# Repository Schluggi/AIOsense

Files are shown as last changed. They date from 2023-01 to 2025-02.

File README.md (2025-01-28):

# AIOsense







## Description
Based on the idea of an all-in-one sensor AIOsense was born.

The goal is to provide you with a sensor that is modular, affordable and
easy to solder (no SMD) as an alternative for commercially available sensors. We
also focus on upgrade-ability, so you don't have to buy all parts again in case
of a new PCB release. In most cases, this sensor is cheaper and better than the
commercially ones. 

## Available Sensors / Modules

- (RGB)-LED
- Barometer
- Breath VOC equivalent
- Buzzer / Beeper
- CO² equivalent
- Humidity sensor
- Light / Illumination sensor
- PIR motion sensor
- Temperature sensor
- mmWave / Radar sensor

**Coming soon:**
- Full Voice Assistant support
- Microphone
- Speaker

All supported sensors & modules are listed in the documentation:
[Sensor Modules](https://aiosense.readthedocs.io/en/latest/sensors/)

## What does it look like? 👀

| Without lid | With lid |
|---|---|
|  |  |

> **Note:** The PCB in this image is not fully equipped either is this the final case
> design ([issue](https://github.com/Schluggi/AIOsense/issues/9)).

### Rendered images

| 3D | 2D |
|---|---|
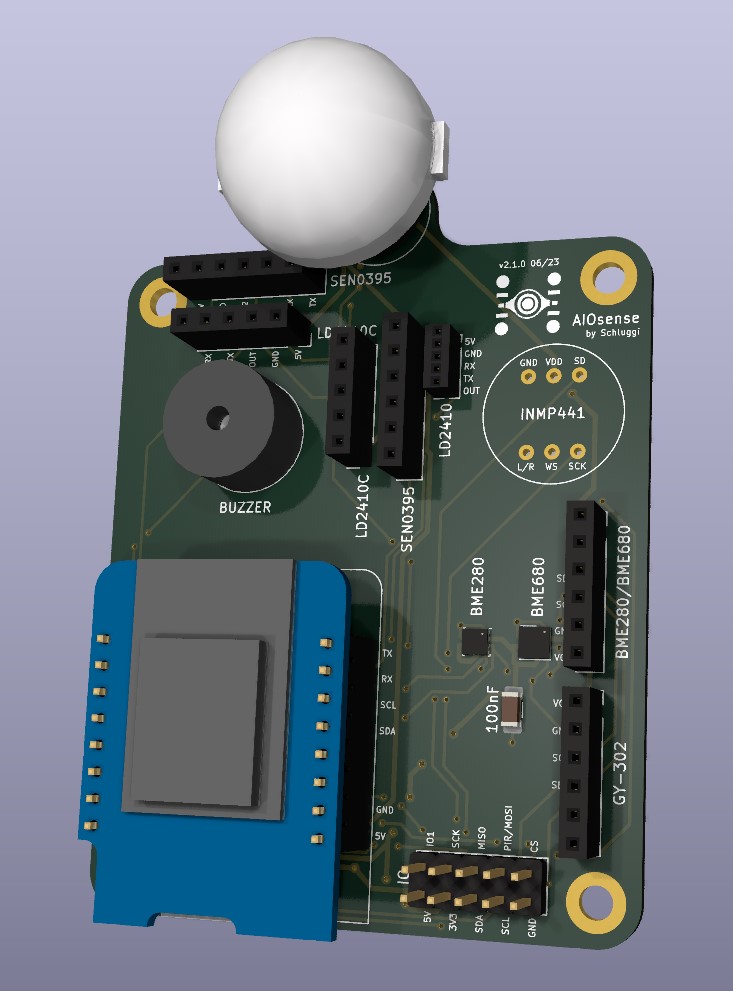
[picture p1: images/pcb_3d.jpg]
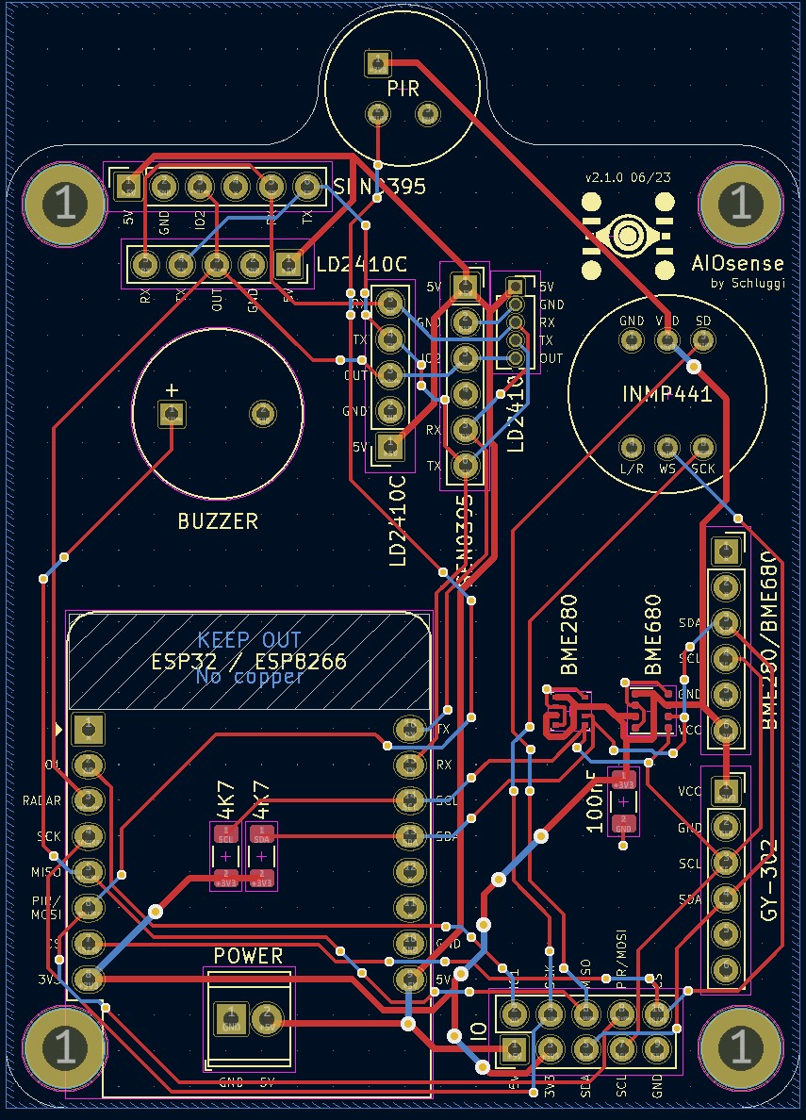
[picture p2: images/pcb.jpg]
|  |  |

### Schematic

You can find the schematic [here](schematic/AIOsense.pdf).

## Power consumption

The power consumption depends on your configuration. On a fully equipped Board (ESP32-C3 + mmWave + PIR + BME280 +
LightSensor) we measured an idle power consumption of **0.45W / 0.09A** some peaks around **0.78W / 0.15A**.

Without a mmWave sensor the idle power consumption is around **0.11W / 0.02A** and peak near **0.45W / 0.09A**.

## How to start

You want to make your own AIOsense?<br>
Let's jump right into the [documentation](https://aiosense.readthedocs.io/en/latest/quickstart/).

## Questions?

Just open an [issue](https://github.com/Schluggi/AIOsense/issues/new) :)

## Credits & Special thanks

Created and maintained by Lukas Schulte-Tickmann / [Schluggi](https://github.com/Schluggi).

### Special thanks
- My dad for some electrical engineering advice and PCB reviewing
- [lukas-holzner](https://github.com/lukas-holzner) for the case design and some general discussions about the board
- [jankae](https://github.com/jankae) for PCB reviewing
- [reschandreas](https://github.com/reschandreas) for general repo work
- [PCBWay³](https://pcbway.com/g/DFb536) for sponsoring the PCB prototypes

### Contributors
<a href="https://github.com/Schluggi/AIOsense/graphs/contributors">
  
</a>

<br>

Inspired by [EverythingSmartHome](https://everythingsmarthome.co.uk/).

<hr>
³ Affiliate link

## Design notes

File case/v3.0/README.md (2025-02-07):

# README

Please note that the ball joint components have been adapted from [Open Source Universal Ball Joint (to reuse!)](https://www.thingiverse.com/thing:4739696) and [Ball Joint Speaker Mount](https://www.thingiverse.com/thing:5429153). These models have been licensed under the [Creative Commons - Attribution - Share Alike](https://creativecommons.org/licenses/by-sa/3.0/) license.

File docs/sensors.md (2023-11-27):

# Sensors

The AIOsense PCB support and hand full of modular sensors. Chose any sensor you
want but notice the compatibility.

<hr>

## 🌡️Temperature, Humidity, Pressure, VOC & Air Quality

For these measurements we recommend the industrial sensors BME680/BME688 or the
BME280 (cheaper but without air
quality).

Please notice that you can either use the BME280 **or** the BME680 out of the
box (there have the same I²C address).

If you can solder SMD components you can solder them directly onto the PCB.
Please notice that you will need and solder
these three more components: 2x 4K7 resistor (THT), 1x 100nF capacitor (also
SMD). Also important to know: It's not
recommended to solder the BME680 with hot air because this can damage the air
quality sensor. Use a hotplate instead.

Related to [#7](https://github.com/Schluggi/AIOsense/issues/7) sometimes SMD
soldering can be inaccessible or difficult.
You can use a BME PCB module instead.

The default offset is -6 °C. 

### Where to buy?

| Part | Shops |
|---|---|
| BME280 (PCB module) | [Amazon DE³](https://amzn.to/3KXklmd), [AliExpress](https://de.aliexpress.com/wholesale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) |
| BME280 (SMD) | [Reichelt](https://www.reichelt.de/kombo-sensor-luftdruck-luftfeuchtigkeit-temp--bme-280-p159825.html), [Mouser](https://www.mouser.de/ProductDetail/Bosch-Sensortec/BME280?qs=2OnyuXx6vpj2fK9HX7qb3g%3D%3D), [Digi-Key](https://www.digikey.de/de/products/detail/bosch-sensortec/BME280/6136306) |
| BME680 (PCB module) | [Amazon DE³](https://amzn.to/41y0XmS), [AliExpress](https://de.aliexpress.com/wholesale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) |
| BME680 (SMD) | [Reichelt](https://www.reichelt.de/kombo-sensor-luftdruck-luftfeuchtigkeit-temp-gas-bme-680-p159835.html), [Mouser](https://www.mouser.de/ProductDetail/Bosch-Sensortec/BME680?qs=v271MhAjFHjo0yA%2FC4OnDQ%3D%3D), [Digi-Key](https://www.digikey.de/de/products/detail/bosch-sensortec/BME680/7401317) |

### Compatibility

This sensor is fully compatible with any other sensor or module. You can only
choose _one_ BME module and loses one
generic I²C port if you choose an PCB module.

<hr>

## 💡Illuminance (Light)

You want to turn the light on by motion but only when it's necessary? So you
want to know, how bright it is? We
recommend the really cheap GY-302 BH1750 PCB.

### Where to buy?

| Part | Shops |
|---|---|
| BH1750 | [Amazon DE³](https://amzn.to/3oAc6Vy), [AliExpress](https://de.aliexpress.com/wholesale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) |

### Compatibility

This sensor is fully compatible with any other sensor or module but uses one of
the two generic I²C slots. If you want
to use the official 3D printed case you have to connect it to the lower slot.

<hr>

## 🎙️Microphone

> **WARNING**: Not supported yet! The mic uses some SPI pins. If you want to use
> the mic you **can not** use any
> generic device connected to the these IO-header pins: CS, SCK, MISO as well as
> any SPI based sensor at all.

We designed the board while having the future in mind. So the idea to have a
microphone in each room for a voice
assistant would be awesome. Unfortunately, ESPHome does not support this
yet ([ESPHome feature request](https://github.com/esphome/feature-requests/issues/1254)).
This in mind we can't test
this at all but Open Home (the company behind ESPHome and Home Assisant)
just [release there plans](https://www.youtube.com/watch?v=D936T1Ze8-4) for 2023
and mention that there is hope this
will be implemented in the upcoming year.

The AIOsense PCB is designed to work only with INMP441-modules which are known
for their high quality digital audio.

### Where to buy?

| Part | Shops |
|---|---|
| INMP441 | [Amazon DE³](https://amzn.to/40y8twJ), [AliExpress](https://de.aliexpress.com/wholesale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) |

### Compatibility
> **AIOsense v2.1.0**: This sensor is fully compatible with any other sensor or module besides the buzzer. Please disconnect the buzzer first. 

<hr>

## 🧍Presence (mmWave/radar)

Never heard before? It's a fancy technology to recognize the smallest
movements (like a motion sensor/PIR but really
sensitive). This is useful in situations you want to track if someone is present
even if the person is not really moving
for example while watching TV or sleeping.

The board is mainly made for the
SEN0395 [datasheet](https://wiki.dfrobot.com/mmWave_Radar_Human_Presence_Detection_SKU_SEN0395).
There are two sockets
for this sensor. Feel free to choose yourself which one do you prefer. It's just
the orientation. There is no difference
between these two, and you can't use both sockets at the same time.

Shortly before release of V2.0 someone asked to support the much cheaper module
HLK-LD2410 [datasheet](https://drive.google.com/drive/folders/1p4dhbEJA3YubyIjIIC7wwVsSo8x29Fq-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).
So I added a socket. This module is also supported in ESPHome but currently
there is no demo config available from our
side. So [build it yourself](https://esphome.io/components/sensor/ld2410.html).

### Where to buy?

| Part | Shops |
|---|---|
| SEN0395 (recommended) | [Mouser](https://www.mouser.de/ProductDetail/DFRobot/SEN0395?qs=ljCeji4nMDmvEgq75EdCVA%3D%3D), [Farnell](https://de.farnell.com/en-DE/dfrobot/sen0395/mmwave-radar-board-arduino-board/dp/3879712), [Digi-Key](https://www.digikey.de/de/products/detail/dfrobot/SEN0395/14322660?s=N4IgTCBcDaIMoFEByAGAzATgKwgLoF8g) |
| HLK-LD2410 | [AliExpress](https://de.aliexpress.com/item/1005004351593073.html) |
| HLK-LD2410C | [AliExpress](https://de.aliexpress.com/item/1005005047841163.html) |

### Compatibility

This sensor is fully compatible with any other sensor or module, but you can
only use one of them so choose wisely.

<hr>

## 🚶Motion Sensor (PIR)

You want a classic motion sensor? No problem. We support an industrial standard
EKMC1603111 ([Datasheet](https://www3.panasonic.biz/ac/ae/search_num/index.jsp?c=detail&part_no=EKMC1603111)).
Every
other 3V PIR sensor with an TO-5 3-pin socket should work as well (but is
untested).
Please notice that you will need an TO-5 3-pin socket as well (in any case)!

### Where to buy?

| Part | Shops |
|---|---|
| EKMC1603111 | [Voelkner](https://www.voelkner.de/products/994091/Panasonic-PIR-Bewegungssensor-EKMC1603111-3-6V-1St..html), [Mouser](https://www.mouser.de/ProductDetail/Panasonic-Industrial-Devices/EKMC1603111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), [Farnell](https://de.farnell.com/en-DE/panasonic-electric-works/ekmc1603111/sensor-motion-12m-white/dp/2095731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), [Digi-Key](https://www.digikey.de/de/products/detail/panasonic-electric-works/EKMC1603111/2601880), [RS-Online](https://de.rs-online.com/web/p/naherungssensoren-ics/1357081) |
| TO-5 3-pin socket | [Mouser](https://www.mouser.de/ProductDetail/Mill-Max/917-43-103-41-005000?qs=teNCaa%2FZ3auQVxVMs%2F5ihg%3D%3D), [Digi-Key](https://www.digikey.com/en/products/detail/mill-max-manufacturing-corp/917-43-103-41-005000/1212170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) |

### Compatibility

This sensor is fully compatible with any other sensor or module.

## 🔊 Piezo Buzzers

This is a passive buzzer which can create music in different frequencies.

### Where to buy?

| Part | Shops |
|---|---|
| Piezo Buzzer | [Amazon DE³](https://amzn.to/3n0aFza), [Mouser](https://www.mouser.de/ProductDetail/CUI-Devices/CEM-120342?qs=WyjlAZoYn50KzVdoYfaqpA%3D%3D) |

> Please notice the pinout of 6.5mm and a max height of 8.5mm. Otherwise, the
> buzzer will not fit

### Compatibility

This module is fully compatible with any other sensor or module besides
HLK-LD2410. The HLK-LD2410C however will work fine.

<hr>
³ Affiliate link

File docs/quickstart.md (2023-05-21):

# Quickstart



> **Note:** You can also buy AIOsense as a kit
> on [tindie](https://www.tindie.com/products/gadgetgarage/aiosense/).

## Order PCB

(https://www.pcbway.com/project/shareproject/AIOsense_All_In_One_Sensor_132c1507.html)

First of all you need the PCB. We recommend PCBWay because it's the most
straight forward experience and the quality is excellent. Just click on the link
and take your order (you can also use [this link³](https://pcbway.com/g/DFb536)
for register to get 5$ off on your first order). But you can actually choose any
PCB manufacturer. Please notice that not all of them have the same capabilities.
We tried to make our PCB as generic as possible, it should work for most of them
but try this at your own risk.

- [PCBWay³](https://www.pcbway.com/project/shareproject/AIOsense_All_In_One_Sensor_132c1507.html)
- [Aisler](https://aisler.net/p/TWDRHBSM)

For all other manufacturer (like [JLCPCB](https://jlcpcb.com/)) please upload
the zip file which you can find at
the [release](https://github.com/Schluggi/AIOsense/releases/latest) page.

## Order parts

Now that you have the PCB, we still need the remaining parts. There is a
separate [BOM (Bill Of Materials)](https://github.com/Schluggi/AIOsense/tree/main/bom)
for
each AIOsense version. Open the pdf file and order all green marked lines.

You can get most parts from sellers
like [Mouser](https://www2.mouser.com/), [Farnell](https://www.farnell.com/)
or [Digi-Key](https://www.digikey.com/). Direct links to the sensors can be
found [here](sensors.md).

Please make sure you pick the right BME680 module. It should look like
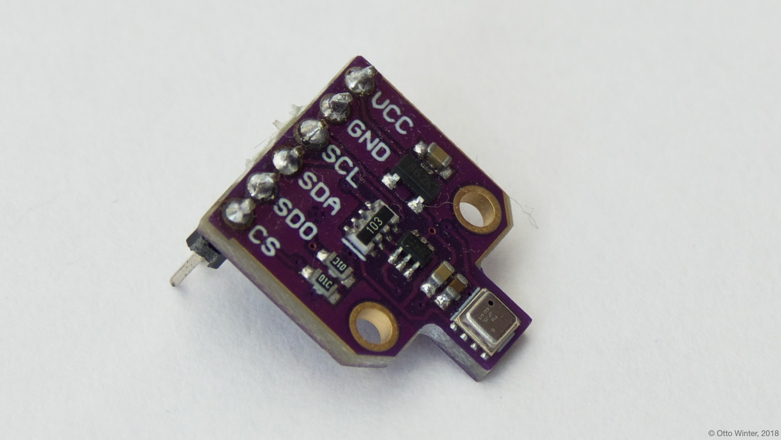
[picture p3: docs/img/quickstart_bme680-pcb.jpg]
bme680-pcb
this: {: style="height:50%;width:
50%"}

More info about the BOM and what the groups are all about can be
found [here](bom.md).

## Assembly (wip)

Should be easy and self explainable.

## Flashing Firmware

Now you have a fully assembled AIOsense but how can you integrate this in
Home Assistant?

### Installing the ESPHome dashboard

> This will only work for _Home Assistant OS_ and _Supervised_. For all other
> versions please use the
> [docker image](https://esphome.io/guides/getting_started_command_line.html#)
> or install it [manually](https://esphome.io/guides/installing_esphome.html).

First we need an ESPHome Dashboard. The best way to get one is by using the
official Home Assistant add-on.

Therefore, we go to our Home Assistant instance and click
on `Settings -> Add-ons`:

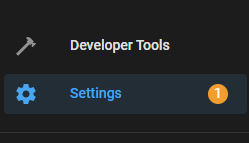
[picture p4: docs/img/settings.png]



We can find the `ADD-ON STORE` in the bottom right corner:



We are looking for the ESPHome add-on (without beta and dev) and install it.
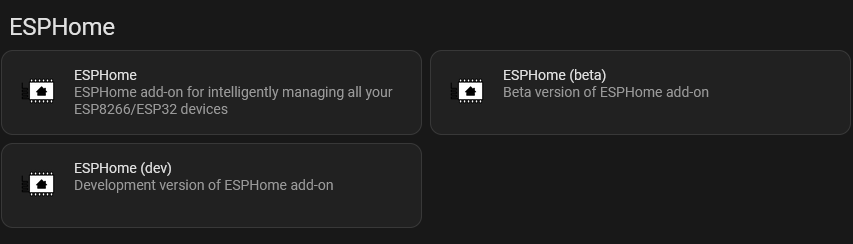
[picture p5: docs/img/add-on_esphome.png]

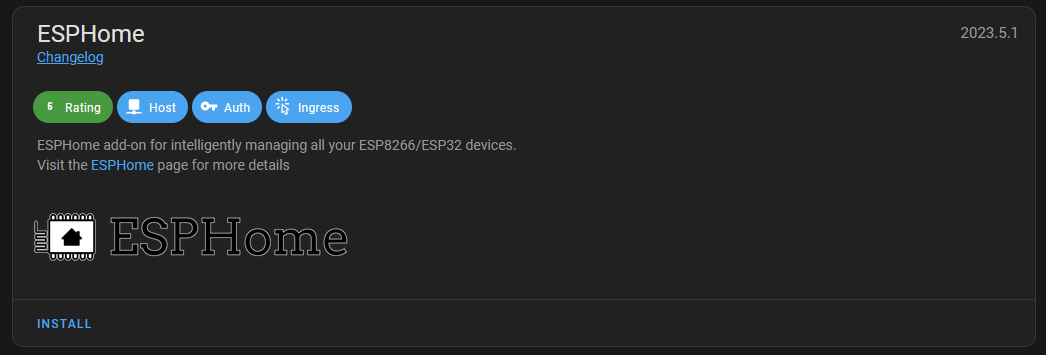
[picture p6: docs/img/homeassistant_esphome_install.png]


The installation can take several minutes, so please be patient. Afterward we
enable `Start on boot`, `Auto update` and `Show in sidebar`.


We can now open our dashboard by clicking on it at the sidebar:
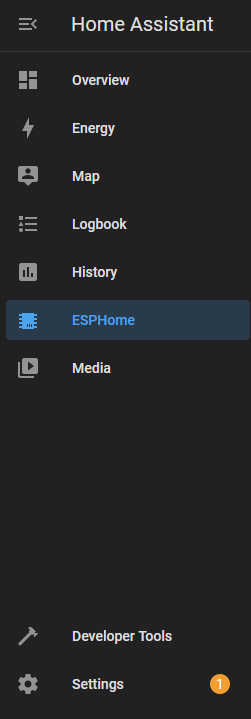
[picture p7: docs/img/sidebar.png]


### Flashing

With an open dashboard we can now flash our device, but first we need some
configuration.

Click `New Device` and fill out the form:

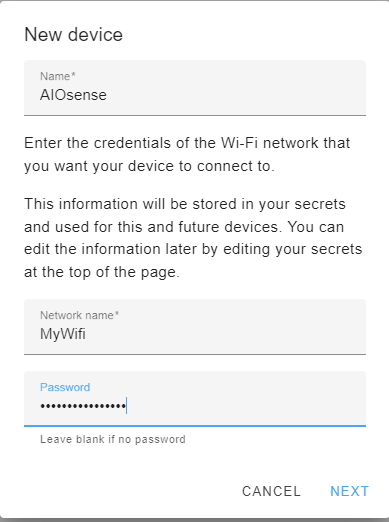
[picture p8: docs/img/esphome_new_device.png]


Skip the installation on the second screen and choose the ESP32-C3.

We don't need the encryption key yet. Skip it.

Our device is now displayed on the dashboard. You need to change the
configuration. Click `EDIT`.

This is the configuration that will be flashed onto your device. We need nothing of
this but the api encryption key and the ota password so copy/save these values
for later.

Replace the hole file with the content of
[this](https://github.com/Schluggi/AIOsense/blob/main/esphome/esphome.yaml)
file and replace both `<secret>` values with your saved ones and change lines
2-4 to the name you pick earlier.

Everything changed? Great! If not already done, connect the board via USB to
your PC, click `INSTALL` in the top right corner and
select `Plug into this computer` as flashing method.

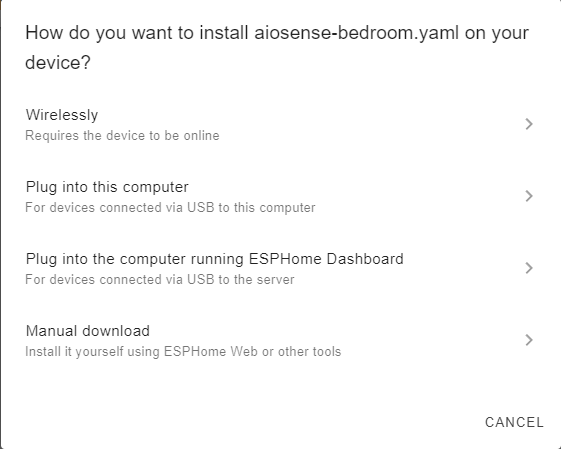
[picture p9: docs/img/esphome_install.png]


> This will only work on a Chromium based browser. For all other browser please
> take a look how to flash manually

A popup will ask for the COM port. Select the port of the board and click
`Connect`.

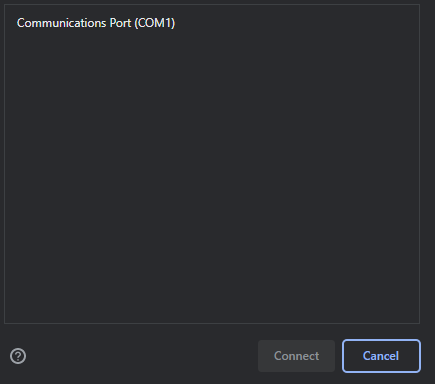
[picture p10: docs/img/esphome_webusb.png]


Your browser will now connect to your board and flash it. This can take several
minutes. The blue circle will spin without any additional feedback. Be patient.

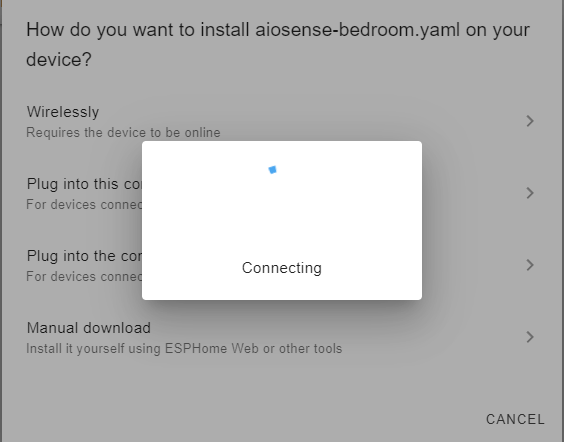
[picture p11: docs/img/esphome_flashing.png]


Your AIOsense is now ready to use

## Home Assistant Integration (wip)

...

## Further steps (optional)

- [Print a case](case.md)

<hr>
³ Affiliate link

My PCB prototypes are sponsored by PCBWay.

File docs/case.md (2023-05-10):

# Case

We and our communtiy desigend a few 3D printable cases.

| AIOsense | Author | Link | Note |
|---|---|---|---|
| v2.x.x | [MeisterGig](https://github.com/MeisterGig) | [Printables](https://www.printables.com/de/model/477959-aiosense-case-official) | **Official Case**, no heat inserts or screws needed ([#9](https://github.com/Schluggi/AIOsense/pull/9)) |
| v2.x.x | [cadriel](https://github.com/cadriel) | [Printables](https://www.printables.com/de/model/477959-aiosense-case-official) | Remix of the official case, screws needed ([#9](https://github.com/Schluggi/AIOsense/issues/9#issuecomment-1513696294)) |
| v1.0 | [s-gordon](https://github.com/s-gordon) | [Repo](https://github.com/Schluggi/AIOsense/tree/main/case/v1.0/stl) | [#16](https://github.com/Schluggi/AIOsense/pull/16) |

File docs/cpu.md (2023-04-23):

You can use any ESP32 mini or ESP8266 mini with the correct pinout, but we highly recommend the ESP32-C3.

| | ESP32-C3 (recommended) | ESP32 | ESP32-S2 | ESP8266 |
|---|---|---|---|---|
| USB-Type | Type-C | micro-USB | Type-C | micro-USB or Type-C |
| Bluetooth | &check; | &check; | &check; | &cross; |
| Bluetooth LE | &check; | &check; | ? | &cross; |
| Case | &check; | &cross;(not yet) | &check; | &check; |
| external power¹ | &check; | &check; | &check; | &cross; |
| LED | WS2812B RGB | White | White | White |
| fits perfectly  | &check; | [stands over](https://github.com/Schluggi/AIOsense/issues/15#issuecomment-1399424459) | &check; | &check;¹ |
| Where to buy? | [AliExpress](https://de.aliexpress.com/item/1005004740051202.html?gatewayAdapt=glo2deu) | [Amazon DE³](https://amzn.to/3Loijgf), [AliExpress](https://de.aliexpress.com/item/32858054775.html) | [AliExpress](https://de.aliexpress.com/item/1005003145192016.html?gatewayAdapt=glo2deu) | [Amazon DE³](https://amzn.to/43ZNANZ), [AliExpress](https://de.aliexpress.com/item/32529101036.html) |

¹ External power via the terminal connectors are not possible if the USB-connector is at the bottom (ESP8266).

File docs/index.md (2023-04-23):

# AIOsense documentation



Welcome to the [AIOsense](https://github.com/Schluggi/AIOsense) documentation.

If you miss some information or spot something wrong / outdatet feel free to create
an [issue](https://github.com/Schluggi/AIOsense/issues/new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).

Start with our [quickstart](quickstart.md) guide.

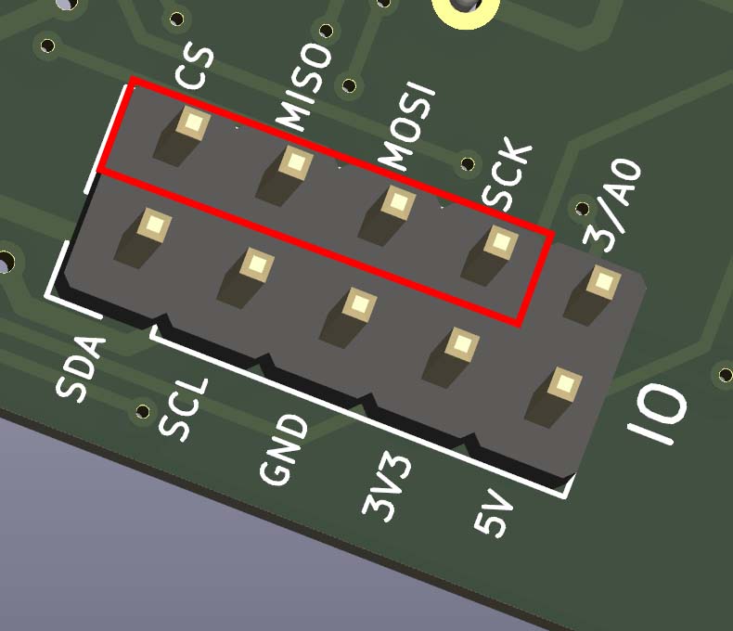
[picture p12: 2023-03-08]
images/docs/io-spi.jpg

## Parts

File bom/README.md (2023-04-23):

# BOM (Bill of Material)

Please take a look at our [docs](https://aiosense.readthedocs.io/en/latest/bom)
for complete BOM explanation. There is also
a [quickstart guide](https://aiosense.readthedocs.io/en/latest/quickstart/).

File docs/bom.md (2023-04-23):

# BOM (Bill Of Materials)

You can find the BOM [here](https://github.com/Schluggi/AIOsense/tree/main/bom).

You can get most parts from sellers
like [Mouser](https://www2.mouser.com/), [Farnell](https://www.farnell.com/)
or [Digi-Key](https://www.digikey.com/). Direct links to the sensors can be
found [here](sensors.md).

## Quickstart recommendation

Some lines in the BOM are marked green. This is our quickstart recommendation.
So if you don't know what do you really need and what is optional, just buy all
parts that are marked green, and you will end with an uncompromising AIOsense.

## Groups

Some parts in the BOM have a group letter. These are alternative options. So
please choice only one part within one group. For example both mmWave sensors
are in group `M`. So you have to pick one of them and can't use both at the same
time.

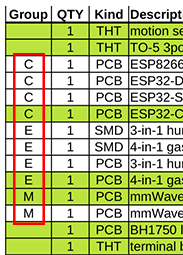
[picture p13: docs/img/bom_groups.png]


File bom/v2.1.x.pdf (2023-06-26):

AIOsense

https://github.com/Schluggi/AIOsense

BOM for v2.1.x only
Please take a look at our docs for complete BOM explanation
Group | QTY | Kind | Description | Note | Manufacturer | SKU
| 1 | THT | motion sensor / PIR | - | Panasonic | EKMC1603111
| 1 | THT | TO-5 3pos socket | - | Mill-Max | 917-43-103-41-005000
C | 1 | PCB | ESP8266-D1 mini | - | Wemos | Lolin D1 mini
C | 1 | PCB | ESP32-D1 mini | - | (many) | -
C | 1 | PCB | ESP32-S2 mini | - | Wemos | Lolin S2 mini
C | 1 | PCB | ESP32-C3 mini | - | Wemos | Lolin C3 mini
E | 1 | SMD | 3-in-1 humidity sensor | - | Bosch | BME280
E | 1 | SMD | 4-in-1 gas sensor | - | Bosch | BME680
E | 1 | PCB | 3-in-1 humidity sensor | - | (many) | BME280
E | 1 | PCB | 4-in-1 gas sensor | - | (many) | BME680
M | 1 | PCB | mmWave radar sensor | - | DFROBOT | SEN0395
M | 1 | PCB | mmWave radar sensor | - | Hi-Link | HLK-LD2410
M | 1 | PCB | mmWave radar sensor | - | Hi-Link | HLK-LD2410C
| 1 | PCB | BH1750 light sensor | - | (many) | GY-302
| 1 | THT | terminal block 2pos, 2.54mm pin spacing, 8.5mm case height | - | Würth Elektronik | 691210910002
| 2 | SMD | 4.7 kohm resistors, ± 5%, 1206, 250 mW | only if group E is SMD | YAGEO | RC1206JR-074K7L
| 1 | SMD | multilayer ceramic capacitor, 0.1 µF, 50 V, ± 10%, 1206, X7R | only if group E is SMD | YAGEO | CC1206KRX7R9BB104
| 4 | THT | 1x6-way vertical socket (female), 2.54mm, 8.5mm height | - | MULTICOMP PRO | 2212S-06SG-85
| 2 | THT | 1x8-way vertical socket (female), 2.54mm, 8.5mm height | normaly part of the CPU order | MULTICOMP PRO | 2212S-08SG-85
| 1 | THT | 2x5-way vertical header (male), 2.54mm | - | MULTICOMP PRO | 2213S-10G
| 2 | THT | 1x5-way vertical socket (female), 2.54mm, 8.5mm height | for HLK-LD2410C only | MULTICOMP PRO | 2212S-05SG-85
| 1 | THT | 1x5-way vertical socket (female), 1.27mm, 4.6mm height | for HLK-LD2410 only | Harwin | M52-5000545
| 1 | THT | Piezo Buzzers, 12mm radius, 8.5mm height, 6.5mm pinout | - | CUI Devices | CEM-1203(42)
| 1 | PCB | microphone | not supported yet | (many) | INMP441

THT

SMD
PCB

The green color indicates the parts you need for a fully equipped PCB if you want plug and play (quickstart recommendation).

stands for "Through-Hole Technology". Electronic components with leads inserted in holes, soldered on opposite side. Soldering is done via A soldering iron. TLDR; easy to solder.
stands for „Surface Mount Device“. Electronic components mounted directly onto circuit board surface using solder paste and reflow Soldering. Soldering is done using a hot air or reflow soldering machine. TLDR; difficult to solder.
stands for „Printed Circuit Board“. In this case THT based circuit boards. Sometimes called „pcb modules“. TLDR; easy to solder.

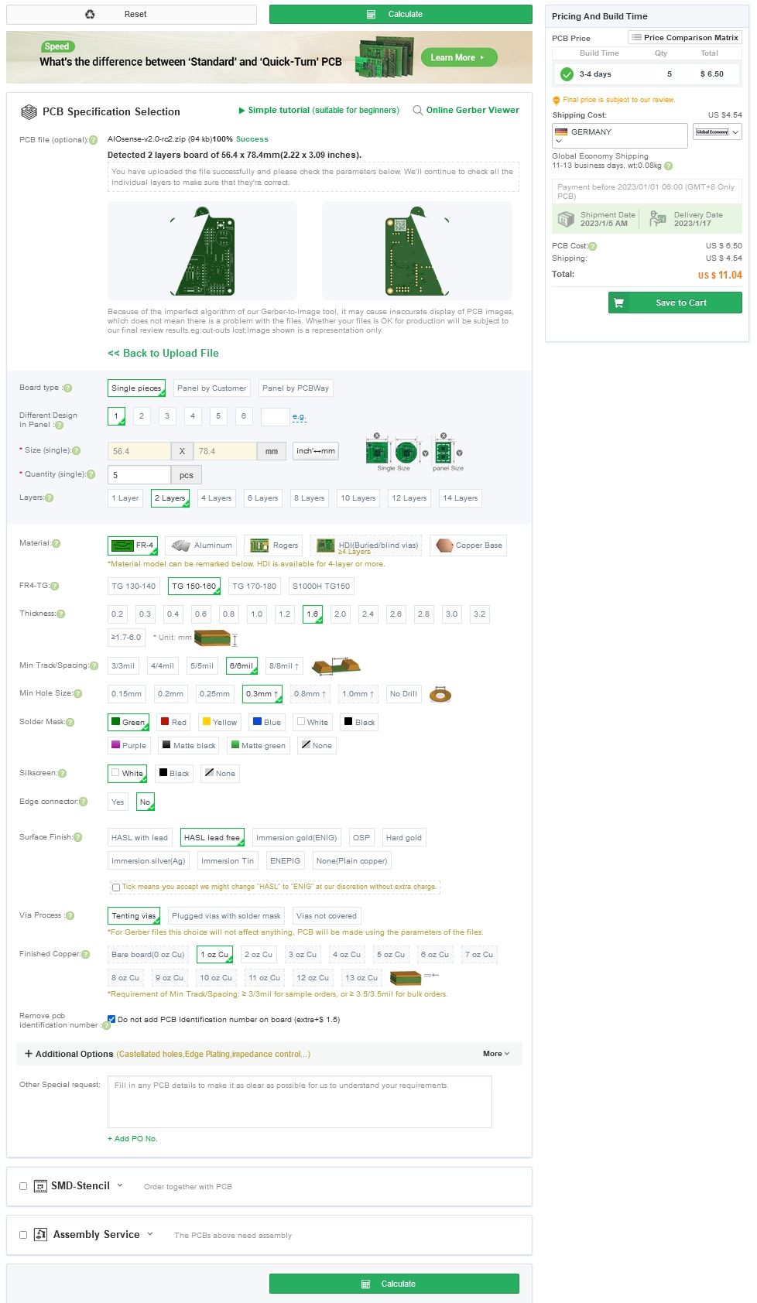
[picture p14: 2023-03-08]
images/docs/order_pcbway.jpg

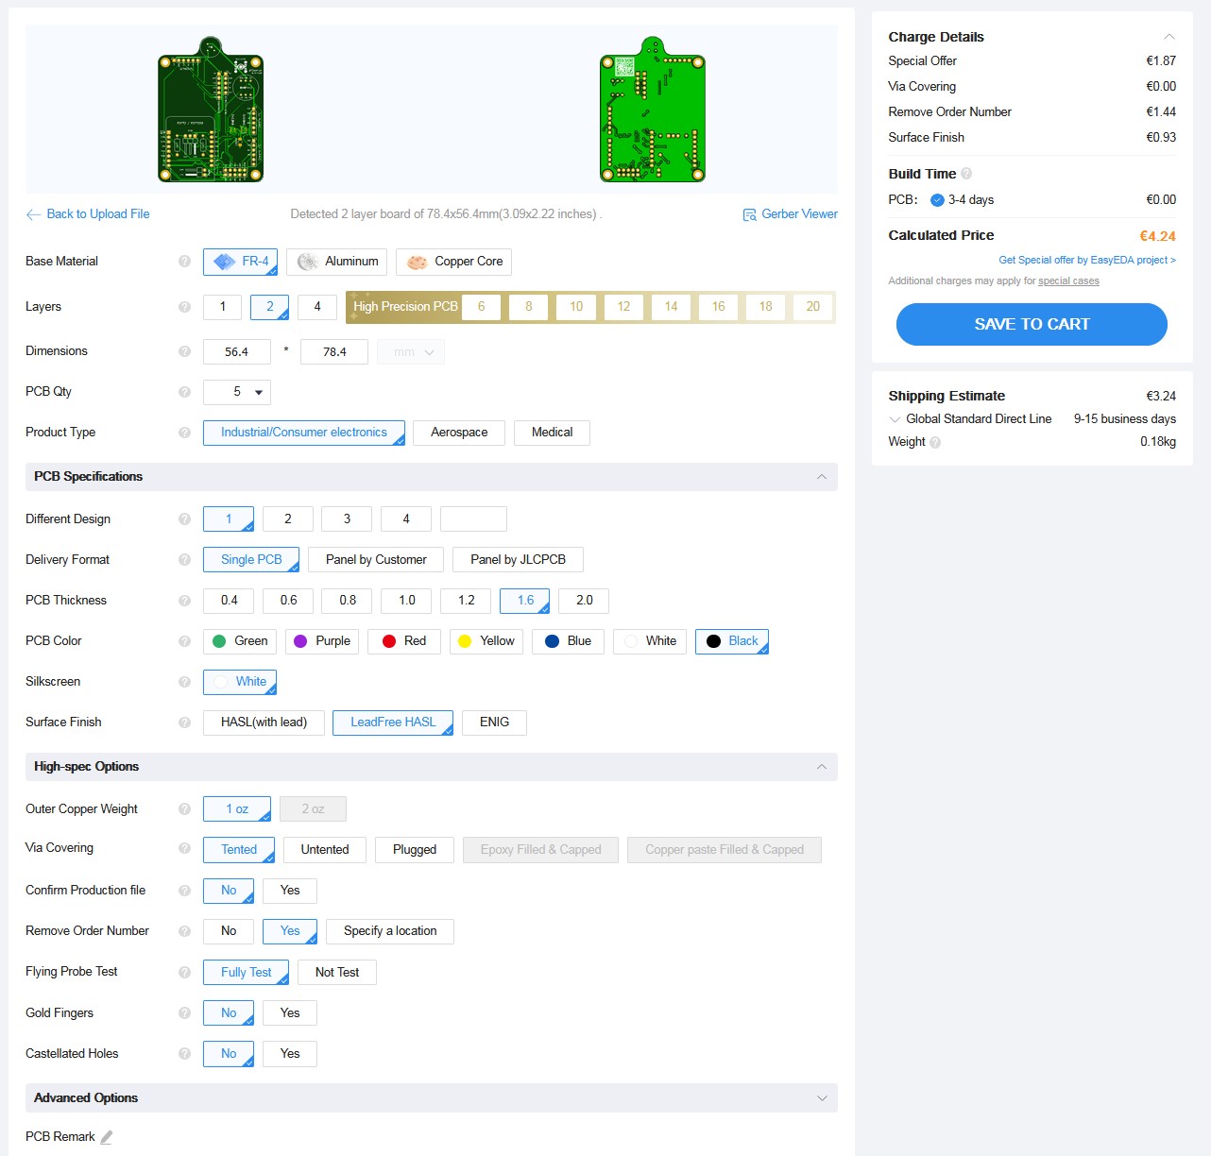
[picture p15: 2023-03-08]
images/docs/order_jlcpcb.jpg

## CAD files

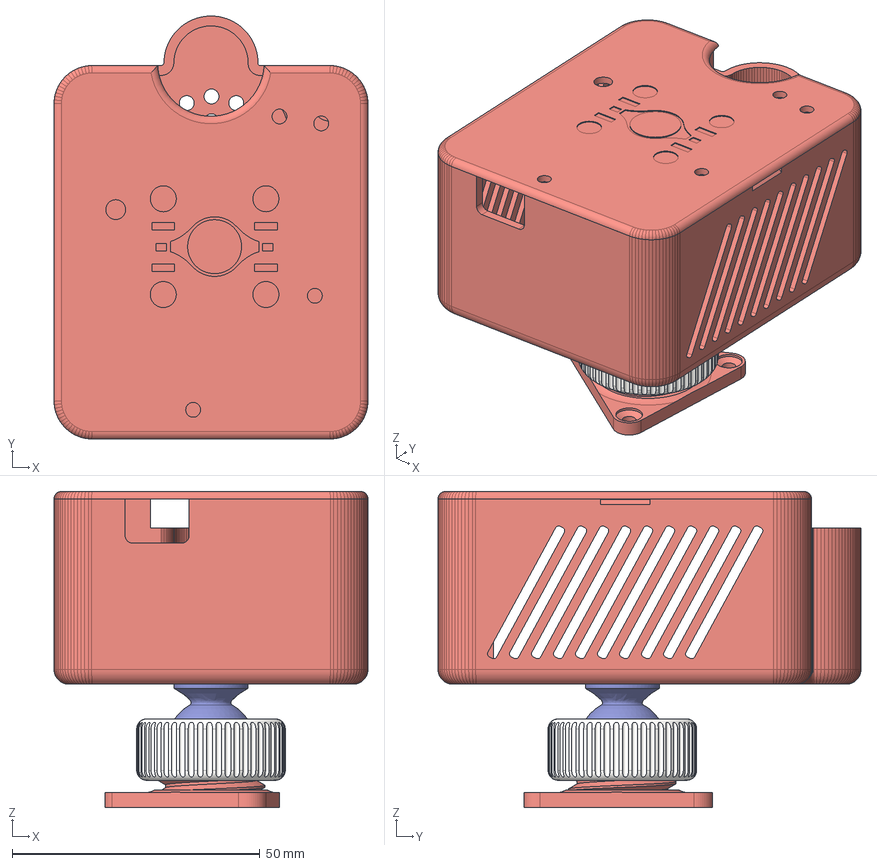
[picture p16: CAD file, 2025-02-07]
case/v3.0/step/case.step
63.4 x 85.4 x 63.8 mm
Ball
Bottom
Lid

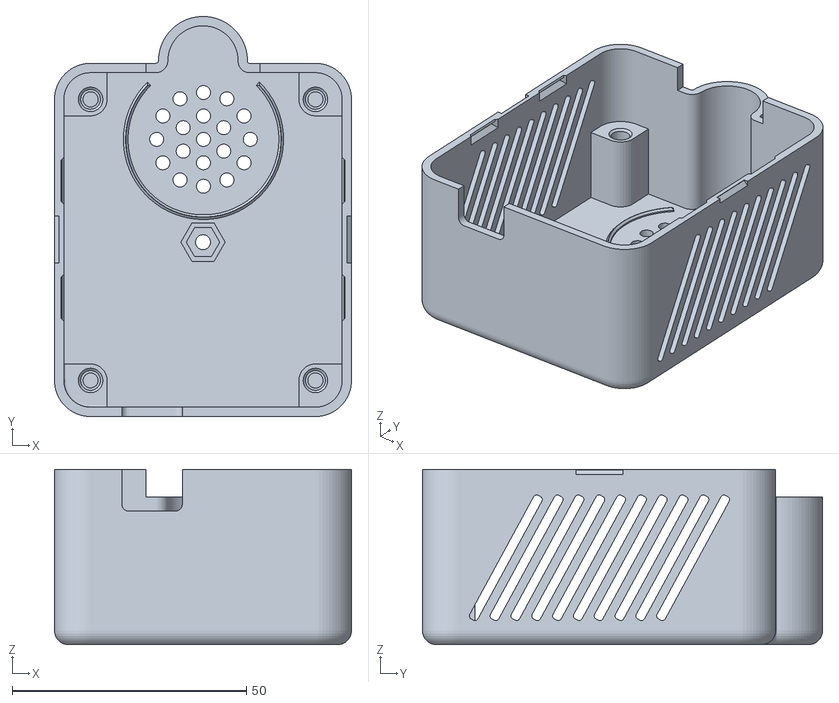
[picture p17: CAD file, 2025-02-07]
case/v3.0/stl/bottom.stl
63.4 x 85.4 x 37.4

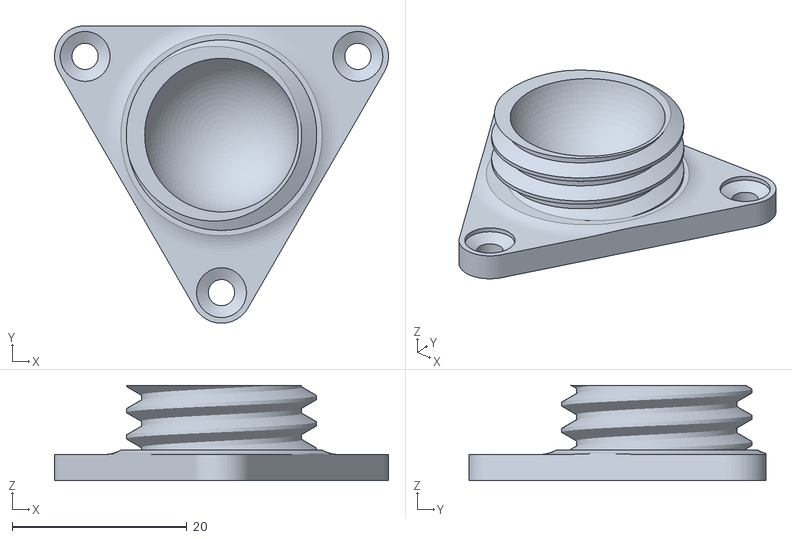
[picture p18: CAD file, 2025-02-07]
case/v3.0/stl/ball_base.stl
38.2 x 34.0 x 10.9

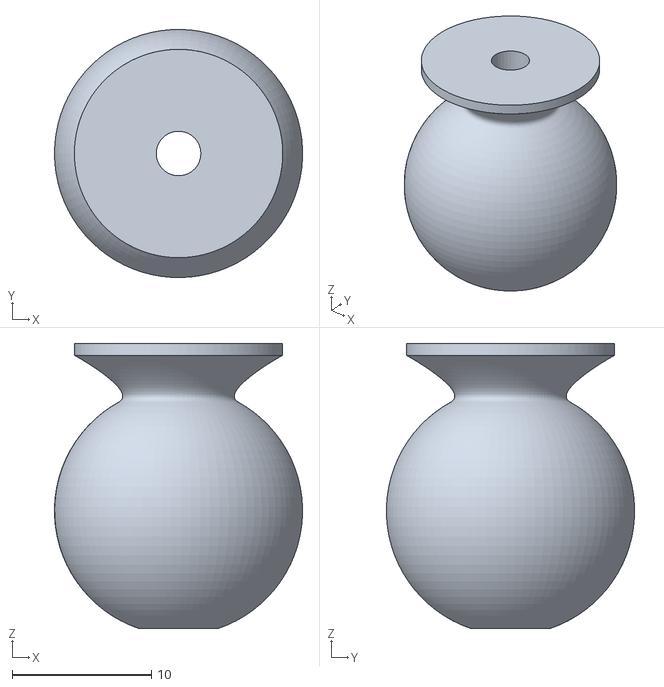
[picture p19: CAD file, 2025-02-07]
case/v3.0/stl/ball.stl
17.8 x 17.8 x 20.4

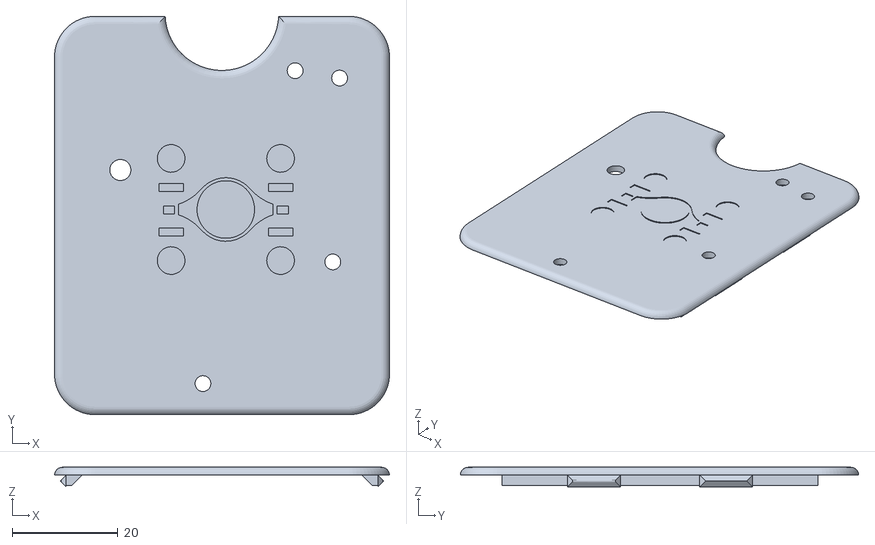
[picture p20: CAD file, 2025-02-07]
case/v3.0/stl/lid.stl
63.4 x 75.4 x 3.70

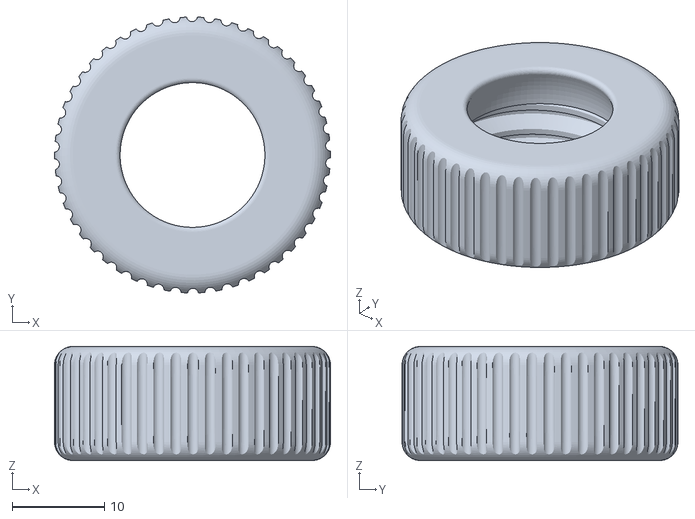
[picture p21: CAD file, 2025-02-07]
case/v3.0/stl/nut.stl
30.0 x 30.0 x 12.4

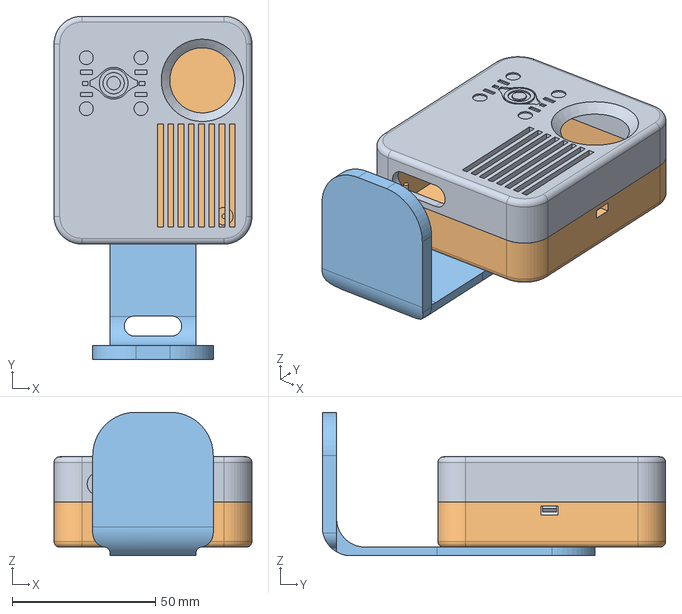
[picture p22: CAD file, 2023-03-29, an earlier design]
case/v1.0/step/case.step
69.0 x 119.7 x 50.0 mm

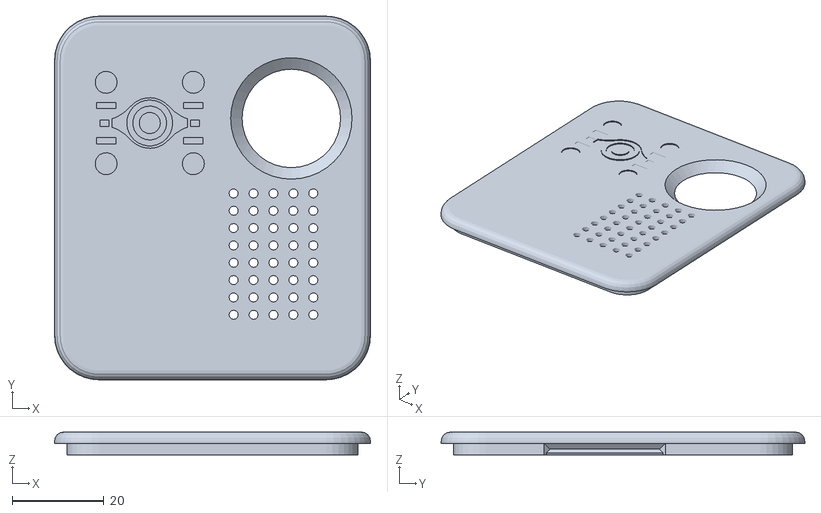
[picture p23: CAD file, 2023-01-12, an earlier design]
case/v1.0/stl/top.stl
69.0 x 79.4 x 5.00

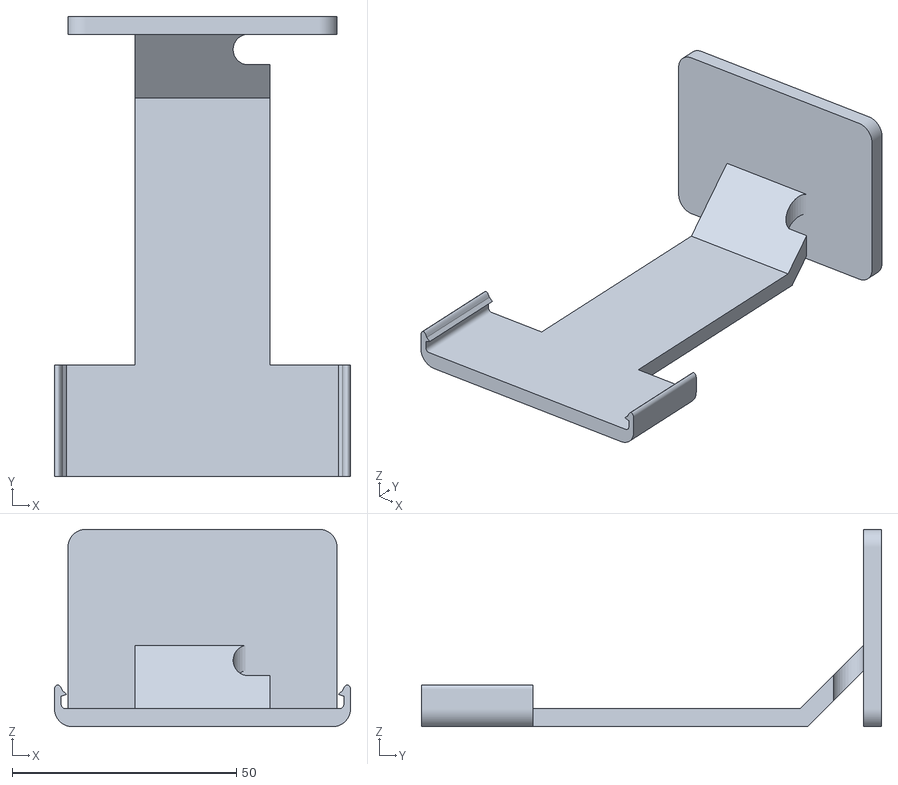
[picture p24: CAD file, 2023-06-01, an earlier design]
case/v2.0/stl/case_upright_stand.stl
66.0 x 102.5 x 44.0

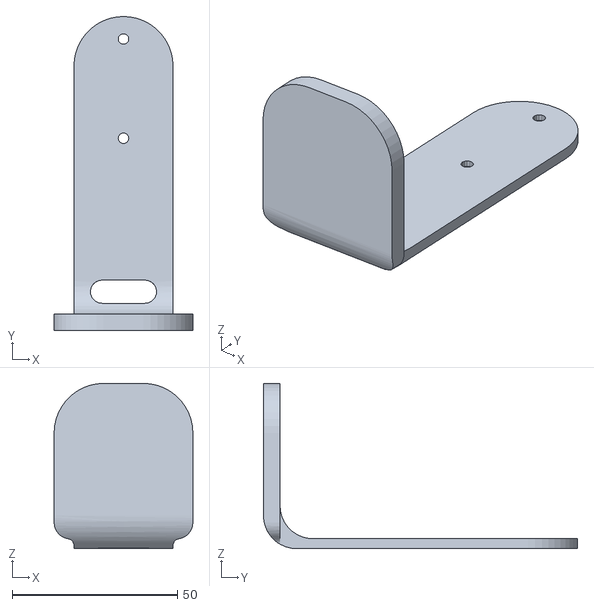
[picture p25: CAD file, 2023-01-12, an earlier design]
case/v1.0/stl/stand.stl
42.0 x 95.0 x 50.0

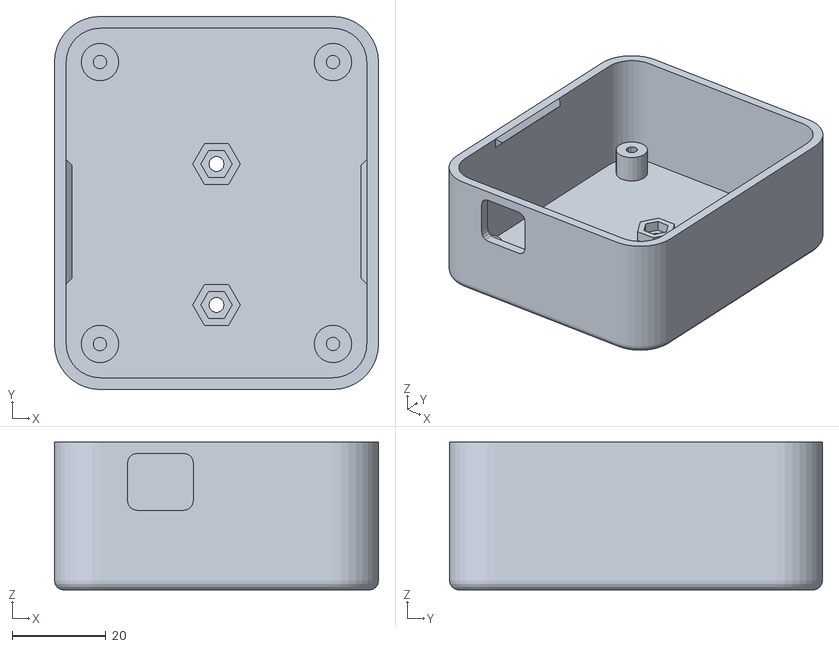
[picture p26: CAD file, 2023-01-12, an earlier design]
case/v1.0/stl/bottom.stl
69.0 x 79.4 x 31.5

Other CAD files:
case/v2.0/blender/case_upright_stand.blend

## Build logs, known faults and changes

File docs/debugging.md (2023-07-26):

# Debugging

## Inconsistent I²C readings

### I²C frequency

A first quick fix could be to choose a lower I²C frequency. In some cases this
can already help to improve consistently
readings. You can do this by tweaking your yaml file and add a `frequency`.

```yaml
i2c:
  frequency: 10kHz  # (defaults to 50kHz)
```

### Too many pull-up resistors ([#44](https://github.com/Schluggi/AIOsense/issues/44))

We need I²C pull-up resistors to make I²C to work. But since every module has
their own pull-ups, we're ending up with
too many pull-ups which can resolve in bad readings. This normally only happens
if you had soldered the two 4K7 Ohm
resistors and using the BME-Module (not the SMD version) as well as the
Light-Module.

The fix is easy: Remove both 4K7 Ohm resistors from the PCB.

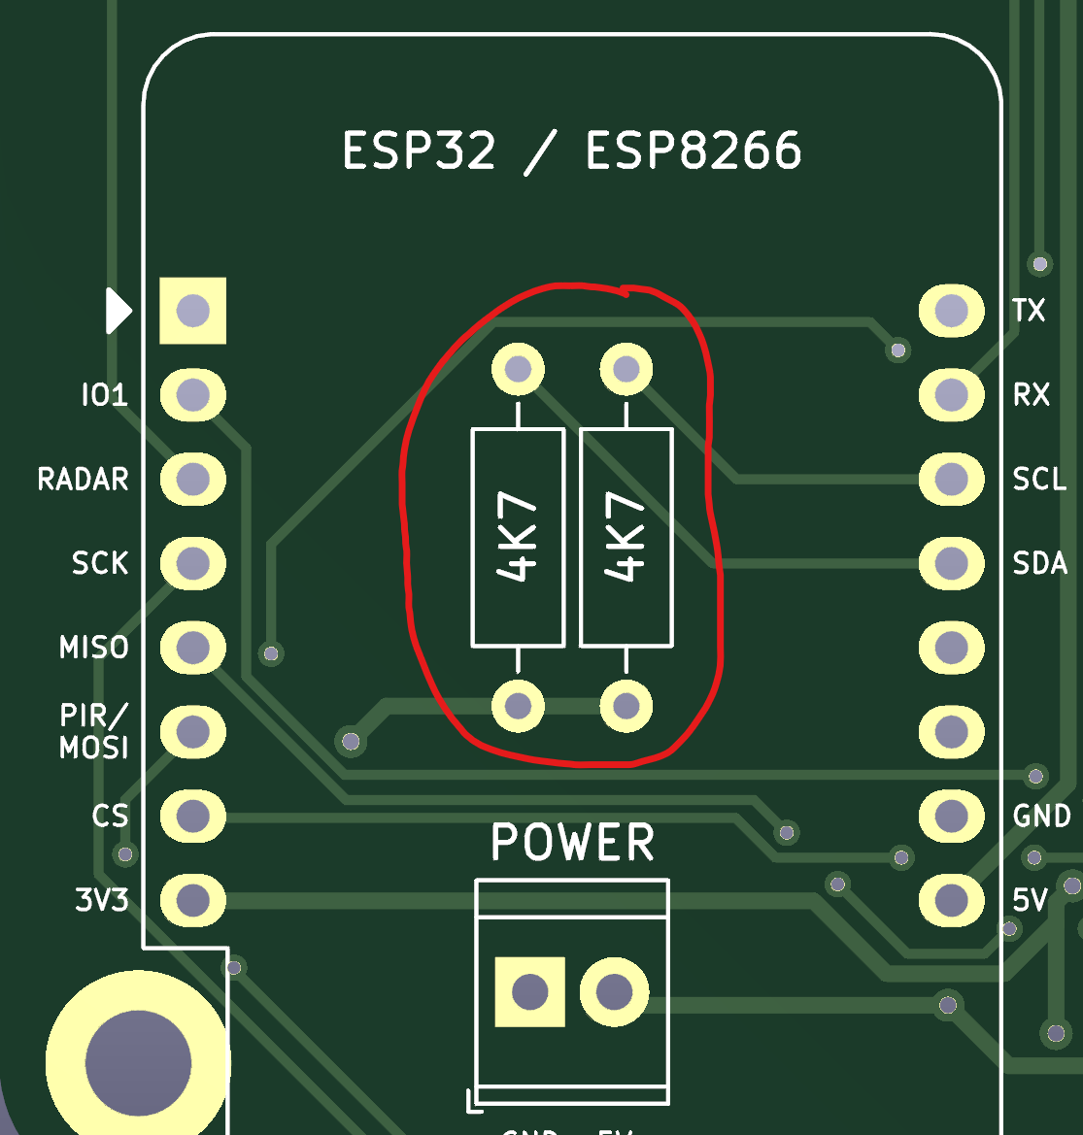
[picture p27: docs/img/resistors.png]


## LD2410(c) does not work

Some versions of LD2410 and LD2410C behave somewhat peculiarly. If your ESP
cannot establish a connection to the mmWave module, it may help to swap the RX
and TX pins contrary to their labeling. To do this, simply adjust your ESPHome
config accordingly.

```yaml
# In this example, the pins are already swapped.
substitutions:

  # ESP32-C3 mini
  uart_rx_pin: GPIO21
  uart_tx_pin: GPIO20

  # ESP32-D1 mini
  uart_rx_pin: GPIO1
  uart_tx_pin: GPIO3

  # ESP32-S2 mini
  uart_rx_pin: GPIO39
  uart_tx_pin: GPIO37

  # ESP2866-D1 mini
  uart_rx_pin: GPIO1
  uart_tx_pin: GPIO3
```

Source: https://github.com/esphome/issues/issues/4317#issuecomment-1474937332

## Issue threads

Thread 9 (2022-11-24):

Design a 3D printable case for v2.0.x and v2.1.x

Schluggi, 2022-11-24:

s-gordon, 2022-12-31:
Great work on the project all. I've actually designed a 3D-printable case for the board. Let me know if you're interested and I'd be happy to share.

MeisterGig, 2022-12-31:
Hey @s-gordon,
we are also working on a Case for v2.0. I haven't posted it yet, since the PCB footprint is still not totally final. We are soon going to order an other batch of PCBs and hope to have a final version with case, to release.
In the meanwhile, here is a link to the WIP Case. https://cad.onshape.com/documents/0970230d187b540faa10c45f/w/4e628c030e78246416c5e857/e/a4e55bb6f45b9b87b321fa69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

The case is supposed to have an assortment of mounting options available, which can be extended apon.

If you have a case for V1, please feel free to open a pull request so we can also offer an option for that. I am also open to improvement ideas :)

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

MeisterGig, 2022-12-31:
TODOs for the case until the release:
- [ ] Adjust to new footprint
- [ ] Make it thinner
- [ ] Get more light to the light sensor (might be solved by making the case thinner)
- [ ] Have a drawing for measurements for the mounting plate

cptbucky, 2023-03-20:
Excited for this, will get a 3d printer when it's ready to go 😁

cadriel, 2023-03-27:
It'd be great to see some further progress here;

- The lid doesn't appear to have a way  to attach to the case.
- The standing mount requires supports. It'd be better to have this printable without supports in some way.

MeisterGig, 2023-03-28:
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

The lid has ha notch which locks into place when pushing it in. And Yes the standing mount still needs support.

I have been refining the design after the official release of the V2.0 board. I'll follow up with further information soon.

afp316, 2023-03-30:
@Schluggi @MeisterGig Thank you for taking the time and effort to create this project.

I printed the WIP V2 case to trial fit.  Good news is that the board fit in the case perfectly.
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

I know that it's still in progress but just wanted to provide some feedback.  The lid doesn't have an interference fit so it won't stay in place without some kind of adhesive.  The corner wall mount should also be scaled a bit down to allow for a snap fit.

Did anyone else have issues or am I doing something wrong on the printing side of things?

Thanks!

MeisterGig, 2023-03-30:
Hey @afp316 ,
Thank you for your input :)  I also encountered problems with the lid. I inverted the notch on the lid and the case after the v2.0 rc1 because it was making it harder to get the board in and out of the case. I haven't  been able to get it as nicely  fit together as the previous version yet. Also i have resized the case recently and might have forgotten the mounts.

I'm gonna share some design considerations and problems i have encountered so far:
- The case should be modular
- It needs to have good ventilation for the bme both smd and recently also as a module (still working on that one )
- the light sensor needs to be as close to the lid as possible otherwise it won't get enough light or i need giant hole
- I personally like heat insert, but it was requested to not need any screws or heat inserts, because it looks bad and insert might be hard to get
- the PCB is very modular so it's hard to design a one size fits all case
-  the PCB should be easily taken out of the case
- when the case is closed it should fit securely inside the case
- pin headers have different hights (i have encountered 7, 8 an 8.5 mm versions)
- ESP8266 have there ports monted on the bottom esp32 on the top
- some people might want to supply power using the scre terminals below the mcu (i don't like a giant hole in the bottom)
- long pins on the lid to hold the board in place break off easily as to many screless locking mechanisms
- it should also look good

I was discussing with @Schluggi to maybe enforce one size of pin header and also maybe use heat inserts to mount the PCB. What are your thoughts on this :)

cadriel, 2023-03-30:
- Most of the pin headers i've encountered are 8.5mm. I don't think I've ever had anything else less than that.
- The more BOM items you add, the harder it is for people to source. Heat Inserts are a bit more difficult to find than screws. I've seen a bunch of cases that use screws as an option so it might be worth considering if you're having trouble. Remember - you can screw into plastic without the need of a heat insert, too.

IMO - It's going to be super hard to meet the needs of every single variation.

If you standardise the pin headers at 8.5mm (this seems the most common option) and start with supporting the recommended `S3` mcu - along with both the smd and pcb modules - then once you've sorted that, move on to variations. Perhaps you provide multiple case options for the different MCU's for example - rather than trying to create a "one case fits all" scenario.

Here's an example case that uses two self tapping screws. It uses little nubs at the bottom of the case to hold the PCB in place, and might provide some inspiration. :)
https://www.printables.com/model/380943-wled-wemos-shield-case-pcb-v3

afp316, 2023-03-30:
@MeisterGig I also like heat inserts but @cadriel makes an excellent point regarding sourcing and logistics.  I can confirm that I have the 8.5 mm headers measured with calipers.  Perhaps standardizing to a header spec would make the case design have one less variable (among many variables that you have dealt with).

As someone who doesn't really mess with SMD, I would think it's more accessible to design around the cheap breakouts that most amateurs buy (like myself).

I haven't looked at the datasheet for the light sensor or experimented with translucency effects on the sensor but perhaps a single layer/single wall would be able to satisfy the light sensor requirements for the application.  It may be such that the final recommendation is to print with certain colors of filaments for the lid.

In line with @cadriel thought, designing around a base set of recommended hardware will help with the design decisions immensely.  I'm sure you already know that considering I'm a late addition to this party. 🎉

cadriel, 2023-03-30:
Yep. Also - the light sensor doesn't necessarily need a whole bunch of light. I think its more important that the light exposure is consistent - and that you let SOME light in. I have other light sensor devices that only provide small holes to meet that requirement.

cadriel, 2023-03-31:
Oh - @MeisterGig  - the example case design I posted would help with some of your other concerns too. The base of the case is shallow - so adding / removing the PCB is very easy. The top of the case is inverted when compared to your current design, which provides other benefits too.

MeisterGig, 2023-04-11:
So I have adjusted a few details. The lid should now be able to snap onto the case again (if it needs too much force please tell me). There are many options variabilized (still a WIP), so adjustments can be made by changing the variables. At the moment I have set them to use 8.5 mm standoffs, a esp32 c3 mini and m3 heat set inserts (to change to screw, change the variable mounting_hole to fit your screw). The standing mount should now be printable without using supports. Unfortunatly I am currently unable to print  the case, so if someone else is able to do so feel free and give feedback. https://cad.onshape.com/documents/0970230d187b540faa10c45f/w/4e628c030e78246416c5e857/e/0f1cd3ab0062a4366c4b0a6d
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
cadriel, 2023-04-17:
Hrm, is sandwiching the the processor against some foam going to cause overheating issues? I suspect the spec for the C3 may warrant specific spacing for airflow..

cadriel, 2023-04-18:
I've created a case and published it on printables.com
https://www.printables.com/model/456377-aiosense-case

This works well for me in the mean time! Feel free to use.

MeisterGig, 2023-04-18:
@Schluggi and I have done some Improvements tonight.

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

- The lid naps in easier @afp316. The mounts also fit better now (Cornermount, wall mount and camera Mount now fit very well)
- We moved the logo to the side which looks nicer.
- The LED now has a hole as well

We think we can get rid of the foam all together by holding the back of the esp in place with a bar coming down from the lid.

Also the standing mount doesn't print properly without support. Im gonna split it into two parts.

I am optimistic these improvements will be finished this week. The case will then released to the repo and thingiverse/printables.

afp316, 2023-04-18:
@cadriel Thanks for sharing your work!

@MeisterGig @Schluggi nice work all around.  I really like the changes you describe, especially the idea of the standoff coming off the lid to apply some pressure.

I can work on modeling a simple spacer to keep the mmwave sensor (the cheaper HLK-LD2410) from moving around freely.  Not sure if y'all are experiencing the same with your HLK's or maybe my tiny headers are junk.  I am using [these](https://www.ebay.com/itm/154730133714?var=454822447335).

MeisterGig, 2023-04-18:
@afp316 that would be great. I think i'm the only other person so far, who has an HLK for this project. I have soldered them directly to the board because I didn't bother to find pin headers yet. Of course it would be great to have them.

afp316, 2023-04-20:
I made an initial mount for the HLK-LD2410 to help a bit with keeping the pcb more secure.

[https://cad.onshape.com/documents/1a4aaa3e005976151241c26c/w/5e7ad8b8b7f30e1bc78c6254/e/c07d0c7cadc1cc9efcf0446a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](url)

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

I think I can do better than this so I'm going to try to use the thru holes for the SEN0395 to design a more compact and secure mount.

riweston, 2023-05-13:
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

Have you put together any additional case mount options aside from the corner mount? The case is great fit and I'm just trying to work out a good way to place it now and I don't really want to wall mount and have a cable trailing up the wall

Schluggi, 2023-05-13:
> Have you put together any additional case mount options aside from the corner mount? The case is great fit and I'm just trying to work out a good way to place it now and I don't really want to wall mount and have a cable trailing up the wall

Yes there is. But we are not happy yet. The clip for holding the case is to lose if you print this flat without support. So we need to adjust this in the future. But feel free testing.

[Mounts - Standingmount.zip](https://github.com/Schluggi/AIOsense/files/11469288/Mounts.-.Standingmount.zip)

riweston, 2023-05-13:
I modified the STL slightly and basically just copied the measurements for the clip er 'nubbins' from the existing corner bracket on printables, I'd say it could be a tighter fit but this seems pretty secure (like I can aggressively shake it without the aiosense falling out)

[Mounts - Standingmount_riweston.zip](https://github.com/Schluggi/AIOsense/files/11469681/Mounts.-.Standingmount_riweston.zip)

Schluggi, 2023-05-31:
@riweston I just printed your version of the stand and I have to say, I'm a big fan :)
Printable without support and a nice tight fit.

With your consent I would love to share this on printables as part of the [official case](https://www.printables.com/de/model/477959-aiosense-case-official/files). I can link your github or printables profile as well. May I? If yes, I would love to have the onshape link to your version or a copy of the design as a file, since everything should be Open Source :)

Thank you!

riweston, 2023-05-31:
Oh great! Glad to hear it's a good fit :)

I just moved a few vertices around on the existing design really but help to take credit 😂

Very happy to share the project file. I'll check the file size tomorrow and assuming it's not too big I'll raise a PR if that suits you?

Closed 2023-05-10.

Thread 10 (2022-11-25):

Add Support for Low Cost mmWave Sensor(HLK-LD2410)

MeisterGig, 2022-11-25:
I found a low cost mmWave Sensor on Ali Express, https://de.aliexpress.com/item/1005004786874722.html
[Datasheet](https://github.com/ESPresense/ESPresense/files/9189632/HLK-LD2410.user.manual.V1.02.pdf)
I haven't tried it yet, but if it works, it might be worth to add pin headers for it, for being able to produce a low cost version of the AIOsense

Schluggi, 2022-11-25:
Sure...

Triskae, 2023-02-15:
I received 3 of theme today, I have to order a V2 board to try, @Schluggi do you have some boards home to test ?

Schluggi, 2023-02-15:
V2 boards yes. But no HLK-LD2410. Moreover is there no esphome config yet for these modules. But feel free and play around. Would be nice if you could create a PR if it's working for you :)

Triskae, 2023-02-15:
Can I email you about that ? I can send you a HLK-LD2410, or you can you send me a V2 board ? Instead of having to wait for it to be manufactured by JLCPCB ? :) I'll pay for the board and the ship costs of ! (I'm in france, we are almost neighbors xD

s-gordon, 2023-03-07:
@Schluggi @Triskae Some input from me here. I picked up a couple of HLK-LD2410s and had an earlier iteration of the V2 board to test these on (RC2, I think). I needed to use an adapter from the 0.05" pins of the LD2410 to the 0.1" female header on the board.

ESPHome support was added in [2023.02](https://esphome.io/changelog/2023.2.0.html) and the device page can be found [here](https://esphome.io/components/sensor/ld2410.html). After some tinkering with the config I have this working perfectly. I'll share pics and the config here when I have a sec.

koloodziej, 2023-03-07:
LD2410C has 0.1" pins but another pin layout. Can you make make PCB for that?
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

Schluggi, 2023-03-08:
> ESPHome support was added in [2023.02](https://esphome.io/changelog/2023.2.0.html) and the device page can be found [here](https://esphome.io/components/sensor/ld2410.html). After some tinkering with the config I have this working perfectly. I'll share pics and the config here when I have a sec.

@s-gordon
Awesome! Thank you for the update. I did not notice the ESPHome update yet. Feel free to create a PR to expand our ESPHome files :)

-----

> LD2410C has 0.1" pins but another pin layout. Can you make make PCB for that?

@koloodziej I'm sure we could implement this in v2.1. Could you create a separate issue for that? Links for buying also welcome.

Triskae, 2023-03-13:
@s-gordon Great, that's some good news !! Thanks a lot for the update !

Closed 2023-03-08.

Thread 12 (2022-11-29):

Switch to SMD instead of THT for all BME related components

Schluggi, 2022-11-29:
Both resistors and the capacitor are only for the BME chips. These chips can only soldered by using a heatgun or a heating plate.
So everyone who hasn't access to this kind of equipment will use a BME module instead and does not need to solder these parts.

So there is no need to make this parts consumer friendly (alias THT).

Schluggi, 2022-12-01:
Update: Both resistors are needed in any case of I²C. So there are not related to the BME chips and we will revoke our changes.

florianmulatz, 2023-01-19:
Hi Schluggi, not sure what is it about now. The Sensors are designed with SMD Footprints on your PCB. Would you redesign it for "Sensor-Modules" like this one? --> [BME680_DevBoard](https://www.reichelt.at/at/de/entwicklerboards-sensor-bosch-bme680-debo-sens-bme680-p253653.html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) or this one [BME_280_DevBoard](https://www.reichelt.at/at/de/entwicklerboards-temperatur-feuchtigkeits-und-drucksensor--debo-bme280-p253982.html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).

Anyhow of course the price is quite different on using a DevBoard instead of the sensor itself (aroun3 times more for the small-board).

I think the resistors and capacitors around the BME's will also be obsolete if using the dev-boards (I'm not able to find schematics for those but it looks like that they have a few components "onBoard")

Cheers Flo

florianmulatz, 2023-01-19:
deleted my post since I've overseen that there is already a v2 Branch. Cheers

Schluggi, 2023-04-11:
Please notice #65.

Closed 2023-03-08.

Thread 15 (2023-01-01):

Evaluate v2.0-rc2

Schluggi, 2023-01-01:
We just bought some AIOsense v2.0-rc2.

They will arrive late January.

Things we have to test:

- [x] mmWave
- [x] PIR
- [x] generic I²C ports
- [x] BME280 (onboard)
- [x] BME680 (onboard)
- [ ] onboard power
- [ ] IO pins
- CPUs
  - [x] ESP32-C3
  - [ ] ESP32-S2
  - [x] ESP32-D1
  - [ ] ESP8266-D1
- Modules
  - [x] BME280
  - [x] BME680
  - [x] BH1750

Schluggi, 2023-01-11:
The PCBs arrived today. I'll test them within the next days.

Schluggi, 2023-01-13:
After testing a bit around i found out that the air quality stuff of the BME680 does not work at all with an non generic ESP32.

Moreover there is a new problem with the PIR pin. If you want to use the PIR on the v2.0-rc2 board with an ESP8266 D1 mini, you have to remove the jumper and connect the center pin to GPIO13/MOSI. That's because GPIO0/D3 and GPIO2/D4 are always up and used for selecting the boot-mode.

s-gordon, 2023-01-18:
Thanks for the update @Schluggi! I was a little impatient and had some of the v2.0-rc2 boards fabricated as well. Can confirm that routing the PIR data pin to GPIO13 works for me as well.

What's the thinking here? Modify the design so that the jumper pin routes to GPIO13?

Schluggi, 2023-01-18:
> What's the thinking here? Modify the design so that the jumper pin routes to GPIO13?

We have notices some more problems with our current design:

- `bluetooth_proxy` only works with the arduino framework which is not compatible with non generic ESP32 boards ([source](https://esphome.github.io/bluetooth-proxies/))
- `web_server` and `captive_portal` only works with the arduino framework as well (would be nice to have)
- `bme680_bsec` are also not compatible. Without these module you cannot get values for IAQ, CO2 Equivalent & VOC Equivalent (temperature, humidity and pressure will work via the `bme680` module)

I would drop the ESP32-C3/S2 and ESP8266 compatibility and go with the generic ESP32. But this would have major impact on the project. @MeisterGig is against it.

We're happy to hear your opinion to this topic.

Schluggi, 2023-01-19:
After some more research from @MeisterGig he found out that `bluetooth_proxy` is actually working on the ESP32-C3 (since a big change in [ESPHome 2022.12](https://esphome.io/changelog/2022.12.0.html#bluetooth-proxy)).

He also found a [pull-request](https://github.com/esphome/esphome/pull/3500) for the `web_server` and `captive_portal` problem.

So `bme680_bsec` is the only module that's still not working. Maybe we can find a solution here as well.

florianmulatz, 2023-01-19:
> 680 does not work at all with an non generic ESP32.
>
> Moreover there is a new problem with the PIR pin. If you want to use the PIR on the v2.0-rc2 board with an ESP8266 D1 mini, you have to remove the jumper and connect the center pin to GPIO13/MOSI. That's because GPIO0/D3 and GPIO2/D4 are always up and used for selecting the boot-mode.

Do I understand correctly that a generic ESP32 (aka WEMOS D1 form-factor like this --> [ESP32 - AMZ Link](https://www.amazon.de/dp/B08BTYCGVV?ref=ppx_yo2ov_dt_b_product_details&th=1) will work without any problems including PIR and I2C Dev-Boards (like f.e. this one [URL](https://www.joy-it.net/de/products/SEN-BME680) )

Cheers

Schluggi, 2023-01-19:
> Do I understand correctly that a generic ESP32 (aka WEMOS D1 form-factor like this --> [ESP32 - AMZ Link](https://www.amazon.de/dp/B08BTYCGVV?ref=ppx_yo2ov_dt_b_product_details&th=1) will work without any problems including PIR and I2C Dev-Boards (like f.e. this one [URL](https://www.joy-it.net/de/products/SEN-BME680) )
>
> If so - I highly appreciate to go for ESP32 (as mentioned above). It's anyhow the way to go for most projects (as of today :) )

On a software-side the generic ESP32 (aka WEMOS D1) works the best because we can use the slow, old but reliable arduino-framework inside ESPHome. There is a newer and faster framework called "esp-idf". But unfortunately not all modules are supported right now.

The WEMOS D1 generic ESP32 Board has a different pin layout then the ESP8266, ESP32-C3 and ESP-S2, so it will not work with any version of AIOsense yet.

The I²C dev-boards will work with every version of AIOsense but depending of the ESP the feature set of the BME680 is different. If you want to get all out of your BME680 use an ESP8266 and the v2.0-rc3 release. But because its a ESP8266, it has no bluetooth. The PIR will work with [this](https://github.com/Schluggi/AIOsense/issues/15#issuecomment-1382575615) modification on every board v2.0-rc2 and above.

The ESP32-C3 has some benefits over the generic ESP32 (USB Type-C, no programmer needed). We plan also to release a SMD only version of AIOsense. So we should have this in mind. No need for a programmer chip is very nice and cuts down the costs.

So i opened an [ESPHome feature request](https://github.com/esphome/feature-requests/issues/2072) to support the ESP32-C3. This would be the best solution in my opinion. If there is no progress until the end of January, we will switch completely to the generic ESP32.

florianmulatz, 2023-01-20:
> The WEMOS D1 generic ESP32 Board has a different pin layout then the ESP8266, ....

I disagree :) From my point of perspective they're pin-compatible (I can not say anything about ESP-C3 / ESP-S2 - since I don't konw (neither own) them)

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

Please just let me know if I get this wrong :)

s-gordon, 2023-01-20:
> > The WEMOS D1 generic ESP32 Board has a different pin layout then the ESP8266, ....
>
> I disagree :) From my point of perspective they're pin-compatible (I can not say anything about ESP-C3 / ESP-S2 - since I don't konw (neither own) them)

Agree with @florianmulatz. I've tried this with a generic ESP32 (MH-ET Live MiniKit) and it seems fine. I've only tested THT BME280, BH1750, SEN0395, and the PIR module. Happy to lodge a PR with my YAML if there's interest.

Schluggi, 2023-01-21:
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

I totally agree. I wonder how i could miss that. Can you upload an image of the ESP32 on the board? PRs are always welcome :)

I just ordered a few ESP32 mini boards to test it myself.

Moreover I changed the labels of the ports. Now you can see more easily whats connected to. That should help by finding the right port in the ESPHome-config. Any comments on that?

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

Next steps:
I will test the ESP32 D1 mini board. If everything works fine I will finally release v2.0. Thank you for your help :)

s-gordon, 2023-01-22:
Sure. These aren't the best pictures, but here you go :-). I salvaged the ESP32 board from another project and needed to remove the old header pins - hence why the board looks a little worn. I'm waiting on the PIR sensors to arrive later this week, and so they aren't shown here.

No worries. I'll look into doing a PR later in the week.

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

Schluggi, 2023-01-22:
@s-gordon

Thanks! :)
Do I see it right that the ESP32 mini is bigger than the AIOsense board?

s-gordon, 2023-01-22:
That's right, it does protrude beyond the bottom edge of the AIOsense board by about 3 mm. The camera perspective exaggerates it a little.

Schluggi, 2023-01-30:
I finally found a way to use the `bme680_bsec` component with an ESP32-C3 (fb7976eb35cdcf3bc050d74ac4c29ba4ce0aaad7). 🥳

Everything works now!

So the only thing we have to discuss: Does we want to increase the board size to fit better with generic ESP32 boards? I would say no, because otherwise we would have a problem with the case.

But maybe @MeisterGig could come up with a case design option for generic ESP32 boards? So we don't have to increase the board size, just the case?

s-gordon, 2023-01-31:
I'm in favour of increasing the PCB size to accommodate generic ESP32 boards, although I am being a little selfish :-P.

If reworking the case design is a concern, then I'd be happy to contribute the STLs that I've put together. This will fit both the D1 Mini and generic ESP32.

MeisterGig, 2023-02-01:
I agree with @Schluggi. It is unwise to increase the size of the board even more. It's already quite big. As far as i can see the length would also need to be modified, this would be a disadvantage for c3 and s2 modules, because the USB port would be too far in the case.

In addition, c3 and s2 chips are newer, cheaper and will be supported for a longer time compared to the 32 series https://www.espressif.com/en/products/longevity-commitment

MeisterGig, 2023-02-01:
I agree with @Schluggi. It is unwise to increase the size of the board even more. It's already quite big. As far as i can see the length would also need to be modified, this would be a disadvantage for c3 and s2 modules, because the USB port would be too far in the case.

In addition, c3 and s2 chips are newer, cheaper and will be supported for a longer time compared to the 32 series https://www.espressif.com/en/products/longevity-commitment

If we are looking a little bit further in the future. Espressif just launched the ESP32-C6 (which has WiFi 6 and Zigbee support) https://www.espressif.com/en/products/socs/esp32-c6 this chip also has a similar size as the c3 and comes with an internal USB to Serial module like the c3 and S2. So my best guess is, that WEMOS will probably design the c6-mini in the same form factor as the c3 and s2 mini.

florianmulatz, 2023-02-02:
Agree to. Although I've more esp32 (d1mini) at home - I'm willing to invest in a more modern platform as well of course. ESP32-c6 sounds cool - ZIGBEE let's my heart beats faster 😅

Schluggi, 2023-02-02:
> Although I've more esp32 (d1mini) at home - I'm willing to invest in a more modern platform as well of course.

You don't have to. The generic ESP32 will be compatible. We just don't increase the board size for this one. So it overlaps as @s-gordon pictures has shown. @MeisterGig will also release a case design for this one. So you can still use your generic ones. However the C3 will fit better.

Yes, the C6 looks cool but please have in mind we have to wait until ESPHome and Bosch supports it.

At this moment I will release v2.0-rc4 in the next days and order these. Afterwards we hopefully have a bug free v2 release :)

Closed 2023-02-05.

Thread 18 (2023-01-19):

Request for enhancement (RFE): Redesign the 5V Power Input

florianmulatz, 2023-01-19:
Hi Schluggi,

I suggest to redesign the power input to not use a "Male PIN-Header" but a "wire-to-board-terminal-block" like this one --> [WUERTH Terminal-block](https://at.farnell.com/wurth-elektronik/691216410002/reihenklemme-wtb-2way-30-12awg/dp/3768503)

At least on the ESP32, the USB port is on the top. I'm not sure if the ESP8266 has it on the bottom, like your 3D model. Since you won't be supporting the 8266 anymore anyway, it would at least be worth considering, because with a terminal block you might have more strain relief

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

Cheers Flo

Schluggi, 2023-01-19:
@florianmulatz, thank you for your input. I'll keep this in mind before the final v2 release. It is something we can quickly change. 👍

Schluggi, 2023-01-19:
I just tested the tolerances with my v2.0-rc2 board with an ESP8266. Its really tight! 😄
So maybe we can move the IO-ports under the ESP and the power connector to the IO-panel. We'll see :)

florianmulatz, 2023-01-20:
Does the "tightness" makes it not good? I think there will be terminal-blocks with even a smaller "housing" at least this one was something I had at home. Just for reference (it has a height of 9,95mm) - I don't know the exact manufacturer of this one - since I bought it very cheap on AliExpress.

The one from Farnell above is wrong - I did not take care on the pitch. This one should fit better --> [WUERTH Terminal-Block](https://www.digikey.at/de/products/detail/w%C3%BCrth-elektronik/691210910002/10668428). It has a height of only 8,5mm

Cheers

Schluggi, 2023-01-21:
8,5mm sounds great. I changed it :)

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

florianmulatz, 2023-01-23:
Thx for your fast update! - Issue closed

Closed 2023-01-23.

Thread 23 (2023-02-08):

Issues with mmwave GPIO pin

MeisterGig, 2023-02-08:
I am currently having issues with the mmwave GPIO pin on the ESP32-S2. Sometimes when the pin i high, it isn't detected by the ESP. I checked the connection, which seems to be okay. Maybe the issue is the internal pulldown.

Anyways I was searching for other solutions. I found out that the mmwave sensor is also sending the value over UART so i tried to write a custom binary sensor component for that, but haven't gotten far due to my horrible C skills.

But i now also found that someone else might have already done the work:  https://github.com/esphome/esphome/pull/4203

We could evaluate this solution and maybe save a gpio pin, which can then be used for something else, like audio output.

Schluggi, 2023-02-13:
Does the any other ESP work for you?

Schluggi, 2023-03-08:
@MeisterGig any update? Otherwise I would close this issue.

MeisterGig, 2023-03-08:
I haven't tried it anymore.

Schluggi, 2023-03-28:
I'll close the issue. You can reopen it in case of new information.

Closed 2023-03-28.

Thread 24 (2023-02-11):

PIR not responding on version 1

cptbucky, 2023-02-11:
First of all thank you for making this project available, it's exactly what I was looking for.

I got a bit excited and ordered the version 1 pcb without reading the warning, is there somewhere that lists out the things that don't work on v1?

To the point, when testing the EKMC1603111 PIR it's not responding to motion when attached to the v1 pcb. I have 2 test pcbs, one is fully soldered with all components/female headers, the other just the dev board and PIR socket (assuming that's the bare minimum requirements).

If I attach the sensor directly with a nodeMCU or Wemos D1 mini ESP32 it works perfectly, attached to an Olimex POE ISO I have to use a pull down resistor from ground to out. I have still not been able to get the Wemos D1 mini ESP8266 to work, which behaves the same as when connected to the pcb.

Any help would be amazing!

Schluggi, 2023-02-11:
Hi Tom,
thank you for issue. Issue #13 is related to this. Sure, without any info you couldn't know.

What does not work is the PIR (wrong footprint) and maybe also the onboard BME sensors (if your power supply has voltage drops).

To fix your PIR you can cut the PCB paths with a cutter and resolder a wire. Please take a look into the v2 PIR footprint where's fixed.

The Esp8266 does not work with the v1 board as well, because the PIR pin is connected to a pin which is not allowed to be pulled up at bootime.
In general the PIR does not need a pulldown or pulluo resistor.

I would recommend the ESP32-C3 mini for all further boards. The documentation is wrong at this point and still recommend the generic ESP32, which works but is a bit to big for the PCB v2 (never tested with v1).

I hope I could help :)

cptbucky, 2023-02-12:
Thanks ever so much for the quick reply @Schluggi it's all very helpful so thank you for that!

Am I correct that the wrong footprint for the PIR on v1 is VDD and GND being the wrong way round? If so, forgive my inexperience here but assuming I use the ESP32 board I can cut the track for VDD 3v but I'm not sure how to intercept GND do you mean that I should disconnect it from the board itself and use a wire instead?

Fortunately I have a few ESP32-C3s on order so looking forward to v2!

Schluggi, 2023-02-13:
Your welcome :)

Yes your are right. VCC/VDD and GND are swapped. Since we use a hole layer as GND its harder to intercept. All GND pins has 4 lines to the layer you have to cut them all (red=cut):
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

But yes. Waiting for V2 or use only wires to connect the PIR would be much easier.

---

V1 (wrong):
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

v2 (correct):
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

cptbucky, 2023-02-14:
Thank you for the excellent explanation, very much appreciated!

Closed 2023-02-16.

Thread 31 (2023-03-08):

Improve docs

Schluggi, 2023-03-08:
- [ ] BOM
- [x] Better structure
- [x] Badge
- [x] Fix readme link
- [x] Quickstart guide

Closed 2023-03-11.

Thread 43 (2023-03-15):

C3 Configuration Yaml not working

florianmulatz, 2023-03-15:
**Category**
- [ ] Hardware / PCB
- [X] Software / ESPHome

Error during config-validation in ESPHome (looks like the "external component" does not get loaded ?!
ESPHome-Version: | v2023.2.4

```
INFO Reading configuration /config/esphome/esphome-mmwave-schlafzimmer.yaml...
Failed config

sensor.bme680_bsec: [source /config/esphome/esphome-mmwave-schlafzimmer.yaml:141]

  Component sensor.bme680_bsec requires component bme680_bsec.
  platform: bme680_bsec
  temperature:
    name: aiosense-c3-mini Temperature
    sample_rate: lp
    filters:
      - median
  pressure:
    name: aiosense-c3-mini Pressure
    sample_rate: lp
    filters:
      - median
  humidity:
    name: aiosense-c3-mini Humidity
    sample_rate: lp
    filters:
      - median
  iaq:
    name: aiosense-c3-mini IAQ
    id: iaq
    filters:
      - median
  co2_equivalent:
    name: aiosense-c3-mini CO2 Equivalent
    filters:
      - median
  breath_voc_equivalent:
    name: aiosense-c3-mini Breath VOC Equivalent
    filters:
      - median
text_sensor.bme680_bsec: [source /config/esphome/esphome-mmwave-schlafzimmer.yaml:172]

  Component text_sensor.bme680_bsec requires component bme680_bsec.
  platform: bme680_bsec
  iaq_accuracy:
    name: aiosense-c3-mini IAQ Accuracy
```

florianmulatz, 2023-03-15:
if I put
```
bme680_bsec:  # disable for bme280
  temperature_offset: "5.8"
  state_save_interval: "1h"
```
into yaml (from 8266 configuration) - Validation works again

Schluggi, 2023-03-15:
Thanks for noticing. I will fix it later this day. Your workaround is actually the fix. It does not work without `bme680_bsec:`.

Closed 2023-03-15.

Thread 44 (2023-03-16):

Too many I²C pull-up resistors

florianmulatz, 2023-03-16:
**Category**
- [ ] Some docs are wrong or outdated
- [X] I miss something the docs

There should be an info that the two resistors R1/R2 must not be populated when using the I²C modules BME280/BME680. I got quite bad readings because I soldered them on the board in the beginning - sometimes no values were entered at all at startup - I had to do several restarts.

Maybe I'm missing something or misinterpreting something - but since I removed the two resistors, everything works fine.

Cheers

Schluggi, 2023-03-16:
These resistors are necessary for I²C in general. They pull-up the signal to define the I²C master.

Which ESP do you use? Could you send a picture of your module where I can see the onboard resistors on the module?

florianmulatz, 2023-03-16:
I'm using the new C3 Lolin ESP32. BME680 is exactly this module --> https://de.aliexpress.com/item/1005001621661986.html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

Schluggi, 2023-03-18:
You might be right. I will analyze this in detail in a few days.

cptbucky, 2023-03-18:
I have had an odd behaviour that might be related whilst using the C3 Lolin ESP32, the PIR is unresponsive, always reporting detected.

Thanks for the above, I will try removing the resistors as I have 2 AIOSense boards setup with consistent behaviour (no I²C issues though!) and one custom D1 Mini ESP8266 that works. I haven't added the surface mount capacitor.

If entirely unrelated, please let me know and I'll raise a new issue.

s-gordon, 2023-03-19:
I've seen this behaviour with ESP32 D1 Minis and Lolin C3 Minis and the BME280 when fixed to the board. Typically failed I2C scans, or odd errors in the log. Multiple restarts and re-installing firmware eventually fixed it. I'd put this down to bad soldering as I had done this using solder paste and a hot air gun, but it may be similar to what others have reported here.

Schluggi, 2023-03-20:
We need I²C pull-up resistors to make I²C to work. But since every module has there own pull-ups, we ending up with too many pull-ups which can resolve in bad readings.

I spotted pull-ups on your BME-module as well as on the light module. So yes you're right you can remove  the onboard resistors as long as don't use the SMD-BME module only.

Maybe it would be nice to remove the SMD parts completely. That's why I'm started the poll: https://github.com/Schluggi/AIOsense/discussions/51.

Schluggi, 2023-03-20:
@florianmulatz I just added this to the docs.

Again: Thank you for noticing :)

Closed 2023-03-20.

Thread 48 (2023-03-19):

BOM + Soldering / Part instructions

cadriel, 2023-03-19:
- [* ] missing something the docs

Would love to see some further docs re;
- A BOM. Could simply be a page that links to recommended parts on DigiKey and Mouser perhaps. This could help with confidence for some people.
-  Some instruction / imagery that represents what a populated PCB looks like. This also helps to confirm visually that you've soldered your board correctly.
- A guide on how to test your board is soldered correctly with a multimeter? I'm not sure if this step is necessary given the simplicity of the PCB.

Also, i wanted to ask about PIR sensors and dirty power. I get a lot of false positives with my Panasonic PIR that I intend to use on this project - and read that its often a good idea to do something to avoid this. I wasn't sure if this is something that's covered in this project yet or not (or even if its required..).

Finally, THANK YOU for this! I can replace my hobbled together sensor with a decent PCB, finally. :0

cadriel, 2023-03-20:
I've since found most links in the docs, so ignore my first comment. The mouser link for the TO-5 is / was down when I was looking. Might be nice to add the equivalent DigiKey link there (https://www.digikey.com/en/products/detail/mill-max-manufacturing-corp/917-43-103-41-005000/1212170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)

Schluggi, 2023-03-20:
Hi @cadriel,

thank you for your suggestions.

----

> Might be nice to add the equivalent DigiKey link there

Yes. The Mouser website is often in maintenance mode. At least at weekend. I just updated the docs: https://github.com/Schluggi/AIOsense/commit/2e7f5f7586525528304d58c9393b6f659e8f3144 :)

----

> A BOM. Could simply be a page that links to recommended parts on DigiKey and Mouser perhaps. This could help with confidence for some people.

I have often thought about a complete BOM but since everything is modular it felt hard. Do you thing it would be more beginners-friendly to have one?

----

> Some instruction / imagery that represents what a populated PCB looks like. This also helps to confirm visually that you've soldered your board correctly.

Did you spot the images at the [README.md](https://github.com/Schluggi/AIOsense/blob/main/README.md#what-does-it-look-like-)? Or are you looking for some closer images?

----

> A guide on how to test your board is soldered correctly with a multimeter? I'm not sure if this step is necessary given the simplicity of the PCB.

This would make sense in the future when the PCB is more complex but at this moment it is (as you said) a really simple PCB.

cadriel, 2023-03-20:
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

Fantastic! :)

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

I think so yes. I've completed a bunch of other similar projects, most notably a WLED wemos shield recently. I found their BOM quite useful. Especially given the fact that many users are from many parts of the world - so having multiple links for major regions is quite helpful. Also, having a single place to reference all parts is also helpful.

**Note:** I could not find links to the resistors at all in the documentation - so I know that should **definitely** be resolved in some way.

Here's the project for reference; https://github.com/srg74/WLED-wemos-shield/wiki

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

Yes - I noticed the images on the main README. It might be helpful to see a couple of configurations here. I.e., some pictures of someone with a configured board with only the TO-5 and resistors in place (so people can confirm orientation) - and then a couple of pictures that represent the SMD versus the PCB modules installed.

> > A guide on how to test your board is soldered correctly with a multimeter? I'm not sure if this step is necessary given the simplicity of the PCB.
>
> This would make sense in the future when the PCB is more complex but at this moment it is (as you said) a really simple PCB.

Yep. Here's the WLED projects wiki page on the subject which might be useful for reference;
https://github.com/srg74/WLED-wemos-shield/wiki/Assembly
https://github.com/srg74/WLED-wemos-shield/wiki/Check

It really helps people that are less familiar with electronics. :)

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

My current configuration is a hand soldered version using the commonly known ESP32 D1 Mini
https://doc.riot-os.org/group__boards__esp32__mh-et-live-minikit.html
https://www.amazon.com/gp/product/B07BK435ZW/ref=ppx_yo_dt_b_search_asin_title?ie=UTF8&psc=1

And the PIR sensor is the Panasonic EKMC.
https://www.digikey.com/en/products/detail/panasonic-electric-works/EKMC1603113/2601882

The PIR is connected to pin 17 I believe. Its been getting worse over time, and I think its due to dirty power - but I'm no expert on the subject. If I disconnect power to the device, then it's good but slowly returns to sending false positives every few minutes.

There are a few posts on the home assistant forums from people more knowledgable than me suggesting that power can cause issues with PIR's. I'd guess the best bet is to follow the datasheet for the EKMC tho.
https://community.home-assistant.io/t/which-pir-sensor/512976

https://api.pim.na.industrial.panasonic.com/file_stream/main/fileversion/248121
https://api.pim.na.industrial.panasonic.com/file_stream/main/fileversion/244673

It could also be poor wiring on my part. I've ordered your RC4 PCB today, so I'll be connecting it all in the coming weeks to see if that resolves my false positive issues.

Sorry for the wall of text, hopefully you can take that all in :)

cadriel, 2023-03-29:
You're awesome, thanks.

My PIR issues were for a manually soldered setup, nothing to do with this project. I'll re-test this in the new configuration with your PCB today to see if I have similar issues or not.

afp316, 2023-03-30:
I purchased these BME680 breakouts from [aliexpress](https://www.aliexpress.us/item/2255800927135555.html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).

I started assembling the board (V2.0.0) with headers and noticed that the BME680 module pins are oriented such that the breakout will extend away from the center of the board when installed.  See the image below.

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

Was this by design?  Maybe I bought the wrong ones.

Schluggi, 2023-03-31:
> Was this by design? Maybe I bought the wrong ones.

Please take a look at #55. For now you have to solder it upside down. This is already fixed and will be part of v2.1.0.

afp316, 2023-03-31:
I guess I didn't look hard enough.  Thanks!

afp316, 2023-04-15:
I had some stacking headers lying around so I used them with the V2.0 pcb.  I bent the header at a right angle to the board.  This allows for avoidance of unsoldering/resoldering the header for the bme680 pcb.  With this, the module protrudes upward and I'll probably just modify the case a bit for this use since the next version has a modified pcb.
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

Schluggi, 2023-04-23:
@cadriel We now have a BOM. Please give feedback :)

cadriel, 2023-04-23:
@Schluggi The link in the docs appears to be broken. It takes me here;
`https://github.com/Schluggi/AIOsense/bom` which is a 404.

Maybe it was meant to link here `https://github.com/Schluggi/AIOsense/tree/main/bom`

Schluggi, 2023-04-23:
> Maybe it was meant to link here `https://github.com/Schluggi/AIOsense/tree/main/bom`

Thanks. Is fixed now :)

cadriel, 2023-04-23:
Also, the very first next button on the docs homepage takes you here;
https://aiosense.readthedocs.io/en/latest/_pcb/

But this page doesn't seem to be in the menu anywhere, and it looks like this is the only way to get to it. However, it doesn't seem like the first logical place you end up on? Might've been a weird oversight or something.

The page itself seems relevant tho - so maybe it just needs to be put in the menu somewhere?

cadriel, 2023-04-23:
Re: the BOM - it might be worthwhile to have this as a google docs (or similar) link instead? This way you can update it on the fly without having to generate a PDF, or make a commit.

You can then also start providing links to components more easily, which might also be a good improvement.

For example, here's the voron sourcing guide.
https://docs.google.com/spreadsheets/d/e/2PACX-1vS_jv9UtoSkgQoYD47VE9wIpTnjsEbzAREPG8895b6UL0v99OIfVEJQ4BHl2w_Rn6V0YUe1ldfPjone/pubhtml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

cadriel, 2023-04-23:
(But it otherwise looks good for now too! :))

Schluggi, 2023-04-23:
> Also, the very first next button on the docs homepage takes you here; https://aiosense.readthedocs.io/en/latest/_pcb/

Fixed. I thought an underscore would make the site inaccessible :/

--
Google docs cloud be an option, but I like to have everything in repos. And since the BOM will not change that often...

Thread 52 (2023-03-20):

PIR Sensor Unresponsive

cptbucky, 2023-03-20:
**Category**
- [x] Hardware / PCB
- [x] Software / ESPHome

**Describe the bug**
Apologies this doesn't appear straightforward!

When booting the board with a Panasonic PIR attached (EKMC1603111) the reading for Motion in Home Assistant is constantly Detected. In ESPHome logs the sensor appears unresponsive.

Initially when setting up the board everything was fine for about a week, then the behaviour started so I replaced the PIR which fixed the issue; around a week later the same issue occurred :-( I question whether this was actually triggered by an outlet change.

The testing setup I now have:

1. AIOSense board setup with all components, including resistors on a ESP32 Lolin C3 Mini  - reports Detected
2. AIOSense board setup with only the PIR, no resistors on an ESP32 D1 Mini - works, though only running for a couple of days
3. custom board with all components, no resistors on an ESP8266 D1 Mini - works, has been running for a while and hasn't faced this issue yet
4. breadboard mimicking the schematic with all components, no resistors on a ESP32 Lolin C3 Mini - works, though only running for a couple of days

If I switch the ESP32 boards over on 1 and 2 then both report detected, switching them back and it appears board 2 has now broken :face_exhaling:  **Update** changing power source and board 2 is working again, board 1 started working again after 7+ days of detected no change to PSU.

In the above scenario 1-3 are on a shared extension brick whilst 4 is on a separate outlet, the reason I mention is that the breadboard also displayed this behaviour but only on the shared extension brick and not when connected to my laptop or the separate outlet.

If anyone can think of anything, wants me to try anything then by all means let me know.

sebastiansson, 2023-03-29:
I had to set this in order for it not to stay on "Detected" all the time:

```yaml
pin:
  number: GPIO23
  mode: INPUT_PULLDOWN
```

Schluggi, 2023-03-29:
> I had to set this in order for it not to stay on "Detected" all the time:

There is no hint for a PULLDOWN in the datasheet for the PIR. And I don't even need one. But because this had no negative impact I'll change it in the example.

@cptbucky can you test if that solves you PIR problem?

sebastiansson, 2023-03-30:
If I recall correctly it worked without `INPUT_PULLDOWN` when I had it connected to my computer and flashed it. But when I plugged it in the wall without reflashing it, the sensor stayed on "Detected" all the time. Maybe the`INPUT_PULLDOWN` resets the sensor somehow?

Schluggi, 2023-03-30:
Ok, please try the following: Disconnect the PIR, plug the board into your wall, wait until the board is online and connect the PIR again.

Post your result :)

sebastiansson, 2023-03-30:
> Ok, please try the following: Disconnect the PIR, plug the board into your wall, wait until the board is online and connect the PIR again.
>
> Post your result :)

Without `INPUT_PULLDOWN` I suppose?

Schluggi, 2023-03-30:
> Without `INPUT_PULLDOWN` I suppose?

Yes

cptbucky, 2023-04-04:
Following on from the `INPUT_PULLDOWN` configuration addition I have not experienced the always detected behaviour.

I haven't removed it and rejigged to try and force the behaviour again, I will try to do a bit more testing on this.

cptbucky, 2023-04-14:
I've had a play and not seen the issue recur following the addition of the pull down config so I think this issue can be closed.

Thanks for everyone's help on this.

Closed 2023-04-14.

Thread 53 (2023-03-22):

PIR / SEN0395 does not fit together

florianmulatz, 2023-03-22:
**Category**
- [X] Hardware / PCB
- [ ] Software / ESPHome

**v2 - RC4**
...

It looks like that the PIR does not fix together with SEN0395 (at least when mounted via "socket")
Did you guys managed to get this together?
...
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

Schluggi, 2023-03-22:
Hi @florianmulatz,

you need a TO-5 3-pin socket: [Mouser](https://www.mouser.de/ProductDetail/Mill-Max/917-43-103-41-005000?qs=teNCaa%2FZ3auQVxVMs%2F5ihg%3D%3D), [Digi-Key](https://www.digikey.com/en/products/detail/mill-max-manufacturing-corp/917-43-103-41-005000/1212170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)

This is noticed in the docs [here](https://aiosense.readthedocs.io/en/latest/sensors/#motion-sensor-pir).

florianmulatz, 2023-03-22:
ok thx - didn't notice that!

florianmulatz, 2023-03-22:
I found those sockets too expensive to be honest  so I cheated :)
It's not "beautiful" but it works and when it's in it's case afterwards nobody would recognize :)

Cheers
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

Closed 2023-03-22.

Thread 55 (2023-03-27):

Generic i2c pin orientation

cadriel, 2023-03-27:
**Category**
- [*] Hardware / PCB

**Version of ESPHome / AIOsense**
2.0 RC4

**Describe the bug**
The PCB sensor pin orientation forces the sensor boards to be mounted upside down. This means the sensor chips themselves end up facing down / toward the PCB - rather than up.  Secondarily, it means the pins on the sensor boards need to be soldered in an uncommon way (upside down..) which in turn means soldering is a bit more difficult.

This runs true with the sensor boards linked in the documentation.

Would it make more sense to have these pin holes swapped around?

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

Image above represents the same sensor board with pins soldered each way to help illustrate the problem. The top sensor board is how you would normally solder the pins, however - this causes the board to extend outside of the main PCB. The bottom sensor board is pinned in reverse in order to have it oriented correctly.

Schluggi, 2023-03-28:
> Would it make more sense to have these pin holes swapped around?

Absolutely! I'll change it in v2.1.0.

Closed 2023-03-29.

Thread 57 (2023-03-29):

PIR interferes with mmWave

cadriel, 2023-03-29:
**Category**
- [*] Hardware / PCB

**Version of ESPHome / AIOsense**
2.0 RC-4

**Describe the bug**
The PIR sensor interferes with the mmWave sensor. Accordingly - the PIR doesn't fully seat into the socket.

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

The socket is fully seated, it's designed to sit a couple of mm above the board, as per the spec here. Note this is the spec'd TO-5 socket from the documentation.

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

The PIR sensor itself can't be fully seated due to its pin length (you could of course cut these down if required..) however, in its default state the PIR sensor interferes with the soldered pins on the DFRobot mmWave sensor.

Secondarily, the current printable case doesn't work at all with this configuration because its cutout sits far too high to even seat into the socket at all. I assume the case would have an update to resolve this we haven't seen yet.

You'd either need a TO-5 socket that sits higher, or would need to adjust the position of the PIR sensor to resolve this.

Schluggi, 2023-03-29:
The PIR height is really precise calculated and it's made for exactly this height. However I was surprised as well the first time I had put the PIR into the socket. But even if this is not beautiful, it works fine. Moreover I was not able to find any other (cheap) TO-5 Socket. If you spot one please share it.

Did you print the case from the files (it's a case for v1 only). Or did you use the beta version of [ this case](https://github.com/Schluggi/AIOsense/issues/9)? However there is no perfect case yet. Please notice #9. To prevent further confusion, I've moved the case file into a subdirectory named by the version.

Schluggi, 2023-03-29:
> The case I printed was the work in progress for V2.. not V1.

The case need a complete rework @MeisterGig is working on this.

Closed 2023-03-29.

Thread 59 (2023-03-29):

add aliexpress link for TO-5 3-pin socket

regevbr, 2023-03-29:
**Category**
- [x] Hardware / PCB
- [ ] Software / ESPHome

**Whats your idea?**
I want to order `TO-5 3-pin socket` but the shipping is extremely expensive. I tried to look for it in aliexpress, but without luck. Can you please help out?

For EKMC1603111 i managed to find https://www.aliexpress.com/item/1005003203976549.html?spm=a2g0o.cart.0.0.7d1f38dapwtcSv&mp=1 but I can't verify it is reliable yet

Schluggi, 2023-03-31:
Hi @regevbr,

I have not found the socket there either.

Maybe [Octoparts](https://octopart.com/917-93-103-41-005000-mill-max-853810?r=sp) can help to find a cheap solution.

regevbr, 2023-04-01:
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

Thanks sadly shipping to Israel it is around 28 USD in all oh the websites :-(

Schluggi, 2023-04-03:
If you can't get a socket. You could go [the dirty way](https://github.com/Schluggi/AIOsense/issues/53#issuecomment-1479398825).

I close the issue for now. If you can confirm that the PIR from Aliexpress works, please reopen this issue or (even better) create a PR to extend the docs.

Thank you for you contribution.

Closed 2023-04-03.

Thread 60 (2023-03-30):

BME680 error

afp316, 2023-03-30:
**Category**
- [ ] Hardware / PCB
- [x] Software / ESPHome

**Version of ESPHome / AIOsense**
ESPHome: 2023.3.2
AIOsense: latest

**Describe the bug**
I get an error with the bme680 initialization.  It wants me to append "_m" to several variables in the cpp file.  I searched to find this error but couldn't come up with anything.  I apologize if there is already a solution.  See the link for my logs.

[logs_aio-utility-room_run.txt](https://github.com/Schluggi/AIOsense/files/11107146/logs_aio-utility-room_run.txt)

Schluggi, 2023-03-31:
Hi @afp316,

please share your YAML as well :)

afp316, 2023-03-31:
oops crap, sorry about that.  noob moment.  Thanks for you patience..

[aio-utility-room.yaml.txt](https://github.com/Schluggi/AIOsense/files/11122228/aio-utility-room.yaml.txt)

I haven't included any pw's or keys in the txt.

Schluggi, 2023-04-04:
Thank you @cadriel for the quick fix.

Unfortunately if you want to use bsec you have to downgrade your ESPHome.

It should be possible to use the new bsec component @cadriel had linked, but it does not work for me now. We have to wait for a fix :/

afp316, 2023-04-06:
Thank you @cadriel !  That did the trick for me.

afp316, 2023-04-15:
signed off complete based on the @cadriel fix that works for me.

CappyT, 2023-08-17:
Any updates on this? IAQ would be cool to have. The bsec2 lib should be there, I don't know what is blocking the functionality right now

Thanks

Schluggi, 2023-08-19:
> Any updates on this? IAQ would be cool to have. The bsec2 lib should be there, I don't know what is blocking the functionality right now

Yes. This would be nice. The problem is Bosch uses a library called "BSEC" which calculates the IAQ value. BSEC1 is not compatible with any ESP32. Unfortunately is this the version in the current ESPHome version.

Bosch released BSEC2 some time ago but no one has implemented this into ESPHome yet. Therefore is this (non working) [pull request](https://github.com/esphome/esphome/pull/4585).

There is also a time you could use [this modified fork](https://github.com/Schluggi/esphome/tree/bme68x_bsec) by @neffs to make it work (which uses bsec version 2). But ESPHome had a breaking change so this does not work anymore.

You could try using an ESP8266, since BSEC1 should work there or to downgrade ESPHome to (September 2022 (i think?)) and use my modified fork. But there is a chance other modules uses newer features that were not available at this time.

Since I can't code C++ that well, I'm unable to fix it myself. If you can... I would be happy :)

florianmulatz, 2023-10-13:
Is there a way to include this one as temporary fix?

https://github.com/esphome/esphome/pull/4585

Schluggi, 2023-10-13:
> Is there a way to include this one as temporary fix?
>
> [esphome/esphome#4585](https://github.com/esphome/esphome/pull/4585)

You are fast.. but I'm as well ;)

Yes, I just created PR #122. But this PR has some breaking changes.
You can try out by editing your packages:

```yaml
packages:
  remote_package:
    url: https://github.com/schluggi/AIOsense
    ref: bsec_is_back # << changed from main
    refresh: 1d
    files:
      # [...] other files
      # - esphome/packages/sensors/bme280.yaml  # comment this line
      # - esphome/packages/sensors/bme680.yaml  # comment this line
      - esphome/packages/sensors/bme68x_bsec.yaml # add this line
      # [...] other files
```
Please notice the changed and removed substitutions:
`bmex80_address` -> `bme_address`
`bmex80_update_interval` -> `bme_update_interval`
`bme680_bsec_sample_rate` -> gone. not part of the quickfix
`bme680_bsec_temperature_offset` -> gone. not part of the quickfix

florianmulatz, 2023-10-15:
compiles perfectly :) aaaand -->

```
[09:11:17][C][bme68x_bsec.sensor:134]: BME68X via BSEC:
[09:11:17][C][bme68x_bsec.sensor:139]:   BSEC Version: 2.2.0.0
[09:11:17][C][bme68x_bsec.sensor:141]:   Address: 0x77
```
```
[09:11:17][C][bme68x_bsec.sensor:159]:   IAQ 'IAQ'
[09:11:17][C][bme68x_bsec.sensor:159]:     Device Class: 'aqi'
[09:11:17][C][bme68x_bsec.sensor:159]:     State Class: 'measurement'
[09:11:17][C][bme68x_bsec.sensor:159]:     Unit of Measurement: 'IAQ'
[09:11:17][C][bme68x_bsec.sensor:159]:     Accuracy Decimals: 0
[09:11:17][C][bme68x_bsec.sensor:159]:     Icon: 'mdi:gauge'
[09:11:17][C][bme68x_bsec.sensor:162]:   CO2 Equivalent 'CO2 Equivalent'
[09:11:17][C][bme68x_bsec.sensor:162]:     Device Class: 'carbon_dioxide'
[09:11:17][C][bme68x_bsec.sensor:162]:     State Class: 'measurement'
[09:11:17][C][bme68x_bsec.sensor:162]:     Unit of Measurement: 'ppm'
[09:11:17][C][bme68x_bsec.sensor:162]:     Accuracy Decimals: 1
[09:11:17][C][bme68x_bsec.sensor:162]:     Icon: 'mdi:test-tube'
[09:11:17][C][bme68x_bsec.sensor:163]:   Breath VOC Equivalent 'Breath VOC Equivalent'
[09:11:17][C][bme68x_bsec.sensor:163]:     Device Class: 'volatile_organic_compounds'
[09:11:17][C][bme68x_bsec.sensor:163]:     State Class: 'measurement'
[09:11:17][C][bme68x_bsec.sensor:163]:     Unit of Measurement: 'ppm'
[09:11:17][C][bme68x_bsec.sensor:163]:     Accuracy Decimals: 1
[09:11:17][C][bme68x_bsec.sensor:163]:     Icon: 'mdi:test-tube'
```

Schluggi, 2023-10-16:
> but gas_resistance sensor is gone now.

True. But this was also with the old BSEC the case. Did you really need this value? I have no clue what I should do with this value tbh

florianmulatz, 2023-10-17:
> Did you really need this value?

 Nope to be honest :) Just mentioning.

Cheers

Closed 2023-04-15.

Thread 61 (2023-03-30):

100nF Capacitor information

Triskae, 2023-03-30:
**Category**
- [ ] Some docs are wrong or outdated
- [X] I miss something the docs

**Description**
I realized that I forgot to include the LCSC number for the capacitor parts. While searching for the missing components on the LCSC website, I noticed that there are various versions available for this part. As my electronics knowledge is a little rusty, do you have any additional information about this part?

I assume that it is a Multilayer Ceramic Capacitor, but I'm not sure whether it is leaded or non-leaded. Also, what voltage rating should I use? On the LCSC website, I can see that there are several options available for the same capacitance - 50V, 100V, and 250V. Can you advise me on which voltage rating to choose?

I will update the documentation accordingly OF😄

Schluggi, 2023-03-31:
Reasonable question. This will be part of the BOM (#48).

The capacitor is only to improve readings. It should also work fine without (in most cases).

Leaded or non-leaded does not matter. If you care about the environment chose non-leaded. We use only voltages of max. 5V so anything above is fine. Yes "Multilayer Ceramic Capacitor" is correct.

I'll add a link later on.

Triskae, 2023-04-01:
Thanks a lot for your very clear answer ! 😄

Closed 2023-03-31.

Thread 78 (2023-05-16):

PIR not working on ESP8266

CappyT, 2023-05-16:
**Category**
- [?] Hardware / PCB
- [X ] Software / ESPHome

**Version of ESPHome / AIOsense**
ESPHome 2023.3.2 / 2.0.0 board

**Describe the bug**
The esp8266 (D1 Mini) PIR pins are configured incorrectly as reported by esphome, GPIO13 does not have an internal pulldown

```
Failed config

binary_sensor.gpio: [source /config/esphome/.esphome/packages/6d7fe4d6/esphome/packages/sensors/pir.yaml:6]
  platform: gpio
  name: PIR
  id: motion_pir
  pin:
    number: GPIO13

    Only GPIO16 supports pulldown.
    mode: INPUT_PULLDOWN
  device_class: motion
  filters:
    - delayed_on: 0s
    - delayed_off: 1s
```

I managed to fix 2 other small bugs for the esp8266 (D1 Mini), I don't know if i should send a PR.
- ESP8266 does not have a CPU Temp sensor: https://github.com/CappyT/AIOsense/commit/61ed64bc3006f23a878852ec2ce1a7103066be0a
- ESP8266 led is inverted: https://github.com/CappyT/AIOsense/commit/4c86ee17a23e1bcfa27a9f8556a6ca67bb76b7f6

How can I fix the PIR sensor? I don't know much about electronics, I just know enough about ESPHome

Schluggi, 2023-05-16:
You're welcome :)

ESP8266 are not in use at my flat, so I haven't test it yet. I've fixed the led and CPU Temp sensor based on your changes :)

I've also fixed the PIR ([9111b0f](https://github.com/Schluggi/AIOsense/commit/9111b0faa3e6b22412fb30729240165ae8f79c65)). A pulldown is not really necessary. It's only there because someone has problems with there PIR ([#52](https://github.com/Schluggi/AIOsense/issues/52#issuecomment-1488085553)).

You can try all fixes by changing the `refresh` interval to `1s` and recompile.

```yaml
packages:
  remote_package:
    url: https://github.com/schluggi/AIOsense
    ref: main
    refresh: 1d  # <--- change it to "1s"
```

CappyT, 2023-05-16:
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

Thank you for the quick fix, however the PIR stays always on... this is my main file:

`substitutions:
  name: "aiosense-gabry"  # lowercase only, have to be unique
  friendly_name: "AIOsense Camera Gabry"  # device name and entity prefix
  version: "2.0.0"  # your AIOsense version

  bh1750_update_interval: 5s

  bmex80_address: "0x76"  # for some modules you have to change it to 0x77
  bmex80_offset_humidity: "0"
  bmex80_offset_temperature: "0"
  bmex80_update_interval: 30s

  # bme680_bsec_sample_rate: lp # lp -> 3s, ulp ->5min
  # bme680_bsec_temperature_offset: "0"

  # ld2410_max_distance_move: 4.5m
  # ld2410_max_distance_still: 4.5m
  # ld2410_timeout: 5s

  # pir_delayed_off: 1s
  # pir_delayed_on: 0s
  pir_pin_mode: "INPUT"

packages:
  remote_package:
    url: https://github.com/schluggi/AIOsense
    ref: main
    refresh: 1s
    files:
      - esphome/packages/config/base.yaml

      # --- select your board ---
      # - esphome/packages/config/esp32-c3-mini.yaml
      # - esphome/packages/config/esp32-d1-mini.yaml
      # - esphome/packages/config/esp32-s2-mini.yaml
      - esphome/packages/config/esp8266-d1-mini.yaml

      # --- select your sensors ---
      - esphome/packages/sensors/bh1750.yaml
      # - esphome/packages/sensors/buzzer.yaml  # AIOsense >= 2.1.x only
      - esphome/packages/sensors/bme280.yaml  # enable for bme280
      # - esphome/packages/sensors/bme680.yaml  # disable for bme280
      # - esphome/packages/sensors/bme680_bsec.yaml  # does not work yet
      - esphome/packages/sensors/occupancy.yaml  # only if pir & mmWave are on
      - esphome/packages/sensors/pir.yaml
      # - esphome/packages/sensors/rgb_led.yaml  # esp32-c3-mini only
      - esphome/packages/sensors/led.yaml  # d1-mini only

      # --- select your radar sensor ---
      # - esphome/packages/sensors/ld2410.yaml
      - esphome/packages/sensors/sen0395.yaml

# Enable Home Assistant API
api:
  encryption:
    key: "ih3kU+z9htu/Toh8KE9r7vrxQd3+faKuyeLwfPiP6MQ="

ota:
  password: !secret password

wifi:
  ssid: !secret wifi_ssid
  password: !secret wifi_password
  # manual_ip:
  #   static_ip: 192.168.1.111
  #   subnet: 255.255.255.0
  #   gateway: 192.168.1.1

# bluetooth_proxy:`

CappyT, 2023-05-17:
After some digging, the problem boils down to the pulldown input. It needs to be there to prevent "floating" (idk if it's the correct term in electronics). My board has this kind of issue.

I'd leave this open (feel free to close it if you want), but I would try to put a physical resistor in the board for ESP8266 compatibility, I'll let you know how it will go.

Schluggi, 2023-07-26:
Closing because of inactivity

Closed 2023-07-26.

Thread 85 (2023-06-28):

Newbie has some questions / ideas

lougreenwood, 2023-06-28:
**Category**
- [x] Hardware / PCB
- [ ] Software / ESPHome

**Whats your idea?**
Hi, I'm a newbie to ESP32 & hardware in general (although I am a professional software dev, so I'm not completely naive).

I'm looking into building something like this, but I have a few unique requirements and I wondered if there was plans for anything similar with this project.

- Thread support, as far as I see, there is an ESP32 board with Thread incoming. I see that the FP2 went to wifi (I believe that the FP1 was Zigbee IIRC) and Aqara explained this as being because Zigbee didn't have the bandwidth for their sensor. I wondered if this device could realistically be run using Thread or would it have the same bandwidth limitations?
- I'm also considering hard wiring some sensors & using PoE. Can this sensor support the PoE ESP board (obviously the case won't fit this board version...)
- Are there any plans to build a waterproof version of the sensor? I would like to mount one in bathrooms, so having one with something similar to IPX4 would be useful for mounting in bathroom zone 2 or above. Has something like this been considered?

Thanks for creating this exciting project, I'm looking forward to hopefully using it as my springboard into building my own sensors & hardware to power my smart home! 🙇‍♂️

Schluggi, 2023-07-26:
Hi @lougreenwood,

thank you for your input and sorry for the late response (too many projects...).

- As far as I can see there is no ESPHome support for the ESP32-C6 and ESP32-H2 yet. If this will change in the future I've no problem to support them as well.
- PoE was already discussed [here](https://github.com/Schluggi/AIOsense/discussions/22#discussioncomment-5024127)
- I've one unit in my (very small) bathroom since 8 months and I can't see any sign of corrosion yet. So for bathroom applications its just fine I think. IPX4 is not that easy to achieve. If we just cover the whole unit in varnish (is this the right term in english?) the PCB would be very waterproof but a lot of the sensors would not work anymore.

To tease my future plans of this project: I want to include a speaker and a (working) mic. Not that easy in this size..

Closed 2023-08-05.

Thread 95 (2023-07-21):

esphome not compliling

Ghome79, 2023-07-21:
**Category**
- [ ] Hardware / PCB
- [ X] Software / ESPHome

**Version of ESPHome / AIOsense**
...

**Describe the bug**

it wont compile with s2 mini or c3 mini

```
INFO ESPHome 2023.7.0
INFO Reading configuration /config/esphome/s2-all.yaml...
Failed config

switch.template: [source /config/esphome/.esphome/packages/f7a0b76d/esphome/packages/sensors/sen0395.yaml:17]
  platform: template
  name: mmWave Sensor
  id: mmwave_sensor
  entity_category: config
  optimistic: True

  The restore_state option has been removed in 2023.7.0. Use the restore_mode option instead.
  restore_state: True
  assumed_state: True
  turn_on_action:
    - uart.write: sensorStart
    - delay: 1s
  turn_off_action:
    - uart.write: sensorStop
    - delay: 1s
switch.template: [source /config/esphome/.esphome/packages/f7a0b76d/esphome/packages/sensors/sen0395.yaml:31]
  platform: template
  name: mmWave LED
  id: mmwave_led
  entity_category: config
  optimistic: True

  The restore_state option has been removed in 2023.7.0. Use the restore_mode option instead.
  restore_state: True
  assumed_state: True
  turn_on_action:
    - switch.turn_off: mmwave_sensor
    - delay: 1s
    - uart.write: setLedMode 1 0
    - delay: 1s
    - uart.write: saveConfig
    - delay: 3s
    - switch.turn_on: mmwave_sensor
  turn_off_action:
    - switch.turn_off: mmwave_sensor
    - delay: 1s
    - uart.write: setLedMode 1 1
    - delay: 1s
    - uart.write: saveConfig
    - delay: 3s
    - switch.turn_on: mmwave_sensor
```

Schluggi, 2023-07-21:
Should be fixed (#96). Please confirm :)

afp316, 2023-07-21:
I was having this issue last night.  I just performed an update with the new config.  I can confirm it works.

Ghome79, 2023-07-22:
yes its working now.

i wanted to take the time and thank you for your time and effort.
 i also found another bug that i manage to fix myself.

c3 mini with ld2410 i had to reverse the tx rx pin to get the reading.
I made the changes on the esp32-c3-mini.yaml file,  not sure if its a cpu board related or just the  ld2410.yaml file.

not sure if you wanted a new post for this

Schluggi, 2023-07-24:
> i wanted to take the time and thank you for your time and effort.
no problem :)

> c3 mini with ld2410 i had to reverse the tx rx pin to get the reading.
Looks like the same as #97. I'll cover that soon :)

Closed 2023-07-21.

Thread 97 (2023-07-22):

LD2410 Sensors "Unknown" Status

afp316, 2023-07-22:
**Category**
- [ ] Hardware / PCB
- [X] Software / ESPHome

**Version of ESPHome / AIOsense**
ESPHome version 2023.7.0
Project Schluggi.AIOsense version 2.0.0

**AIOsense Configuration**
Lolin ESP32-C3 Mini
BME 680
BH1750
LD2410 mmWave
PIR
PCB V2.0-RC4 02/23

**Describe the bug**
Relates to PR #45.

Flashed the CPU with the appropriate config mods to my esp32-c3-mini.  See config below:

```
substitutions:
  name: "aio-garage"  # lowercase only, have to be unique
  friendly_name: "aio-garage"  # device name and entity prefix
  version: "2.0.0"  # your AIOsense version

  bh1750_update_interval: 5s

  bmex80_address: "0x77"  # for some modules you have to change it to 0x77
  # bmex80_offset_humidity: "0"
  # bmex80_offset_temperature: "0"
  # bmex80_update_interval: 30s

  # bme680_bsec_sample_rate: lp # lp -> 3s, ulp ->5min
  # bme680_bsec_temperature_offset: "0"

  ld2410_max_distance_move: 4.5m
  ld2410_max_distance_still: 4.5m
  ld2410_timeout: 5s

  pir_delayed_off: 1s
  pir_delayed_on: 0s

packages:
  remote_package:
    url: https://github.com/schluggi/AIOsense
    ref: main
    refresh: 1d
    files:
      - esphome/packages/config/base.yaml

      # --- select your board ---
      - esphome/packages/config/esp32-c3-mini.yaml
      # - esphome/packages/config/esp32-d1-mini.yaml
      # - esphome/packages/config/esp32-s2-mini.yaml
      # - esphome/packages/config/esp8266-d1-mini.yaml

      # --- select your sensors ---
      - esphome/packages/sensors/bh1750.yaml
      # - esphome/packages/sensors/buzzer.yaml  # AIOsense >= 2.1.x only
      # - esphome/packages/sensors/bme280.yaml  # enable for bme280
      - esphome/packages/sensors/bme680.yaml  # disable for bme280
      # - esphome/packages/sensors/bme680_bsec.yaml  # does not work yet
      - esphome/packages/sensors/occupancy.yaml  # only if pir & mmWave are on
      - esphome/packages/sensors/pir.yaml
      - esphome/packages/sensors/rgb_led.yaml  # esp32-c3-mini only
      # - esphome/packages/sensors/led.yaml  # d1-mini only

      # --- select your radar sensor ---
      - esphome/packages/sensors/ld2410.yaml
      #  - esphome/packages/sensors/sen0395.yaml

# Enable Home Assistant API
api:
  encryption:
    key: !secret aio_garage_api

ota:
  password: !secret aio_garage_ota

wifi:
  ssid: !secret wifi_ssid
  password: !secret wifi_password
  # manual_ip:
  #   static_ip: 192.168.1.111
  #   subnet: 255.255.255.0
  #   gateway: 192.168.1.1

# bluetooth_proxy:
```
Upload was successful.  All sensors worked except LD2410 as shown below with the "Unknown" status indicators:

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

**Recommended Solution**

Change the following uart config in packages/sensor/ld2410.yaml from this:
```
uart:
  # switching rx & tx is not a mistake but necessary
  tx_pin: "${uart_rx_pin}"
  rx_pin: "${uart_tx_pin}"
  baud_rate: 256000
  parity: NONE
  stop_bits: 1
```
To this:
```
uart:
  # enable for all cpu's but esp32-c3-mini
  # rx_pin: "${uart_tx_pin}"
  # tx_pin: "${uart_rx_pin}"
  # enable for esp32-c3-mini
  rx_pin: "${uart_rx_pin}"
  tx_pin: "${uart_tx_pin}"
  baud_rate: 256000
  parity: NONE
  stop_bits: 1
```
Result:
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

***My disclaimer is that I don't have any of the other cpu's so I can not confirm when you must swap the uart pins to enable coms with the LD2410.  This does work with the esp32-c3-mini though.***

Schluggi, 2023-07-24:
Some versions of the LD2410 needs to switch RX & TX and some not. I'll note this more in the docs

Closed 2023-07-26.

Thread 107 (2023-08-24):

exclude regions/ create zones

HiTilt-FPV, 2023-08-24:
**Category**
- Software / ESPHome

**Whats your idea?**
Adding a feature that allows to exclude specific regions in the fov of the mmwave sensor to be prohibited from occupation detection.

Example:
If AIOsense is mounted in the bedroom, it would be useful to remove the bed from occupation detection, so the light in the room will turn off if i lie in bed.
With zones, it could turn on the bedside lamp and turn off the ceiling lamp.

The aquara FP2 sensor for example can do something like that, but a little more advanced.

Schluggi, 2023-09-11:
Hi @HiTilt-FPV,

thank you for your input. You can try #112 which introduced up to 4 distance zones. Works ok-ish in my tests.

Zoning like the FP2 is really advanced and I don't know any mmWave sensor we could support to add this feature. If you know/find one, please let me know :)

HiTilt-FPV, 2023-09-19:
Hi @Schluggi,

as you suggested, i installed the version with distance zones yesterday. But i could not figure out what they do exactly! The new version gives up to 8 slider bars for configuring start and end distances for up to four zones.  But where do i get the output which of the four zones is actually occupied?
I can only activate the following sensors:
- 4x Target (binary sensors which seem to detect different persons)
- 4x Target distance (gives the distance measured to one of the targets)
- 4x Target SNR (target signal to noise... did not test it, but since it's SNR i bet it shows how "good/strong" the targed is detected or visible for the sensor)
- Distance Zone Status (this only tells me if the configured zones were successfully sent to the sensor. i do not get anything else from it.)

florianmulatz, 2023-11-15:
Hi,

ESPHome 2023.11.0 has been released today which includes direct support for sen0395 and also includes section configuration.

[ESPHome 2023.11.0 - Changelog](https://github.com/esphome/esphome/releases/tag/2023.11.0)

Cheers

Schluggi, 2023-11-15:
Thank you @florianmulatz for the update info. I'll add this soon. I just thinking, what would be the best way to implement...

Schluggi, 2023-11-18:
I'll close this issue since we using the official module in #123.

Closed 2023-11-18.

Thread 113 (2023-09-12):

sorry noob question

jangshik, 2023-09-12:
**Category**
- [v ] Hardware / PCB
- [ ] Software / ESPHome

**Whats your idea?**
...
691210910002 << what is this part used for?
I am trying to build the sensor with these components.

ESP32-C3 mini (PCB)
BME280(PCB)
HLK-LD2410C (PCB)
GY-302-BH1750 (PCB)
im going to skip pir sensor, and i  am in middle of ordering other parts. i was wondering what 691210910002 terminal block 2pos is intended for.

Thank you in advance.

jangshik, 2023-09-12:
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
im guessing its for this place, but is it required for esp32 c3 mini lolin?

Schluggi, 2023-09-12:
Hi,

the terminal block is optional to power up the board. It fits under the C3 mini but you can also power the board the via USB-C connector of the C3.

Does this answer your question? :)

jangshik, 2023-09-13:
thank you it solved my big question.
i made the order from AIOsense-v2.1.0.zip file so i think i should be fine.
thank you for this great project!

Closed 2023-09-13.

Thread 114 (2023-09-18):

More advanced Installation Mehtod for AIOsense

HiTilt-FPV, 2023-09-18:
**Categories:**
- HW: Case
- Mounting/Installation technique or method

**Description:**
I want to submit the installation technique i used to bring AIOsense devices to my household because i think it blends in very good with the surroundings.

**Method:**
**1.** I took the .stl file for the AIOsense stand and created an easy M3 Mount out of it. The advantage of this is that it is usable with typical M3 camera statives and other M3 mounting rigs! For example, i used this aluminum wall mounting rig for security cameras:

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
(source: [https://www.amazon.de/dp/B0B5Y4Z7KY?psc=1&ref=ppx_yo2ov_dt_b_product_details](url))

You can find the M3 Mount i designed and used together with some imagery showing an example installation from my home in the attached .zip file!

**2.** I also thought of a method to install AIOsense devices in a way that hides the cables neccessary for the voltage supply of the device. The final Installation (also using the M3 mount from 1.) looks like this:

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

This is what you need:

- XH-2A port and XH-2Y plug with crimp equipment (example: [https://www.amazon.de/Crimpwerkzeug-Set-Dechengbao-Dupont-Ratschen-Crimpzangen-Set-Steckern/dp/B09SWXF9Q6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](url)
- some white wire with dc positive and negative (example: [https://www.amazon.de/gp/product/B081QLJHX5/ref=ewc_pr_img_5?smid=A18X01B3A742H7&psc=1](url))
- a PCB (example: [https://www.amazon.de/Lochrasterplatte-Leiterplatte-Lochrasterplatine-Leiterplatten-Prototyping/dp/B08YXKRJY1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](url)
- A small DCDC dropdown voltage regulator (example: [https://www.amazon.de/gp/product/B0BN1N88F6/ref=ox_sc_act_title_6?smid=A1A7E5ILEFA1R3&psc=1](url))
- copper tape, 6mm wide (example: [https://www.amazon.de/dp/B09C1WPMZK?psc=1&ref=ppx_yo2ov_dt_b_product_details](url))
- mounting tape (example: [https://www.amazon.de/tesa-Tesa-Schaumstoff-Montageband-5X18-55714-0000-03/dp/B07F46SMV6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](url))
- some masking tape (example: [https://www.amazon.de/tesa-Malerband-einfache-Malerarbeiten-50mm/dp/B0014EFTWK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](url))
- You also need stuff to solder. Addtitionally, depending if the coppertape you use has an insulating adhesive (like the one i used and linked), you may need to solder the coppertape also!

1. You need to add the DCDC dropdown converters to your AIOsense. Glue it on the AIOsence PCB using the mounting tape. The general Idea is to use an 230v AC to 12v/24v DC converter from any smart home enabled LED lamp you want to install on the ceiling as the power supply for the AIOsense later on. This requires you to permanently power the ACDC powersupply of the LED you want to use, otherwise AIOsense would loose its powersource! Do not forget to set the DCDC converter to 5v output before glueing it into the AIOsense!!!
2. Solder the cable with a XH-2Y plug crimped to the 5v DCDC converter (i cut the cables to about 30cm but 20cm should be sufficient too). Since the case has no hole in it to fit the plug, you need to put the cable through one of the ventilation holes BEFORE soldering it to the 5v converter! Depending on components, the AIOsense may look something like this:

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

3. print the coppertape connectorbox and cut the pcb into pieces (about 18mm x 10mm, doesn't have to be perfect) that fit into the connectorbox. glue coppertape around the two ends of the pcb pieces and solder the XH-2A port to it. The poles of the port have to contact the copper tape.

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

4. glue the finished pcb's to the wall/ceiling/etc. close to where you want to install the AIOsense and another pcb where you put your voltagesource/LED ceilinglight.
5. connect the two pcb's electrically using the coppertape (watch out that you get the positive/negative polarity right!!!). depending on your coppertape, you may need to solder a bit! Thest the electrical connections afterwards! (i used a 12v acdc converter and an rgb led strip i had lying around to test if everything worked)
6. tape some masking tape above the coppertape wires (for physical protection, and you can color it using the exact same color from your wall/ceiling (for a mostly invisible installation). Also, you can put wallpaper over it later for a completely invisible installation! If you followed these steps corectly, your installation (befor coloring or putting wallpaper on) should look something like this:

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

A finished Installation looks like this (well, the lamp construction is not so final yet... ;-)):

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

More pictures in the attached .zip!

[aiosense_ceilingmount.zip](https://github.com/Schluggi/AIOsense/files/12647135/aiosense_ceilingmount.zip)

Schluggi, 2023-10-14:
Looks fancy and a bit over-engineered. I'll pin this issue so it's more likely to be found. Thank you for sharing :)

florianmulatz, 2023-10-31:
Those Camera -Holders are much cheaper at Temu -->

[TEMU](https://www.temu.com/at/2-wandhalterungen-kompatibel-mit-kreisformigen-klebe-kameras-und-kreisformigen-innenkameras-verstellbare-montagehalterungen-geeignet-fur-arlo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)

Closed 2023-10-14.

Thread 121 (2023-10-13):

Voice Assist and Wakeonword with INMP441

s-gordon, 2023-10-13:
**Category**
- [ ] Hardware / PCB
- [x] Software / ESPHome

Year of the Voice Chapter 4 introduces wakeonword. It would be great to take advantage of this with the INMP441 microphone in this project.
...

I have an INMP441 connected to a C3 Mini.

This is what I have so far as config as a starting point. Everything looks reasonable to my eyes, but I haven't been able to get this working yet.

```{yaml}
i2s_audio:
  id: i2s_in
  # i2s_lrclk_pin: GPIO5  # WS pin D1 Mini
  # i2s_bclk_pin: GPIO18  # SCK pin D1 Mini
  i2s_lrclk_pin: A5  # WS pin C3 Mini
  i2s_bclk_pin: A1  # SCK pin C3 Mini

microphone:
  - platform: i2s_audio
    i2s_din_pin: A0 # SD pin
    adc_type: external
    pdm: false
    id: mic_i2s
    i2s_audio_id: i2s_in

voice_assistant:
  microphone: mic_i2s
  on_start:
    - light.turn_on:
        id: led
        blue: 100%
        red: 0%
        green: 0%
        effect: none
  on_end:
    - delay: 1s
    - light.turn_off: led
  on_error:
    - light.turn_on:
        id: led
        blue: 0%
        red: 100%
        green: 0%
        effect: none
    - delay: 1s
    - light.turn_off: led
```

Schluggi, 2023-10-13:
Hi, we actually never tested the microphone. We add this for "future needs". But since the future is now I will tinker around with this in a few days.

If you are on v2.1.0 you can not use the microphone and the buzzer parallel. Since D6 is used for buzzer and microphone (we were out of pins).

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

Schluggi, 2023-10-22:
My working configuration for wake word detection. No problems with this. But make sure you have disconnect the beeper first. This issue will be addressed in hardware version 3.

I think you problem was the missing `start_continuous` part and the from microphone channel (default is `right` but since the PCB set L/R to GND, the channel is now `left`).

My config for ESP32-C3 mini (PCB version 2.1.0):
```yaml
i2s_audio:
  id: i2s_in
  i2s_lrclk_pin: A5  # WS
  i2s_bclk_pin: A1  # SCK

microphone:
  - platform: i2s_audio
    id: mic_i2s
    adc_type: external
    i2s_din_pin: A0  # SD
    i2s_audio_id: i2s_in
    pdm: false

voice_assistant:
  id: va
  microphone: mic_i2s
  noise_suppression_level: 2
  auto_gain: 31dBFS
  volume_multiplier: 2.0
  on_listening:
    - light.turn_on:
        id: led
        blue: 100%
        red: 0%
        green: 0%
        brightness: 100%
        effect: pulse
  on_tts_start:
    - light.turn_on:
        id: led
        blue: 0%
        red: 0%
        green: 100%
        brightness: 100%
        effect: pulse
  on_end:
    - delay: 100ms
    - script.execute: reset_led
  on_error:
    - light.turn_on:
        id: led
        blue: 0%
        red: 100%
        green: 0%
        brightness: 100%
        effect: none
    - delay: 1s
    - script.execute: reset_led
    - script.wait: reset_led
    - lambda: |-
        if (code == "wake-provider-missing" || code == "wake-engine-missing") {
          id(use_wake_word).turn_off();
        }

script:
  - id: reset_led
    then:
      - if:
          condition:
            - switch.is_on: use_wake_word
            - switch.is_on: listen_light
          then:
            - light.turn_on:
                id: led
                blue: 100%
                red: 100%
                green: 0%
                brightness: 100%
                effect: none
          else:
            - light.turn_off: led

switch:
  - platform: template
    name: "VA Use Wake Word"
    id: use_wake_word
    optimistic: true
    restore_mode: RESTORE_DEFAULT_ON
    entity_category: config
    on_turn_on:
      - lambda: id(va).set_use_wake_word(true);
      - if:
          condition:
            not:
              - voice_assistant.is_running
          then:
            - voice_assistant.start_continuous
      - script.execute: reset_led
    on_turn_off:
      - voice_assistant.stop
      - lambda: id(va).set_use_wake_word(false);
      - script.execute: reset_led

  - platform: template
    name: "VA Listen Light"
    id: listen_light
    optimistic: true
    restore_mode: RESTORE_DEFAULT_ON
    entity_category: config
    on_turn_on:
      - script.execute: reset_led
    on_turn_off:
      - script.execute: reset_led

esphome:
  min_version: 2023.10.0
  on_boot:
    - priority: -100
      then:
        - wait_until: api.connected
        - delay: 1s
        - if:
            condition:
              switch.is_on: use_wake_word
            then:
              - voice_assistant.start_continuous:

```

Ghome79, 2023-10-30:
well hello, I've tested the above config with my c3 mini and without buzzer and i cant get my microphone to work. i have installed and setup openwakeword. piper, and whisper. i also tried 4 different microphones. i believe i cant get it to listen cause my rbg led stay purple

Ghome79, 2023-11-01:
Thx for fast reply
ill let you know where I'm at with 1 full day of testing.

All my testing is done with all sensor disabled,
I know my pipeline assist works via web

esp-s2 sorta works cuz I need to shout into mic to enable it. very frustrating
esp-c3 doesn't work even if I shout with the same mic  and setting

Closed 2023-10-22.

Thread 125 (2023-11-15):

change to ESPHome integrated sen0935 feature

florianmulatz, 2023-11-15:
**Category**
- [ ] Hardware / PCB
- [X] Software / ESPHome

**What would you like to improve?**
I would suggest to use the "own" integrated ESPHome feature for driving the sen0395 sensor so no specific effort is needed to take care on an own integration.

[Changelog](https://github.com/esphome/esphome/releases/tag/2023.11.0)

Cheers

Schluggi, 2023-11-15:
Hi @florianmulatz, thank you for noticing. I just replaced it. Feel free to give feedback in #123.

florianmulatz, 2023-11-21:
> Hi @florianmulatz, thank you for noticing. I just replaced it. Feel free to give feedback in #123.

Working perfectly! - Automatically created configuration for 3 individual segments.

Closed 2023-11-15.

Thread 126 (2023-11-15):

[Feature Request] SSD1306 OLED Display Support in V3

lukas-holzner, 2023-11-15:
**Category**
- [ x ] Hardware / PCB
- [ x ] Software / ESPHome

**Whats your idea?**
I played around with these small and inexpensive OLED Displays (https://esphome.io/components/display/ssd1306) and thought they might be a great addition to AIOSense. I think it would be great to see some of the values of the sensors directly  on the AIO Sense without having to set up extra devices with screens.

Some things you could display on the display

- Temperature, Humidity, Pressure,
- Voice Assistant Answers for deaf people
- Notifications from Homeassistant
- Weather
- RSS Feeds (Scrolling text)
- Occupancy status
- House Alarm status (Armed or not armed)

Here is a Picture of the screen showing Sensor Values from ESP Home
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

I know space is tight on the board. Maybe we can squeeze it onto the IO extensions and release an additional case Verison that can handle the screen on the bottom. That way we don't have to make the PCB bigger.
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

This is the test code for the display i used:
``` yaml
font:
  # gfonts://family[@weight]
  - file: "gfonts://Roboto"
    id: roboto
    size: 12
display:
  - platform: ssd1306_i2c
    model: "SSD1306 128x64"
    reset_pin: D0
    address: 0x3C
    lambda: |-
      // %% - literal % sign
      it.printf(0, 0, id(roboto), "Temperature: %.1f°C", id(temperature).state);
      it.printf(0, 15, id(roboto), "Humidity: %.1f%%", id(humidity).state);
      it.printf(0, 30, id(roboto), "Pressure: %.1fhPa", id(pressure).state);
```
The Sensor code also needs to be modified to have an id
Example for the BME280
``` yaml
sensor:
  - platform: bme280
    id: bme280_sensor
    address: "${bmex80_address}"
    update_interval: "${bmex80_update_interval}"
    temperature:
      name: "Temperature"
      id: temperature
      filters:
        - offset: ${temperature_offset}
        - lambda: "return x + id(temperature_offset_ui).state;"
    humidity:
      name: "Humidity"
      id: humidity
      filters:
        - offset: ${humidity_offset}
        - lambda: "return x + id(humidity_offset_ui).state;"
    pressure:
      name: "Pressure"
      id: pressure
      filters:
        - offset: ${pressure_offset}
        - lambda: "return x + id(pressure_offset_ui).state;"
```

Schluggi, 2025-02-02:
I will close this because it seems a bit out of scope right now. Feel free to send an PR if your config is ready.

Closed 2025-02-02.

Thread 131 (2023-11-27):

Evaluate Microphone

Schluggi, 2023-11-27:
Is issue is about finding a good microphone that does not suck and is affordable.
It has to be an I²S microphone

## Results
### [INMP441](https://de.aliexpress.com/item/32962426410.html)
- (+) Already supported
- (+) Works well
- (+) Recommendation from HA
- (-) The legit TDK INMP441 part seems to be EOL, so it is very unclear as to the origin of these mics.

### [SPM1423](https://shop.m5stack.com/products/pdm-microphone-unit-spm1423?ref=NabuCasa)
- (wip)
- (+) Recommendation from HA
- (-) Pre-Cased and a bit bulky

mourix, 2023-12-20:
I obtained the ATOM Echo which integrates the SPM1423. and compared it to the INMP441. In my breadboard testing, I have found no significant differences between the two. Both have a similar success rate when looking at the speech to text result in the ESPhome logs.

A new contender is the [Sipeed I2S Mic Module](https://www.seeedstudio.com/Sipeed-I2S-Mic-for-MAIX-Dev-Boards-p-2887.html):

- (+) Smaller size compared to other sensors
- (+) Similar quality to other sensors
- (+) Widely available
- (-) Variations on Aliexpress swap the VCC and GND pins. So people will have to be careful when ordering.

Closed 2023-12-26.

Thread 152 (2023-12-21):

Error on updating to latest ESPHome 2023.12.0

florianmulatz, 2023-12-21:
**Category**
- [ ] Hardware / PCB
- [X] Software / ESPHome

**Version of ESPHome / AIOsense**
ESPHome 2023.12.0

**Describe the bug**
```
INFO ESPHome 2023.12.0
INFO Reading configuration /config/esphome/esphome-mmwave-wohnzimmer.yaml...
WARNING GPIO8 is a strapping PIN and should only be used for I/O with care.
Attaching external pullup/down resistors to strapping pins can cause unexpected failures.
See https://esphome.io/guides/faq.html#why-am-i-getting-a-warning-about-strapping-pins
WARNING GPIO2 is a strapping PIN and should only be used for I/O with care.
Attaching external pullup/down resistors to strapping pins can cause unexpected failures.
See https://esphome.io/guides/faq.html#why-am-i-getting-a-warning-about-strapping-pins
Failed config

output.ledc: [source <unicode string>:4]

  Pin 0 is used in multiple places.
  platform: ledc
  pin:
    number: 0
    mode:
      output: True
      input: False
      open_drain: False
      pullup: False
      pulldown: False
    inverted: False
    ignore_strapping_warning: False
    drive_strength: 20.0
  id: rtttl_out
  zero_means_zero: False
  frequency: 1000.0
microphone.i2s_audio: [source <unicode string>:7]

  Pin 0 is used in multiple places.
  platform: i2s_audio
  id: mic_i2s
  channel: left
  i2s_din_pin: 0
  i2s_audio_id: i2s_in
  pdm: False
  bits_per_sample: 32.0
  adc_type: external
== [ERROR] /config/esphome/esphome-mmwave-wohnzimmer.yaml ==
```

Schluggi, 2023-12-26:
This is (kind of) by design. In V2.1.x the buzzer/beeper and the mic has the same pin so you have to choose what do you want to use. You can not use both at the same time. This will be fixed in V3.0.0.

Closed 2023-12-26.

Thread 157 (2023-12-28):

esp32 - s3 with video feed

Ghome79, 2023-12-28:
i found this board on aliexpress and would be amazing to have video feed too.

it has a mic, 8MB PSRAM ,16MB FLASH and sd card slot

i just ordered one. i'm curious

https://www.aliexpress.com/item/1005006099376239.html?spm=a2g0o.cart.0.0.45d438daX6dCVq&mp=1

Schluggi, 2023-12-31:
Thank you for the suggestion.

Camera support could be evaluated but not with the ESPS3-Cam board. AIOsense V3.0.0 is almost ready and used the generic S3 mini because we want backwards compatibility. So switching to a complete new board is not really an option for us right now.

Moreover a camera stream needs a lot of CPU load and it might be too heavy for the CPU.

So we can test this later on after releasing V3.0.0.

Closed 2025-01-28.

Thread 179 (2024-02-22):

ESPHome 2024.2.0 change to BME280

sarreck, 2024-02-22:
**Category**
- [ ] Hardware / PCB
- [ X] Software / ESPHome

**Version of ESPHome / AIOsense**
Latest

**Describe the bug**
The latest release of ESPHome "ESPHome 2024.2.0" has a breaking change in the BME280 component.

I believe that the esphome/packages/sensors/bme280.yaml file needs to be updated as advised below.

From the docs:

_Breaking change notes: The original bme280 component has been renamed to bme280_i2c for consistency with other platforms. To update your configuration, simply replace bme280 with bme280_i2c. No other changes are required.__

https://github.com/esphome/esphome/pull/5538

Schluggi, 2024-02-25:
Thank you for noticing.

Fixed in the latest release by #180:
https://github.com/Schluggi/AIOsense/releases/tag/esphome-v3.0.1

Closed 2024-02-25.

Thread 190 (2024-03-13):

ESP32-S3 Support with microWakeWord

AnthonyPluth, 2024-03-13:
**Category**
- [x] Hardware / PCB
- [x] Software / ESPHome

**Whats your idea?**
With ESPHome now supporting on-device wake word detection (https://www.home-assistant.io/blog/2024/02/21/voice-chapter-6/), it would be awesome to add support for ESP32-S3 with microWakeWord onboard. Happy to collaborate on this work, as well.

lukas-holzner, 2024-06-26:
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

microWakeWord needs the PSRAM which needs GPIO Pins 33 to 37. Unfortunatly we are currently using some of those pins for the microphone and speakers so a redesign of the pcb would be needed.

AnthonyPluth, 2024-06-26:
Are there free pins on the ESP32-S3 that could be utilized instead (with PCB redesign)?

s-gordon, 2025-01-27:
@AnthonyPluth I'm looking at redesigning the PCB to free up those PSRAM pins. I've done a little probing over the last few days to see what pins might make sense. This is what I am thinking (using the [S3 Mini layout](https://www.wemos.cc/en/latest/s3/s3_mini.html)). Thoughts?

- SCL -> GPIO16
- SDA -> GPIO18
- I2S data out (speaker): GPIO17
- I2S data in (mic): GPIO21
- I2S LRCLK: GPIO12

AnthonyPluth, 2025-01-27:
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

I'm probably the wrong person to ask for this. However, in my experience, the S3 Mini seems to be a bit light on RAM. IMO, it's worth upgrading to an ESP32-S3 N16R8V. Unfortunately, that requires increasing the size of the board, but it would allow you to place the speaker on the front of the board instead of the back.

Schluggi, 2025-02-02:
No redesign needed. It works "just fine" with the current pinout.

But the PSRAM is indeed to small and fully filled by just the wake word detection. Therefore I just contacted Lolin (the vendor of the S3-mini). I'll be back after getting response.

Moreover `micro_wake_word` uses the newer `esp-idf` framework instead of the current used arduino framework. Most components could be migrated, but [BSEC would not be available for now.](https://github.com/esphome/feature-requests/issues/2431).

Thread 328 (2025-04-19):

Unable to see LD2410C data

silviudc, 2025-04-19:
I have an odd issue or maybe a bad config? I have printed out the PCB for the S3 minis and I have the following sensors attached: BME680, GY-302 and the LD2410c
My LD2410c is being detected as a BT device and I can add it separately and seems to work but under the aiosensor esphome device it does not, any idea what I'm doing wrong?

See below for esphome yaml:

```
substitutions:
  name: "aiosense-bedroom"  # lowercase only, have to be unique
  friendly_name: "AIOsense Bedroom"  # device name and entity prefix
  bme_address: "0x77"

  # bh1750_update_interval: 5s

  # bme_address: "0x76"  # for some modules you have to change it to 0x77
  # bme_update_interval: 30s

  # co2_offset: "0"  # bsec only
  # humidity_offset: "0"
  # iaq_offset: "0" # bsec only
  # illuminance_offset: "0"
  # pressure_offset: "0"
  temperature_offset: "-6"
  # voc_offset: "0" # bsec only

  # LD2410(c) does not work? Please notice:
  # https://aiosense.readthedocs.io/en/latest/debugging/#ld2410c-does-not-work

  # pir_delayed_off: 1s
  # pir_delayed_on: 0s

  # led_strobe_on: 50ms   # controls the strobe effect if rgb_led or led is enabled
  # led_strobe_off: 100ms

packages:
  remote_package:
    url: https://github.com/schluggi/AIOsense
    ref: esphome-v3.0.1
    refresh: 1d
    files:
      - esphome/packages/config/base.yaml

      # ----- board -----
      # - esphome/packages/config/esp32-c3-mini.yaml
      # - esphome/packages/config/esp32-d1-mini.yaml
      # - esphome/packages/config/esp32-s2-mini.yaml
      - esphome/packages/config/esp32-s3-mini.yaml
      # - esphome/packages/config/esp8266-d1-mini.yaml

      # ----- modules -----
      - esphome/packages/sensors/bh1750.yaml
      # - esphome/packages/sensors/bme280.yaml  # enable for bme280
      # - esphome/packages/sensors/bme680.yaml  # disable for bme280
      - esphome/packages/sensors/bme68x_bsec.yaml  # disable for bme280
      - esphome/packages/sensors/buzzer.yaml  # PCB >= v2.1.0
      - esphome/packages/sensors/occupancy.yaml  # only if pir & mmWave are activated
      - esphome/packages/sensors/pir.yaml

      # ----- voice assistant (use rgb_led for esp32-c3 & esp32-s3 only-----
      # - esphome/packages/sensors/voice_assistant-rgb_led.yaml
      # - esphome/packages/sensors/voice_assistant-led.yaml

      # ----- led modules (use rgb_led for esp32-c3 & esp32-s3 only) -----
      - esphome/packages/sensors/rgb_led.yaml
      # - esphome/packages/sensors/led.yaml
      # - esphome/packages/sensors/status_led.yaml

      # ----- mmWave radar sensor -----
      - esphome/packages/sensors/ld2410.yaml
      #- esphome/packages/sensors/sen0395.yaml

# Enable Home Assistant API
api:
  encryption:
    key: "xxx"

ota:
  - platform: esphome
    password: "xxx"

wifi:
  ssid: !secret wifi_ssid
  password: !secret wifi_password

# Enable logging
logger:
```

I assume  https://aiosense.readthedocs.io/en/latest/debugging/#ld2410c-does-not-work doesn't help because the sensor is being detected by BT and works independently

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

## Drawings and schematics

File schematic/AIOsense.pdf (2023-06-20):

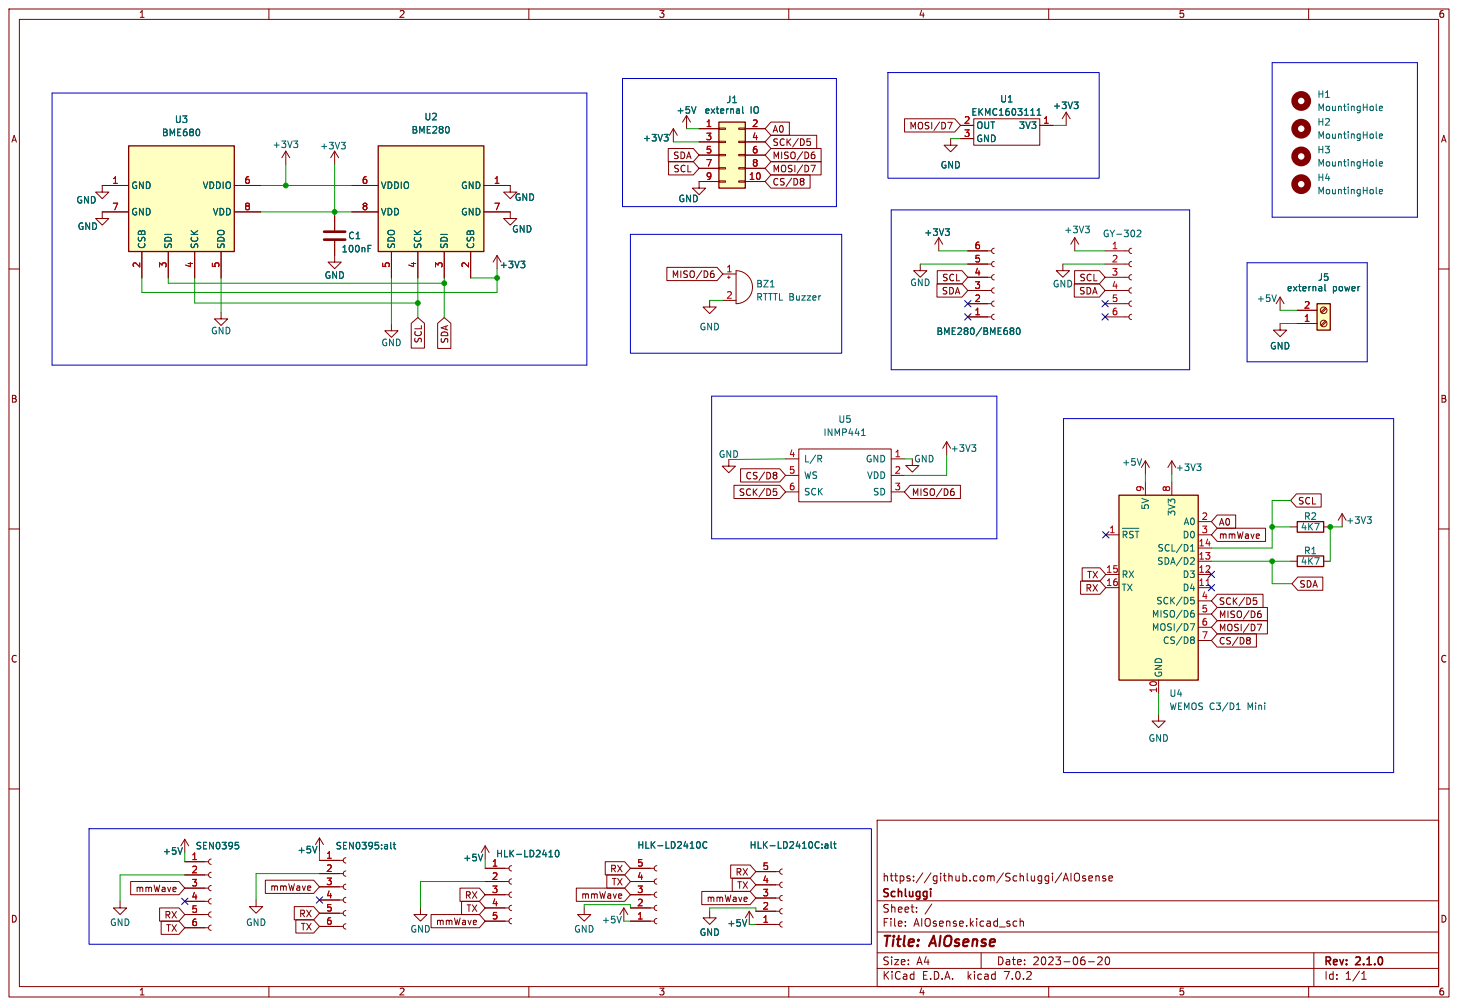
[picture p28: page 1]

5 VDDIO 6 GND 7 VDD 8 GND GND +3V3 +3V3 U1 EKMC1603111

5 VDDIO 6 GND 7 VDD 8 U3 BME680 GND GND

5 VDDIO 6 GND 7 VDD 8 U2 BME280 GND 1 CSB

5 VDDIO 6 GND 7 VDD 8 GND

https://github.com/Schluggi/AIOsense
File: AIOsense.kicad_sch Sheet: / Schluggi

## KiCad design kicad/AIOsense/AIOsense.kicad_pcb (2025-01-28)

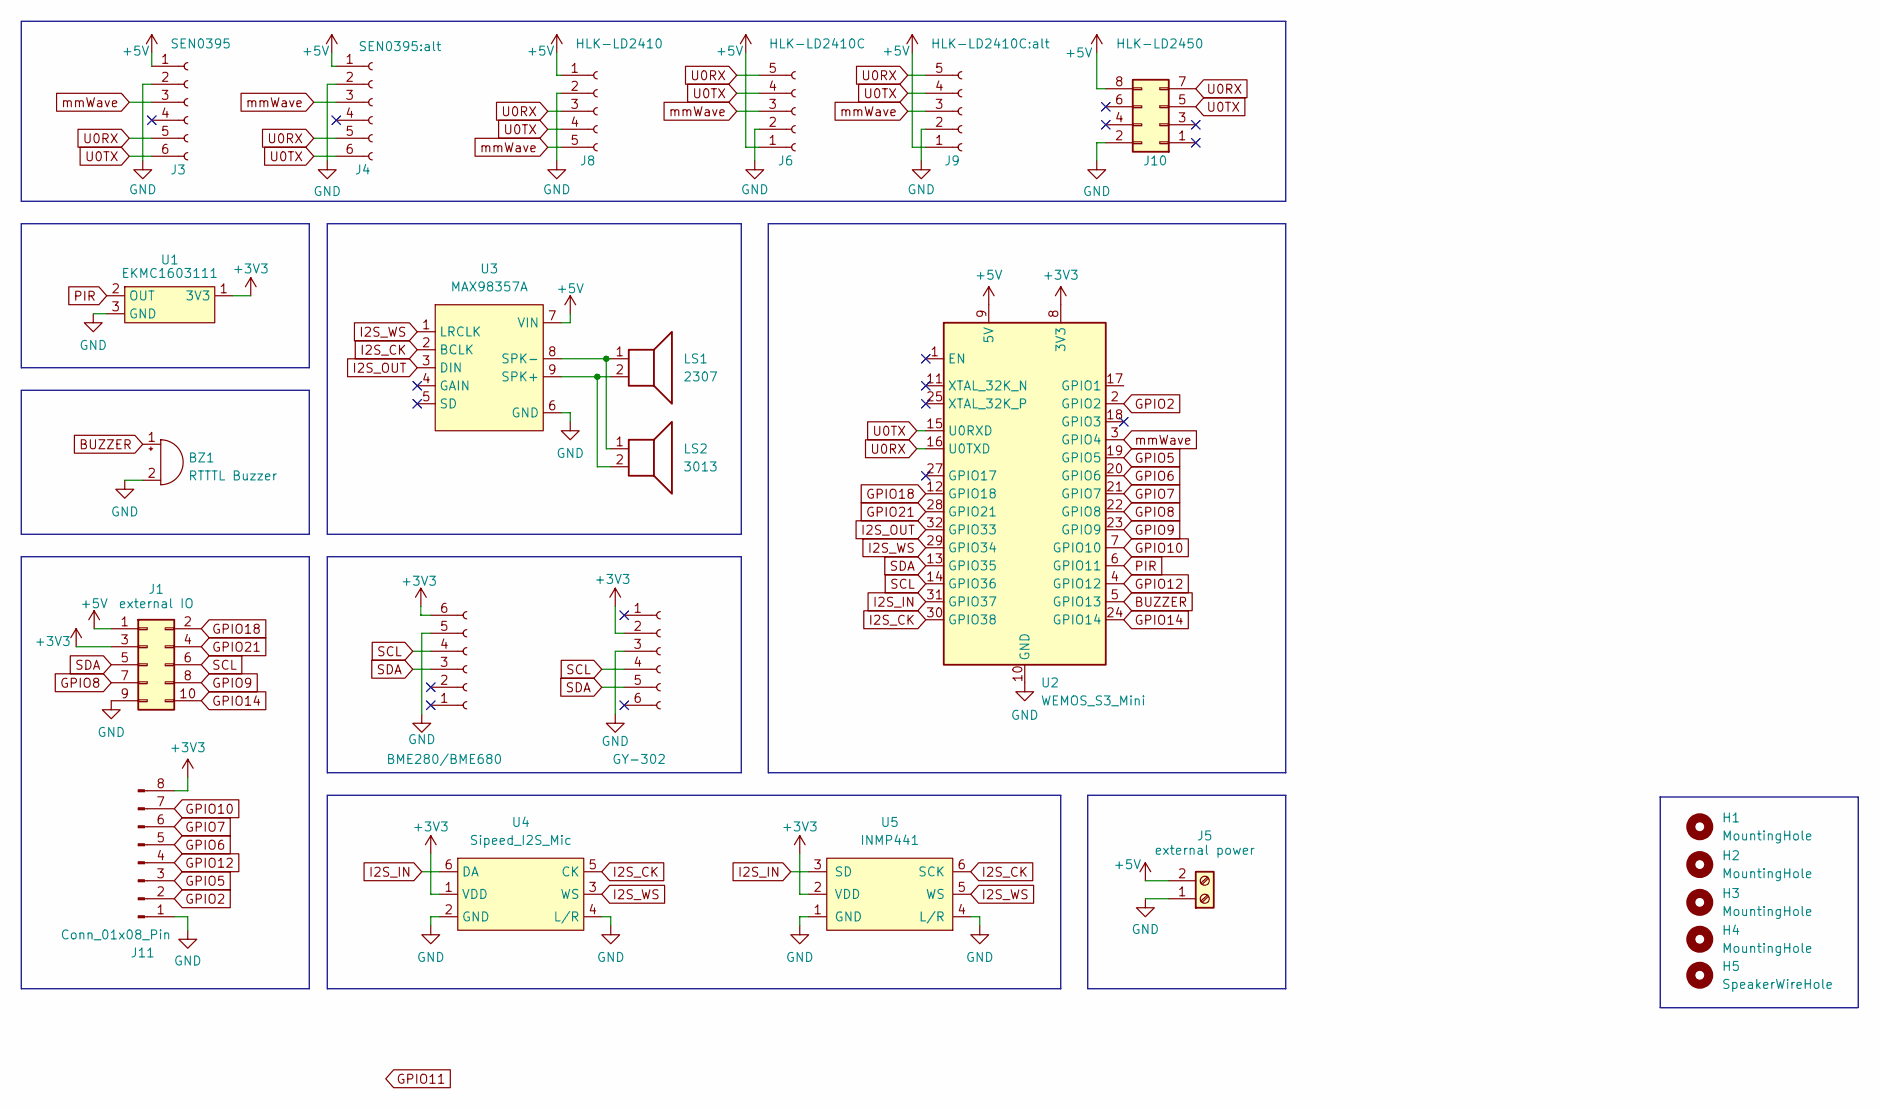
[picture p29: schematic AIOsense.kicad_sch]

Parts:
BZ1: RTTTL Buzzer; Buzzer_D12mm_P6.5mm
H1, H2, H3, H4: MountingHole; MountingHole_3.2mm_M3_DIN965_Pad
H5: SpeakerWireHole; Hole_Unplated_3.0mm
J1: external IO; PinHeader_2x05_P2.54mm_Vertical
J2: GY-302; PinSocket_1x06_P2.54mm_Vertical
J3: SEN0395; PinSocket_1x06_P2.54mm_Vertical; Manufacturer_Part_Number SEN0395; Digikey Part # 1738-SEN0395-ND
J4: SEN0395:alt; PinSocket_1x06_P2.54mm_Vertical; Manufacturer_Part_Number SEN0395; Digikey Part # 1738-SEN0395-ND
J5: external power; TerminalBlock_TE_282834-2_1x02_P2.54mm_Horizontal; Manufacturer_Part_Number 691210910002; Digikey Part # 732-691210910002-ND
J6: HLK-LD2410C; PinSocket_1x05_P2.54mm_Vertical; Manufacturer_Part_Number LD2410; Digikey Part # /
J7: BME280/BME680; PinSocket_1x06_P2.54mm_Vertical
J8: HLK-LD2410; PinSocket_1x05_P1.27mm_Vertical; Manufacturer_Part_Number LD2410; Digikey Part # /
J9: HLK-LD2410C:alt; PinSocket_1x05_P2.54mm_Vertical; Manufacturer_Part_Number LD2410; Digikey Part # /
J10: HLK-LD2450; PinSocket_2x04_P2.00mm_Vertical
J11: Conn_01x08_Pin; PinHeader_1x08_P2.54mm_Vertical
LS1: 2307; Speaker_2307
LS2: 3013; Speaker_3013
U1: EKMC1603111; PIR_EKMC1603111_TO-5; Manufacturer_Part_Number EKMC1603111; Digikey Part # 255-3086-ND
U2: WEMOS_S3_Mini
U3: MAX98357A; Adafruit_MAX98357A
U4: Sipeed_I2S_Mic
U5: INMP441; Manufacturer_Part_Number INMP441ACEZ-R7; Digikey Part # obsolete

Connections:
+3V3: J1.3, J2.2, J7.6, J11.8, U1.1 (3V3), U2.8 (3V3), U4.1 (VDD), U5.2 (VDD)
+5V: J1.1, J3.1, J4.1, J5.2, J6.1, J8.1, J9.1, J10.8, U2.9 (5V), U3.7 (VIN)
BUZZER: BZ1.1 (-), U2.5 (GPIO13)
GND: BZ1.2 (+), J1.9, J2.3, J3.2, J4.2, J5.1, J6.2, J7.5, J8.2, J9.2, J10.2, J11.1, U1.3 (GND), U2.10 (GND), U2.26 (GND), U3.6 (GND), U4.2 (GND), U4.4 (L/R), U5.1 (GND), U5.4 (L/R)
GPIO2: J11.2, U2.2 (GPIO2)
GPIO5: J11.3, U2.19 (GPIO5)
GPIO6: J11.5, U2.20 (GPIO6)
GPIO7: J11.6, U2.21 (GPIO7)
GPIO8: J1.7, U2.22 (GPIO8)
GPIO9: J1.8, U2.23 (GPIO9)
GPIO10: J11.7, U2.7 (GPIO10)
GPIO12: J11.4, U2.4 (GPIO12)
GPIO14: J1.10, U2.24 (GPIO14)
GPIO18: J1.2, U2.12 (GPIO18)
GPIO21: J1.4, U2.28 (GPIO21)
I2S_CK: U2.30 (GPIO38), U3.2 (BCLK), U4.5 (CK), U5.6 (SCK)
I2S_IN: U2.31 (GPIO37), U4.6 (DA), U5.3 (SD)
I2S_OUT: U2.32 (GPIO33), U3.3 (DIN)
I2S_WS: U2.29 (GPIO34), U3.1 (LRCLK), U4.3 (WS), U5.5 (WS)
unnamed: LS1.2, LS2.2, U3.9 (SPK+)
unnamed: LS1.1, LS2.1, U3.8 (SPK-)
PIR: U1.2 (OUT), U2.6 (GPIO11)
SCL: J1.6, J2.4, J7.4, U2.14 (GPIO36)
SDA: J1.5, J2.5, J7.3, U2.13 (GPIO35)
U0RX: J3.5, J4.5, J6.5, J8.3, J9.5, J10.7, U2.16 (U0TXD)
U0TX: J3.6, J4.6, J6.4, J8.4, J9.4, J10.5, U2.15 (U0RXD)
mmWave: J3.3, J4.3, J6.3, J8.5, J9.3, U2.3 (GPIO4)

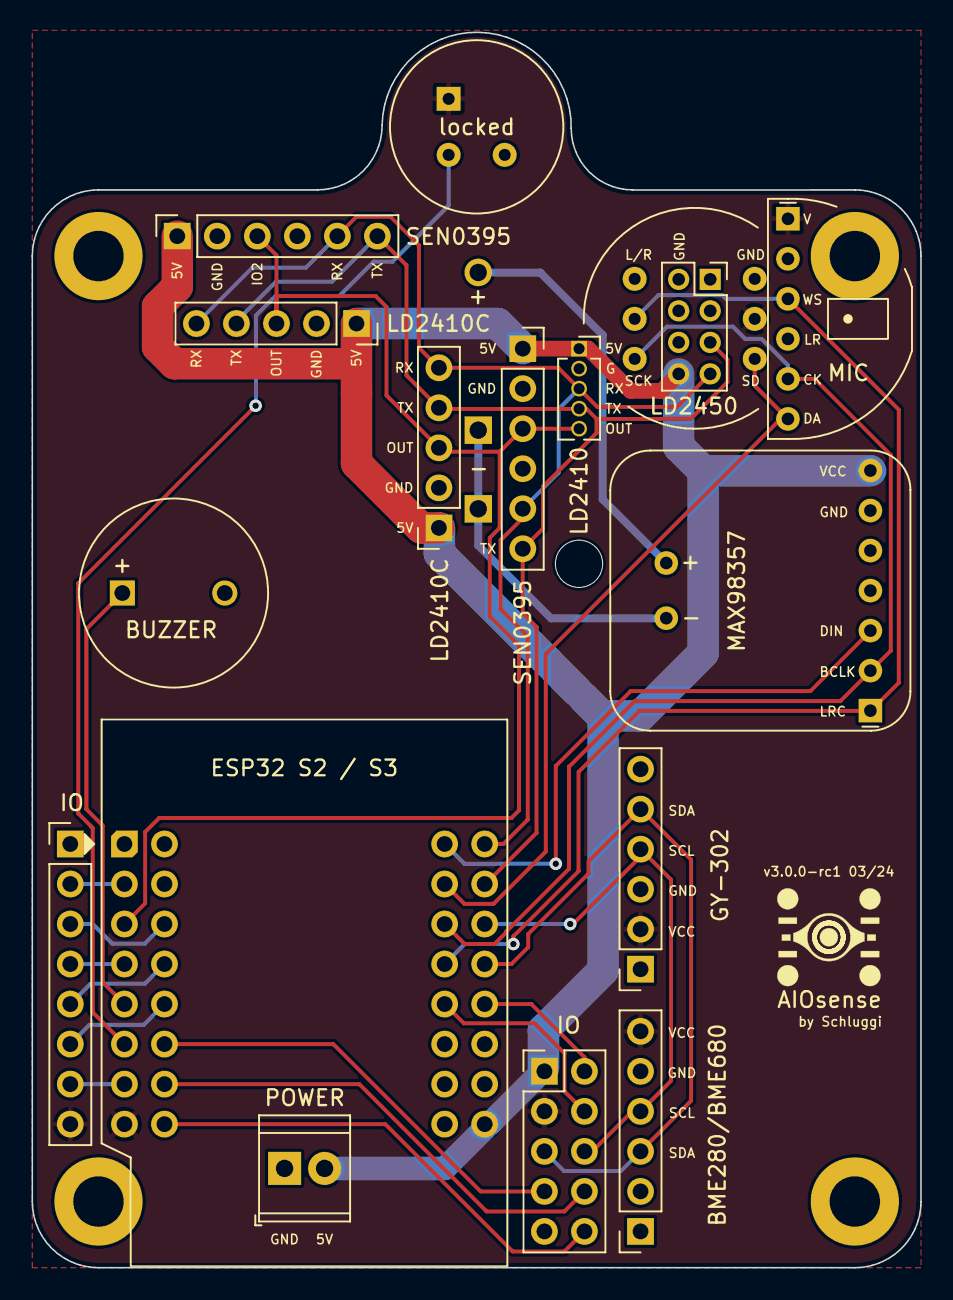
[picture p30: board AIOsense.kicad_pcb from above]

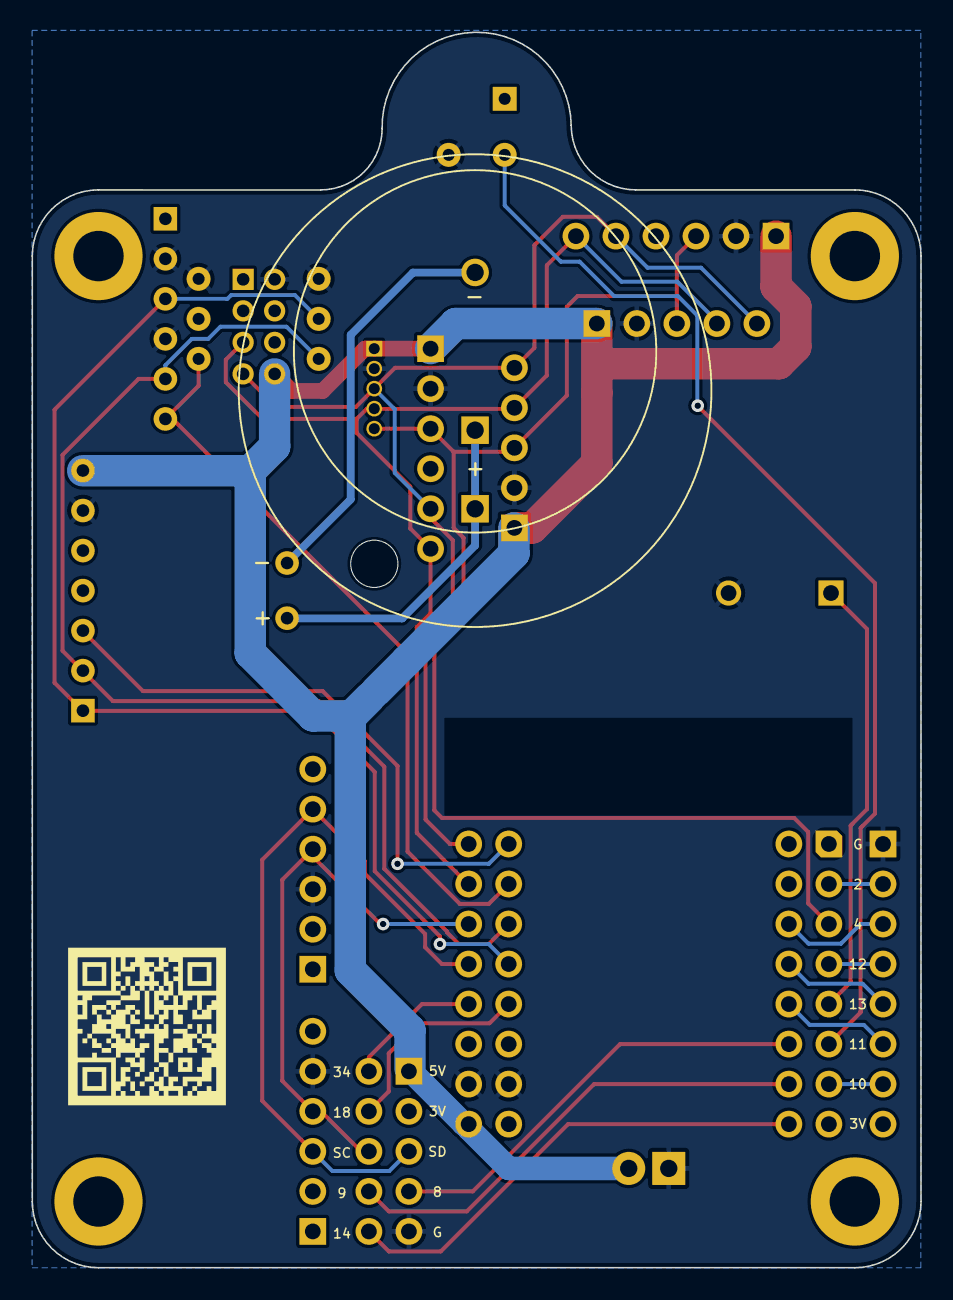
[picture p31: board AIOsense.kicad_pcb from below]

Board: 2 copper layers, 56.4 x 78.4 mm, 24 parts (2 on the bottom side), 27 nets.

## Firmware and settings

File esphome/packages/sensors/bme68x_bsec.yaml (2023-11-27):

substitutions:
  bme_address: "0x76"
  co2_offset: "0"
  humidity_offset: "0"
  iaq_offset: "0"
  pressure_offset: "0"
  temperature_offset: "0"
  voc_offset: "0"

external_components:
  - source: github://schluggi/esphome@dev
    components:
      - bme68x_bsec

bme68x_bsec:
  address: "${bme_address}"
  bsec_configuration: 0,0,2,2,189,1,0,0,0,0,0,0,213,8,0,0,52,0,1,0,0,192,168,71,64,49,119,76,0,0,97,69,0,0,97,69,137,65,0,63,0,0,0,63,0,0,64,63,205,204,204,62,10,0,3,0,216,85,0,100,0,0,96,64,23,183,209,56,28,0,2,0,0,244,1,150,0,50,0,0,128,64,0,0,32,65,144,1,0,0,112,65,0,0,0,63,16,0,3,0,10,215,163,60,10,215,35,59,10,215,35,59,13,0,5,0,0,0,0,0,100,35,41,29,86,88,0,9,0,229,208,34,62,0,0,0,0,0,0,0,0,218,27,156,62,225,11,67,64,0,0,160,64,0,0,0,0,0,0,0,0,94,75,72,189,93,254,159,64,66,62,160,191,0,0,0,0,0,0,0,0,33,31,180,190,138,176,97,64,65,241,99,190,0,0,0,0,0,0,0,0,167,121,71,61,165,189,41,192,184,30,189,64,12,0,10,0,0,0,0,0,0,0,0,0,173,6,11,0,1,2,2,207,61,208,65,149,110,24,66,180,108,177,65,219,148,13,192,70,132,58,66,163,58,140,192,12,99,178,192,185,59,255,193,178,213,175,63,0,0,0,0,0,0,0,0,0,0,0,0,0,0,0,0,0,0,0,0,0,0,0,0,0,0,0,0,0,0,0,0,0,0,0,0,0,0,0,0,0,0,0,0,110,211,55,195,237,6,56,67,0,0,0,0,0,0,0,0,26,3,255,63,61,246,7,192,171,201,228,192,249,144,215,63,237,199,104,193,128,158,216,64,117,140,155,63,137,120,129,67,108,109,253,191,0,0,0,0,81,64,57,68,103,241,231,64,109,29,152,192,209,43,193,63,93,54,30,65,197,46,92,64,128,27,224,192,6,20,144,191,56,179,130,64,0,0,0,0,43,156,59,196,33,217,100,194,104,77,72,65,15,103,175,191,249,252,12,193,63,117,253,192,233,5,141,65,155,42,25,64,13,88,249,191,0,0,0,0,48,141,122,190,204,150,44,192,36,162,29,193,96,59,39,189,54,202,48,65,151,205,68,64,79,105,55,193,53,120,53,192,77,211,32,192,0,0,0,0,193,207,92,65,239,201,76,65,208,70,82,66,81,63,96,65,48,179,0,194,251,96,242,193,176,51,96,194,153,114,98,66,144,247,64,65,0,0,0,0,219,179,180,63,175,218,119,191,51,71,207,191,245,145,129,63,53,16,244,65,138,208,117,65,138,97,36,66,228,15,32,195,126,91,103,191,0,0,0,0,26,151,170,193,64,105,49,193,46,223,189,193,129,203,168,193,40,91,49,66,4,87,107,65,205,202,37,65,244,36,154,66,240,85,39,193,0,0,0,0,166,96,87,192,114,7,68,191,233,32,214,63,84,249,40,192,45,78,132,64,145,33,253,61,49,43,187,192,244,32,77,67,224,250,71,191,0,0,0,0,103,75,214,190,206,141,252,63,99,15,178,65,80,79,166,190,214,25,146,192,165,29,24,194,18,228,219,193,113,246,235,194,49,115,232,63,0,0,0,0,17,211,124,64,56,252,251,62,25,118,148,193,168,234,94,64,131,157,82,64,217,119,236,65,120,245,240,65,17,69,168,195,49,51,8,63,0,0,0,0,0,0,0,0,0,0,0,0,0,0,0,0,0,0,0,0,0,0,0,0,0,0,0,0,0,0,0,0,0,0,0,0,0,0,0,0,0,0,0,0,0,0,0,0,0,0,0,0,0,0,0,0,0,0,0,0,0,0,0,0,0,0,0,0,0,0,0,0,0,0,0,0,0,0,0,0,0,0,0,0,0,0,0,0,0,0,0,0,0,0,0,0,0,0,0,0,0,0,0,0,0,0,0,0,0,0,0,0,0,0,0,0,0,0,0,0,0,0,0,0,0,0,0,0,0,0,0,0,0,0,0,0,0,0,0,0,0,0,0,0,0,0,0,0,0,0,0,0,0,0,0,0,0,0,0,0,0,0,0,0,0,0,0,0,0,0,0,0,0,0,0,0,0,0,0,0,0,0,0,0,0,0,0,0,0,0,0,0,0,0,0,0,0,0,0,0,0,0,0,0,0,0,0,0,0,0,0,0,0,0,0,0,0,0,0,0,0,0,0,0,0,0,0,0,0,0,0,0,0,0,0,0,0,0,0,0,0,0,0,0,0,0,0,0,0,0,0,0,0,0,0,0,0,0,0,0,0,0,0,0,0,0,0,0,0,0,0,0,0,0,0,0,0,0,0,0,0,0,0,0,0,0,0,0,0,0,0,0,0,0,0,0,0,0,0,0,0,0,0,0,0,0,0,0,0,0,0,0,0,0,0,0,0,0,0,0,0,0,0,0,0,0,0,0,0,0,0,0,0,0,0,0,0,0,0,0,0,0,0,0,0,0,0,0,0,0,0,0,0,0,0,0,0,0,0,0,0,0,0,0,0,0,0,0,0,0,0,0,0,0,0,0,0,0,0,0,0,0,0,0,0,0,0,0,0,0,0,0,0,0,0,0,0,0,0,0,0,0,0,0,0,0,0,0,0,0,0,0,0,0,0,0,0,0,0,0,0,0,0,0,0,0,0,0,0,0,0,0,0,0,0,0,0,0,0,0,0,0,0,0,0,0,0,0,0,0,0,0,0,0,0,0,0,0,0,0,0,0,0,0,0,0,0,0,0,0,0,0,0,0,0,0,0,0,0,0,0,0,0,0,0,0,0,0,0,0,0,0,0,0,0,0,0,0,0,0,0,0,0,0,0,0,0,0,0,0,0,0,0,0,0,0,0,0,0,0,0,0,0,0,131,217,97,66,182,104,101,194,0,0,0,0,0,0,0,0,6,142,142,195,229,54,143,67,0,0,0,0,0,0,0,0,25,224,153,66,217,51,154,194,0,0,0,0,0,0,0,0,142,36,105,194,199,63,110,66,0,0,0,0,0,0,0,0,206,73,250,193,138,69,249,65,0,0,0,0,0,0,0,0,123,173,127,66,20,116,128,194,0,0,0,0,0,0,0,0,49,65,49,64,205,213,107,192,0,0,0,0,0,0,0,0,189,250,179,194,164,98,180,66,0,0,0,0,0,0,0,0,96,182,197,67,155,71,197,195,0,0,0,0,0,0,0,0,0,0,0,0,0,0,0,0,0,0,0,0,0,0,0,0,9,0,2,0,0,0,0,0,0,0,0,0,0,0,0,0,0,0,0,0,0,0,0,0,0,0,0,0,0,0,0,0,0,0,0,0,0,0,0,0,0,0,0,0,0,0,0,0,0,0,0,0,0,0,0,0,0,0,0,0,0,0,0,0,0,0,0,0,0,0,0,0,0,0,0,0,0,0,0,0,0,0,0,0,0,0,0,0,0,0,0,0,0,0,0,0,0,0,0,0,0,0,0,0,0,0,0,0,0,0,0,0,0,0,0,0,0,0,0,0,0,0,0,0,0,0,0,0,0,0,0,0,0,0,0,0,0,0,0,0,0,0,0,0,0,0,0,0,0,0,0,0,0,0,0,0,0,0,0,0,0,0,0,0,0,0,0,0,0,0,0,0,0,0,0,0,0,0,0,0,0,0,0,0,0,0,0,0,0,0,0,0,0,0,0,0,0,0,0,0,0,0,0,0,0,0,0,0,0,0,0,0,0,0,0,0,0,0,0,0,0,0,0,0,0,0,0,0,0,0,0,0,0,0,0,0,0,0,0,0,0,0,0,0,0,0,0,0,0,0,0,0,0,0,0,0,0,0,0,0,0,0,0,0,0,0,0,0,0,0,0,0,0,0,0,0,0,0,0,0,0,0,0,0,0,0,0,0,0,0,0,0,0,0,0,0,0,0,0,0,0,0,0,0,0,0,0,0,0,0,0,0,0,0,0,0,0,0,0,0,0,0,0,0,0,0,0,0,0,0,0,0,0,0,0,0,0,0,0,0,0,0,0,0,0,0,0,0,0,0,0,0,0,0,0,0,0,0,0,0,0,0,0,0,0,0,0,0,0,0,0,0,0,0,0,0,0,0,0,0,0,0,0,0,0,0,0,0,0,0,0,0,0,0,0,0,0,0,0,0,0,0,0,0,0,0,0,0,0,0,0,0,0,0,0,0,0,0,0,185,28,179,73,64,25,141,76,223,26,138,76,222,207,133,76,87,134,164,75,23,127,159,75,166,9,155,75,94,120,170,73,9
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

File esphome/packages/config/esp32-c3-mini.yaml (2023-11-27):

substitutions:
  buzzer_pin: A0
  i2s_bclk_pin: A1
  i2s_din_pin: "${buzzer_pin}"
  i2s_lrclk_pin: A5
  pir_pin: A4
  rgb_led_pin: GPIO7
  rgb_led_type: GRB
  sen0395_io_pin: A2
  uart_rx_pin: GPIO20
  uart_tx_pin: GPIO21

esphome:
  platformio_options:
    board_build.extra_flags:
      - "-DARDUINO_USB_CDC_ON_BOOT=0"
    board_build.flash_mode: dio

esp32:
  board: lolin_c3_mini
  variant: ESP32C3

wifi:
  output_power: 8.5dBm

i2c:
  sda: GPIO8
  scl: GPIO10

sensor:
  - platform: internal_temperature
    name: "CPU Temperature"

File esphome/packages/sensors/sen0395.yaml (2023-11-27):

uart:
  id: uart_bus
  tx_pin: "${uart_tx_pin}"
  rx_pin: "${uart_rx_pin}"
  baud_rate: 115200

dfrobot_sen0395:
  uart_id: uart_bus

binary_sensor:
  - platform: gpio
    name: "mmWave"
    id: motion_mmwave
    device_class: occupancy
    pin:
      number: "${sen0395_io_pin}"
      mode: INPUT_PULLDOWN

switch:
  - platform: dfrobot_sen0395
    name: "mmWave Sensor"
    type: sensor_active

  - platform: dfrobot_sen0395
    name: "mmWave Presence Via Uart"
    type: presence_via_uart
    disabled_by_default: true

  - platform: dfrobot_sen0395
    name: "mmWave Autostart"
    type: start_after_boot
    disabled_by_default: true

  - platform: dfrobot_sen0395
    name: "mmWave LED"
    type: turn_on_led

number:
  - platform: template
    name: "mmWave Sensitivity"
    id: mmwave_sensitivity
    entity_category: config
    min_value: 0
    max_value: 9
    initial_value: 7
    optimistic: true
    step: 1
    restore_value: true

  - platform: template
    name: "mmWave Off Latency"
    id: mmwave_off_latency
    entity_category: config
    min_value: 0
    max_value: 60
    initial_value: 10
    optimistic: true
    step: 0.025
    restore_value: true
    unit_of_measurement: s
    mode: box

  - platform: template
    name: "mmWave On Latency"
    id: mmwave_on_latency
    entity_category: config
    min_value: 0
    max_value: 60
    initial_value: 2.5
    optimistic: true
    step: 0.025
    restore_value: true
    unit_of_measurement: s
    mode: box

  - platform: template
    name: "mmWave Segment 1 Begin"
    id: mmwave_segment_1_begin
    entity_category: config
    min_value: 0
    max_value: 9
    initial_value: 0
    optimistic: true
    step: 0.15
    restore_value: true
    unit_of_measurement: m
    mode: BOX

  - platform: template
    name: "mmWave Segment 1 End"
    id: mmwave_segment_1_end
    entity_category: config
    min_value: 0
    max_value: 9
    initial_value: 3
    optimistic: true
    step: 0.15
    restore_value: true
    unit_of_measurement: m
    mode: BOX

  - platform: template
    name: "mmWave Segment 2 Begin"
    id: mmwave_segment_2_begin
    entity_category: config
    min_value: 0
    max_value: 9
    initial_value: 0
    optimistic: true
    step: 0.15
    restore_value: true
    unit_of_measurement: m
    mode: BOX

  - platform: template
    name: "mmWave Segment 2 End"
    id: mmwave_segment_2_end
    entity_category: config
    min_value: 0
    max_value: 9
    initial_value: 0
    optimistic: true
    step: 0.15
    restore_value: true
    unit_of_measurement: m
    mode: BOX

  - platform: template
    name: "mmWave Segment 3 Begin"
    id: mmwave_segment_3_begin
    entity_category: config
    min_value: 0
    max_value: 9
    initial_value: 0
    optimistic: true
    step: 0.15
    restore_value: true
    unit_of_measurement: m
    mode: BOX

  - platform: template
    name: "mmWave Segment 3 End"
    id: mmwave_segment_3_end
    entity_category: config
    min_value: 0
    max_value: 9
    initial_value: 0
    optimistic: true
    step: 0.15
    restore_value: true
    unit_of_measurement: m
    mode: BOX

  - platform: template
    name: "mmWave Segment 4 Begin"
    id: mmwave_segment_4_begin
    entity_category: config
    min_value: 0
    max_value: 9
    initial_value: 0
    optimistic: true
    step: 0.15
    restore_value: true
    unit_of_measurement: m
    mode: BOX

  - platform: template
    name: "mmWave Segment 4 End"
    id: mmwave_segment_4_end
    entity_category: config
    min_value: 0
    max_value: 9
    initial_value: 0
    optimistic: true
    step: 0.15
    restore_value: true
    unit_of_measurement: m
    mode: BOX

  - platform: template
    name: "mmWave Segments"
    id: mmwave_segments
    entity_category: config
    min_value: 1
    max_value: 4
    initial_value: 1
    optimistic: true
    step: 1
    restore_value: true
    mode: SLIDER
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

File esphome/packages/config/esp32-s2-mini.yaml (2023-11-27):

substitutions:
  buzzer_pin: GPIO9
  i2s_bclk_pin: GPIO7
  i2s_din_pin: "${buzzer_pin}"
  i2s_lrclk_pin: GPIO12
  led_invert: "true"
  led_pin: GPIO15
  pir_pin: GPIO11
  sen0395_io_pin: GPIO5
  uart_rx_pin: GPIO37
  uart_tx_pin: GPIO39

esp32:
  board: esp32-s2-saola-1
  variant: ESP32S2
  framework:
    type: arduino

i2c:
  sda: GPIO33
  scl: GPIO35

sensor:
  - platform: internal_temperature
    name: "CPU Temperature"

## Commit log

2022-11-07 first release
    [all-in-one-sensor.kicad_pcb, all-in-one-sensor.kicad_sch]
2022-11-08 closes #3: m3 mounting holes
    [all-in-one-sensor.kicad_pcb, all-in-one-sensor.kicad_sch]
2022-11-24 all-in-one-sensor is now AIOsense
    added: additional I²C socket (closes #7)
    added: logo & qr code (closes #5)
    added: microphone support (closes #6)
    added: schematic
    changed: the BH1750 socket is now a generic I²C socket
    fixed: PIR motion triggers onboard LED (fixes #1)
    [AIOsense.kicad_pcb, AIOsense.kicad_sch, all-in-one-sensor.kicad_pcb]
2022-11-25 fixed: kicad paths in gitignore
2022-11-25 added: pin header for HLK-LD2410 (closes #10) fixed: labeling of first the Generic I²C
    [AIOsense.kicad_pcb, AIOsense.kicad_sch]
2022-11-25 updated: schematic and date
    [AIOsense.kicad_pcb, AIOsense.kicad_sch]
2022-11-25 added: qrcode (#5)
    [AIOsense.kicad_pcb]
2022-11-27 PCB review changes fixed: via size fixed: capacitor is now SMD and closer to the BME chips fixed: position of the HLK socket removed: unnecessary capacitor removed: unnecessary resistors
    [AIOsense.kicad_pcb, AIOsense.kicad_sch]
2022-11-29 changed: switch to SMD (closes #12)
    [AIOsense.kicad_pcb, AIOsense.kicad_sch]
2022-11-29 added: config for esp32 c3 mini
    removed: generic esp32 file
2022-12-01 changed: back to THT resistors (closes #12)
    [AIOsense.kicad_pcb, AIOsense.kicad_sch]
2022-12-02 changed: PCB size reduced changed: PIR pin labels increased: via size to 0.4mm (min)
    [AIOsense.kicad_pcb, AIOsense.kicad_sch]
2022-12-02 updated: date on schematic
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2022-12-02 fixed: PIR label is not in the center of the ESP
    [AIOsense.kicad_pcb]
2022-12-02 changed: mounting holes now are grounded
    [AIOsense.kicad_pcb, AIOsense.kicad_sch]
2022-12-02 fixed: top corners
    [AIOsense.kicad_pcb]
2022-12-03 fixed: some layout fixes
    [AIOsense.kicad_pcb]
2022-12-16 fixed: PIR sensor pin
2022-12-20 fixed: PIR is now in the center and does not block the mmWave
    [AIOsense.kicad_pcb]
2022-12-31 updated: images & schematic
2022-12-31 moved the ESP closer to the edge
    [AIOsense.kicad_pcb, AIOsense.kicad_sch]
2022-12-31 fixed: Sensor Modules link
2023-01-03 Added STL and STEP case models for v1.0.
    [bottom.stl, case.step, stand.stl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]
2023-01-05 Updated top component to shorten pins
    [bottom.stl, top.stl]
2023-01-05 Added fillet to bottom hole edge for fit
2023-01-05 Updated step file to mirror changes in top/bottom
    [case.step]
2023-01-10 Updated model to correct problems from test print
    Improved side hole to allow cable access for C3 Mini and similar form factor modules. Reworked stand mount attachment to use M3 hex nuts and 8mm countersunk M3 screws to secure mount to the case bottom. Reworked system to connect top and bottom portions of the case, using raised wedges instead of snaps. PCB is now mounted to the case bottom using 4 self-tapping M3 screws.
    [bottom.stl, stand.stl, top.stl]
2023-01-11 fixed IO labeling (closes #17)
    [AIOsense.kicad_pcb]
2023-01-19 added: support for bluetooth_proxy for the esp32-c3
2023-01-21 added: info about the power consumption
2023-01-21 changed: PIR-Jumper removed & port labels changed
    [AIOsense.kicad_pcb, AIOsense.kicad_sch]
2023-01-21 changed: power pins replaced with terminal block (closes #18)
    [AIOsense.kicad_pcb, AIOsense.kicad_sch]
2023-01-23 Added ESPHome yaml config for generic ESP32 D1 Mini
2023-01-23 Added MH-ET Live as commented out option for board.
2023-01-23 Updated part numbers for as many parts as possible for Mouser, Farnell, Digikey (and the HiLink LD2410 with Aliexpress Link)
    [AIOsense.kicad_pcb, AIOsense.kicad_sch]
2023-01-28 fixed: footprint for LD2410
    [AIOsense.kicad_pcb, AIOsense.kicad_sch]
2023-01-30 added: control for ESP32C3 onboard LED
2023-01-30 fixed: PIR pin since PIR changes
    [esp32-c3-mini.yaml, esp32-s2-mini.yaml]
2023-01-30 added: 3s green LED while booting
2023-01-30 added: 3s LED while booting (no green, because does not work)
    [esp32-c3-mini.yaml]
2023-01-31 restored group id e453a6cb-b766-40db-b5bd-4a4b5cdf469d
    [AIOsense.kicad_pcb]
2023-02-13 migration to kicad 7.0
    [AIOsense.kicad_pcb, AIOsense.kicad_sch]
2023-02-15 Add LCSC part number for JLCPCB SMT services.
    [AIOsense.kicad_sch]
2023-03-07 fixed typo - it's not "pulluted" but "polluted"
    [esp32-c3-mini.yaml]
2023-03-15 added missing bsec config (fixes #43)
    [esp32-c3-mini.yaml, esp32-s2-mini.yaml]
2023-03-19 closes #47 - new light for esp32 d1 mini that is trigerred on boot
2023-03-28 release of v2.0.0
    [AIOsense.kicad_pcb, AIOsense.kicad_sch]
2023-03-29 fixed: BME header pin orientation (closes #55)
    [AIOsense.kicad_pcb, AIOsense.kicad_sch]
2023-03-29 moved case files to v1.0 sub dir (related to #57)
    [bottom.stl, case.step, stand.stl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]
2023-03-29 swapped GND and SDA at the IO port
    because of kicad connectivity warnings
    [AIOsense.kicad_pcb, AIOsense.kicad_sch]
2023-03-29 changed: kicad default text width to fix some warnings
    [AIOsense.kicad_pcb]
2023-04-04 added: RTTTL Buzzer (closes #32)
    [AIOsense.kicad_pcb, AIOsense.kicad_sch]
2023-04-04 added: own PIR footprint
    the PIR is now centered
    [AIOsense.kicad_pcb, AIOsense.kicad_sch]
2023-04-04 fixed: kicad error caused by old library
2023-04-04 added: 3D image for buzzer
    [AIOsense.kicad_pcb, AIOsense.kicad_sch]
2023-04-04 added: step files for PIR an socket
    [AIOsense.kicad_pcb]
2023-04-23 added: BOM (#48)
    [v2.0.x.ods]
2023-04-23 Change resistors from THT to SMD and add LCSC references (#65)
    #12
    [AIOsense.kicad_pcb, AIOsense.kicad_sch]
2023-04-23 changed: resistors footprint to handsolder
    [AIOsense.kicad_pcb, AIOsense.kicad_sch]
2023-04-23 added: support for HLK-LD2410C (#33)
    [AIOsense.kicad_pcb, AIOsense.kicad_sch]
2023-04-23 fixed: BOM links
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2023-04-23 release 2.1.0-rc1
    [AIOsense.kicad_pcb, AIOsense.kicad_sch, v2.1.x.ods]
2023-04-24 added: sensors for wifi signal and status
2023-05-02 added: safe_mode & cpu temperature
2023-05-10 added: 3d printable case (closes #9)
2023-05-16 fixed: led invert for ESP8266 (#78)
2023-05-16 fixed: PIR pin mode for ESP8266 (#78)
2023-05-16 fixed: CPU Temperature sensor only for ESP8266 (#78)
    [esp32-c3-mini.yaml, esp32-s2-mini.yaml]
2023-06-01 feat(case): Files for the upright stand mount (#80)
    [case_upright_stand.blend, case_upright_stand.stl]
2023-06-16 fixed: s2 config (fixes #79) (#82)
    [esp32-s2-mini.yaml]
2023-06-20 release: 2.1.0
    [AIOsense.kicad_pcb, AIOsense.kicad_sch]
2023-06-26 fixed: added mmWave to BOM
    [v2.1.x.ods]
2023-07-21 hanging restore_state to restore_mode (fixes #95)
    [sen0395.yaml]
2023-08-03 Add effects to RGB LED (#102)
2023-10-24 adding default temperature offset
2023-11-15 bump s3 framework version
2023-11-15 fixing S3 led colors
    [esp32-s3-mini.yaml]
2023-11-15 fixing S3 led type
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2023-11-27 add support for voice assistant with single color leds
2023-11-27 chore(deps): update dependency mkdocs-material to v9.4.14
2023-11-28 chore(deps): update dependency mkdocs-material-extensions to v1.3.1 (#135)
2023-12-07 chore(deps): update dependency mkdocs-material to v9.5.0 (#147)
2023-12-08 chore(deps): update dependency mkdocs-material to v9.5.1 (#148)
2023-12-11 chore(deps): update dependency mkdocs-material to v9.5.2 (#150)
2023-12-21 Initial PCB V3.0.0 commit
    Complete redrawing to improve airflow for BME680/280, remove SMD components, and reduce via count to one. Ready for review.
    Added direct support for:
    - LD2450 support (#92)
    - Speaker (#74, #129)
    - MICs (#131)
    Added additional AUX IO for:
    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
    [AIOsense.kicad_pcb, AIOsense.kicad_sch]
2023-12-22 Move GY-302
    [AIOsense.kicad_pcb, AIOsense.kicad_sch]
2023-12-24 chore(deps): update dependency mkdocs-material to v9.5.3 (#154)
2024-01-15 chore(deps): update dependency mkdocs-material to v9.5.4 (#164)
2024-01-24 chore(deps): update dependency mkdocs-material to v9.5.5 (#166)
2024-01-28 chore(deps): update dependency mkdocs-material to v9.5.6 (#167)
2024-01-28 Bring back sensor IO positions from V2.1
    All active sensor IO locations are now the same as V2. Audio and AUX IO are still different in order to preserve a reasonable PCB layout
    [AIOsense.kicad_pcb, AIOsense.kicad_sch]
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2024-03-14 fix pcb version number
    [AIOsense.kicad_pcb, AIOsense.kicad_sch]
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2025-01-28 fix: amp swapped terminal label (#288 & #132)
    [AIOsense.kicad_pcb]
2025-01-29 Added pcb-3.0 case draft. Included adjustable wall mount.
    [ball.stl, ball_base.stl, bottom.stl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]
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

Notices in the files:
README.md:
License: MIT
